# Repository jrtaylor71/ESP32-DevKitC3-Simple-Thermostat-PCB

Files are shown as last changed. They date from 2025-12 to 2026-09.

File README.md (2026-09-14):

# ESP32-S3-Simple-Thermostat

A comprehensive, feature-rich simple thermostat system built on the ESP32 platform with professional PCB design. Perfect for DIY smart home automation with full Home Assistant integration.

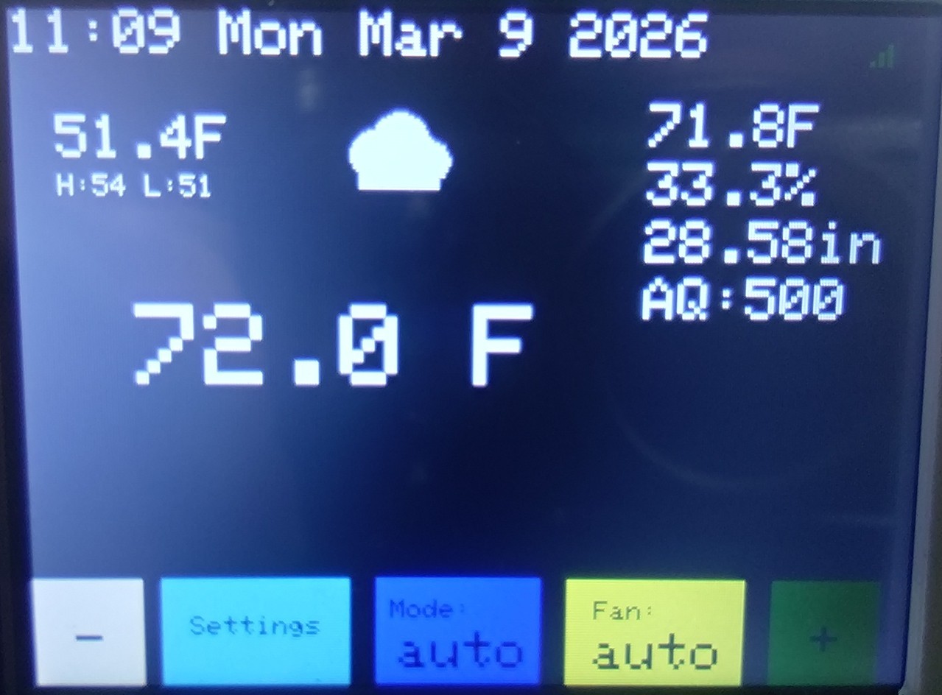
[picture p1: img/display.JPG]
Main-Display

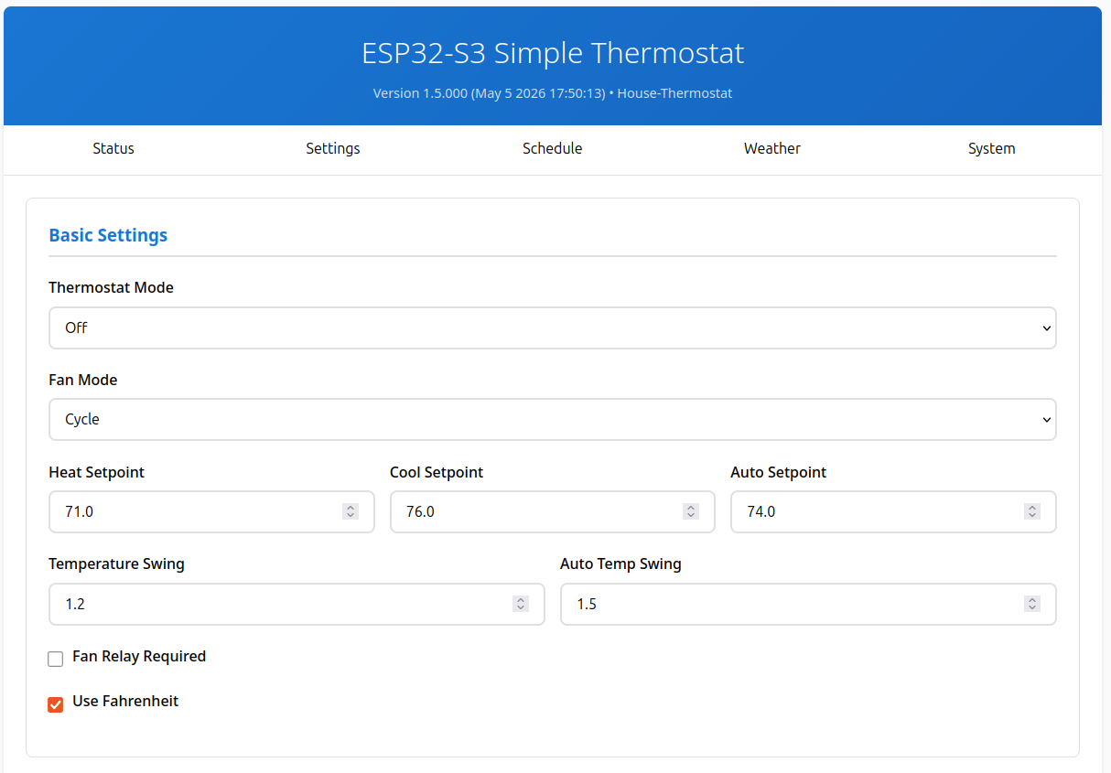
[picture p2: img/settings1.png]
Settings1

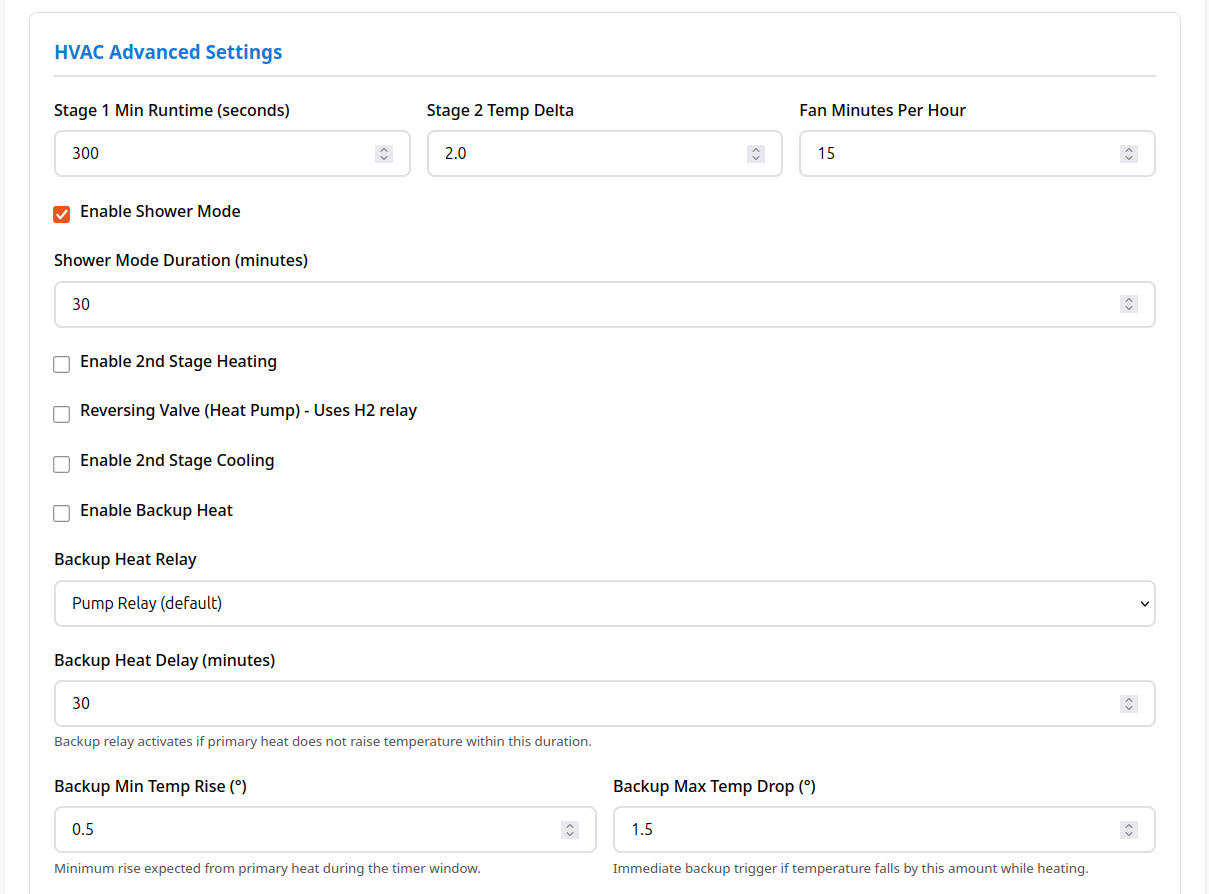
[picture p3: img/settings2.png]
Settings2

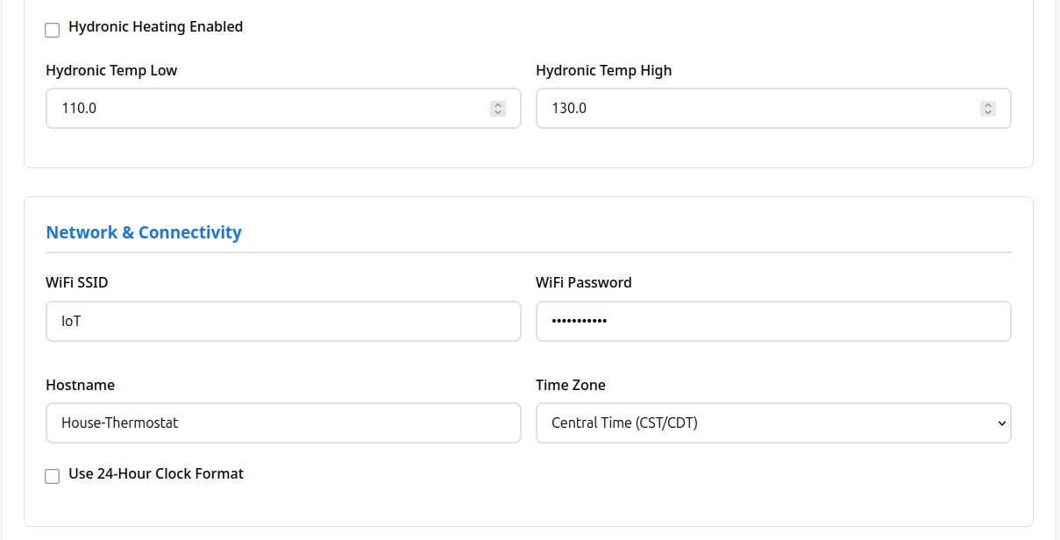
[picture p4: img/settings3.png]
Settings3

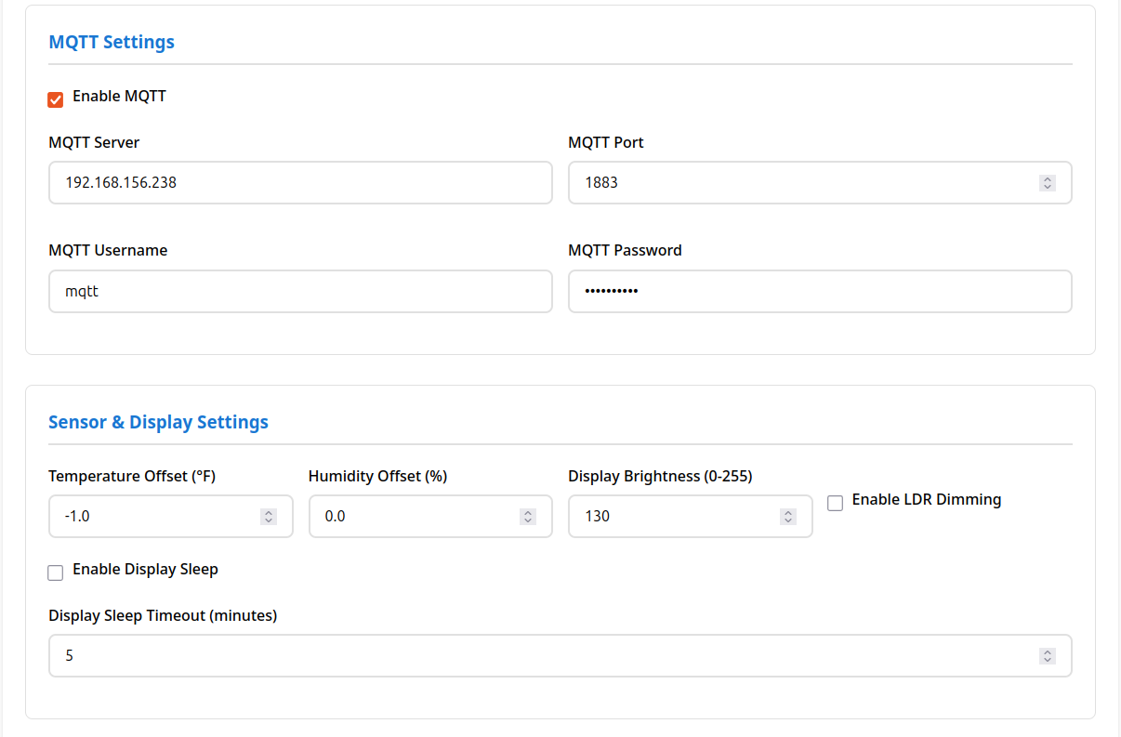
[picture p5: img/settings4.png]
Settings4


## 🌟 Key Features

- **📱 Local Touch Control**: ILI9341 TFT LCD with intuitive touch interface
- **🏠 Smart Home Ready**: Full MQTT integration with Home Assistant auto-discovery and climate entity support
- **📅 Bidirectional Schedule Sync**: 7-day schedules with day/night periods, HA helper automation, and live two-way update flow
- **🌡️ Multiple Sensors**: AHT20/BME280 ambient temperature and humidity plus DS18B20 hydronic water sensing
- **⚡ Multi-Stage HVAC**: Support for 2-stage heating and cooling, stage timing, delta thresholds, and stage 2 runtime logic
- **🌍 Regional HVAC Behavior**: Switchable US mode (standard temperature-driven cooling) or EU mode (adds optional humidity-driven dehumidification support alongside temperature control)
- **🔄 Heat Pump Ready**: Reversing valve support and heat-pump-compatible staging logic
- **🔥 Backup Heat Monitoring**: Auxiliary heat fallback logic with delay windows and temperature-drop detection
- **💨 Advanced Fan Control**: Auto, continuous, and scheduled cycling modes with independent heat/cool fan relay requirements
- **🔥 Separate Heat/Cool Fan Logic**: Configure whether the fan relay is needed for heating, cooling, or both for legacy HVAC systems
- **🧯 Hydronic Safety Protection**: DS18B20 water monitoring with lockout logic that blocks unsafe fan/heating operation and protects radiant systems
- **🚿 Shower Mode**: Pause heating for 5-120 minutes with countdown timer and buzzer alert
- **🌤️ Weather Integration**: OpenWeatherMap and Home Assistant weather with color-coded icons, current conditions, and display updates
- **🏢 Multi-Thermostat Support**: Scale from single-device installs to multi-device Home Assistant automation setups
- **🌐 Modern Web Interface**: Complete tabbed interface with embedded scheduling, status monitoring, OTA upload, and settings management
- **📡 Offline Operation**: Full functionality without WiFi connection or internet access
- **🔧 Professional PCB**: Custom PCB design for clean, permanent installation and compact integration
- **🔄 OTA Updates**: Over-the-air firmware updates with real-time progress tracking and reboot recovery
- **🔒 Factory Reset**: Built-in reset capability via boot button for clean default recovery
- **🎭 Motion Detection**: LD2410 24GHz mmWave sensor for automatic display wake and occupancy-aware screen behavior
- **🔊 Audible Alerts**: Buzzer feedback for shower mode, relay events, and user interaction cues
- **🧠 Reliability Features**: Watchdog reset, anti-flicker display refresh, I2C protection, and graceful sensor recovery

## �️ Operating Modes

### Thermostat Modes
- **Off**: All heating, cooling, and fan demand relays are disabled
- **Heat**: Single heat setpoint with configurable swing (hysteresis) to prevent short-cycling
- **Cool**: Single cool setpoint with configurable swing (hysteresis) to prevent short-cycling
- **Auto**: Single setpoint with a wider dead-zone swing; heating and cooling only activate once the temperature moves outside the dead-zone and turn off at the setpoint boundary rather than immediately on dead-zone re-entry

### Fan Modes
- **Auto**: Fan runs only when heating or cooling demand is active, based on the independent heat/cool fan relay requirement settings
- **On**: Fan runs continuously regardless of HVAC demand
- **Cycle**: Fan runs on a repeating schedule (configurable minutes per hour) even without active heating or cooling demand

### Regional HVAC Modes
- **US Mode**: Standard temperature-driven heating and cooling control
- **EU Mode**: Adds an optional humidity-driven dehumidification assist that runs alongside temperature control, using a configurable humidity setpoint, deadband, and dedicated relay selection

### Schedule Modes
- **Scheduled**: Setpoints automatically follow the active day/night period for the current day of week
- **Manual Override**: Adjusting a setpoint while a schedule is active temporarily overrides the schedule for a fixed duration before resuming normal scheduled behavior
- **Disabled**: Schedule following can be turned off entirely in favor of fixed manual setpoints

### Shower Mode
- Temporarily pauses heating for a configurable duration (5-120 minutes)
- Displays a live countdown timer on the touch screen while active
- Buzzer alert signals when the countdown is about to end
- Can be toggled directly from the touch screen setpoint control when enabled in settings

## �🚀 Quick Start

 - PCB V1.x
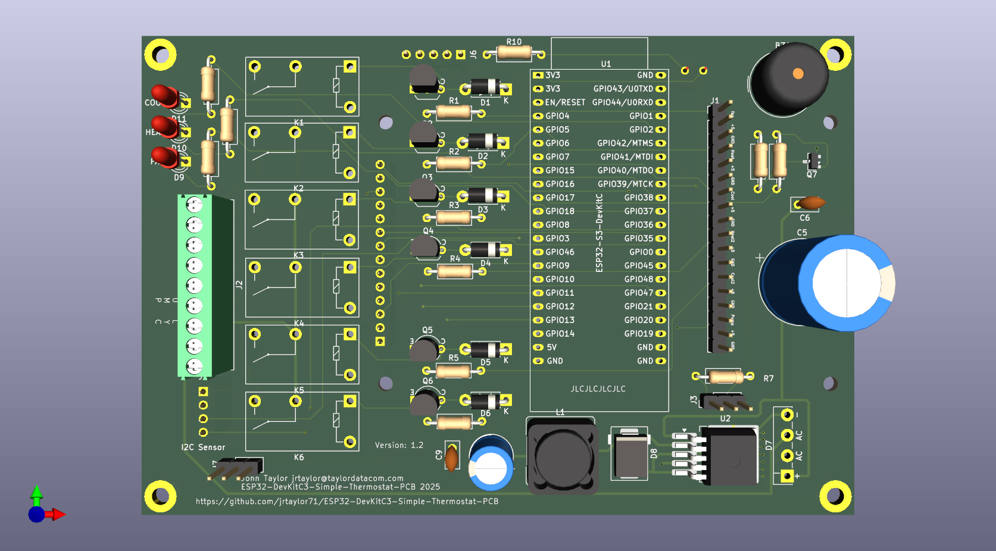
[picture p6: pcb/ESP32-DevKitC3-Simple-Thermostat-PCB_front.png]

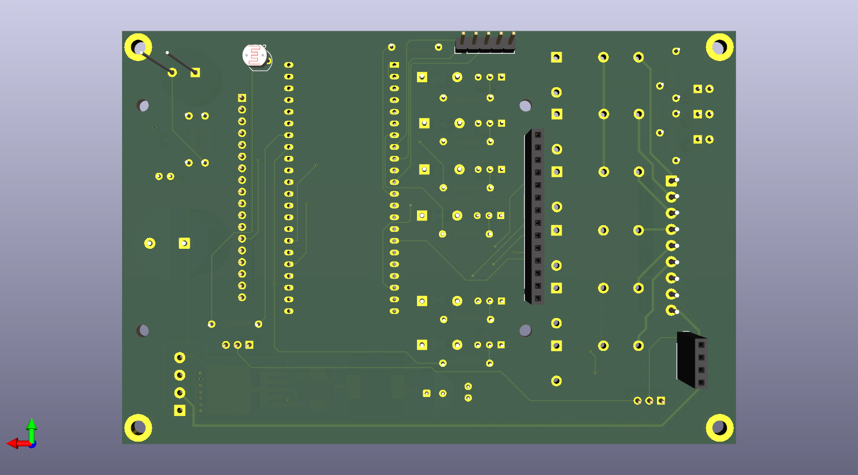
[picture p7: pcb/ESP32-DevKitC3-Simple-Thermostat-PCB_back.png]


 - PCB V3.x
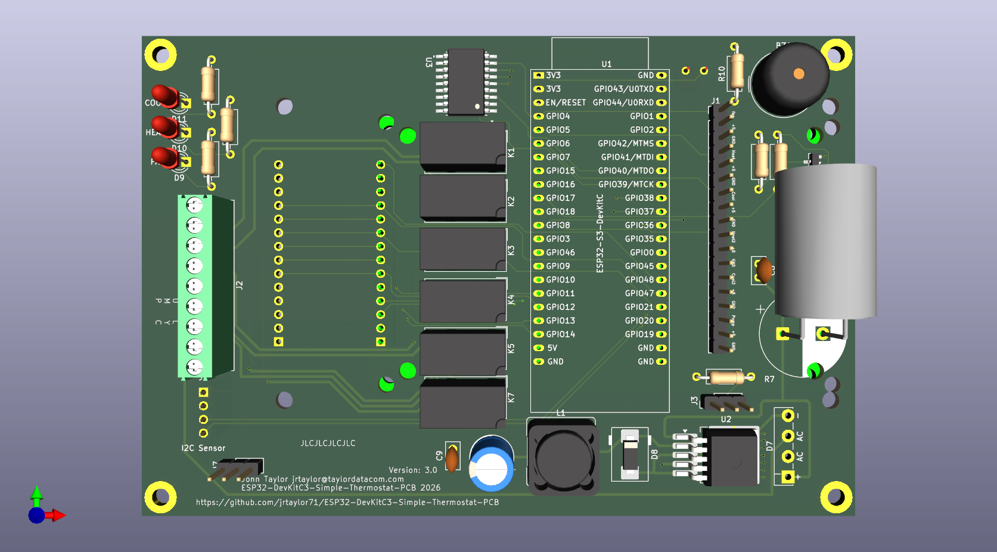
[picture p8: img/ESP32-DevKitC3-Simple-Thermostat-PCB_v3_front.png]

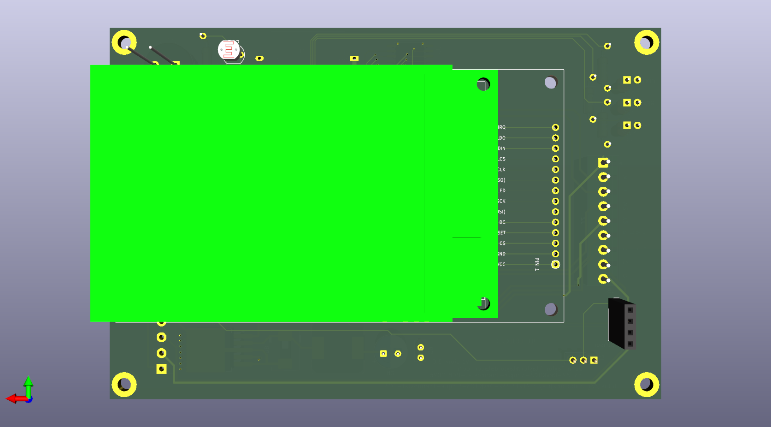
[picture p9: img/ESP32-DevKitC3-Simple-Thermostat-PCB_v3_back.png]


### Hardware Requirements
- ESP32-S3-WROOM-1-N16 (16MB Flash, No PSRAM) or N8/N32 variants
- ILI9341 320x240 TFT LCD with XPT2046 Touch Controller
- AHT20 or BME280 Temperature/Humidity Sensor (I2C)
- DS18B20 Temperature Sensor (optional, for hydronic heating)
- LD2410 24GHz mmWave Motion Sensor (optional, for display wake)
- 5x Relay Module for HVAC control
- Custom PCB that can use either onboard relay or external relays via pin header

### Software Setup

#### Option 1: Use Prebuilt Firmware (Recommended)
1. Clone this repository
2. Navigate to `firmware/` directory
3. Find the latest build folder (e.g., `build_YYYYMMDD-HHMMSS/`)
4. Flash using the variant-specific script:
   - **Linux/Mac**: 
     - Default: `./latest_flash_N16.sh` (uses /dev/ttyACM0)
     - Custom port: `./latest_flash_N16.sh /dev/ttyUSB0`
   - **Windows**: 
     - Default: `latest_flash_N16.bat` (uses COM3)
     - Custom port: `latest_flash_N16.bat COM4`
5. Use touch interface to configure WiFi and settings

#### Option 2: Build from Source
1. Install [PlatformIO](https://platformio.org/) IDE
2. Clone this repository
3. Open project in PlatformIO
4. Build firmware using `./build.sh` with options:
   - **Interactive mode**: `./build.sh` (select from menu)
   - **Specific variant**: `./build.sh 1` (N8), `./build.sh 2` (N16), or `./build.sh 3` (N32)
   - **All variants**: `./build.sh all` or `./build.sh 4`
   - **Additional flags**: `clean`, `quiet`, `cleanlibs`
   - **Examples**: 
     - `./build.sh 2` - Build 16MB variant (default)
     - `./build.sh all clean` - Clean build all variants
     - `./build.sh 3 quiet` - Build 32MB silently
     - `./build.sh cleanlibs` - Remove all libraries and packages
5. Memory usage: RAM 25.2% (82728/327680 bytes); Flash 19.0% (1246KB/6553KB for N16)
6. Firmware organized in `firmware/N8/`, `firmware/N16/`, `firmware/N32/` directories
7. Flash using variant-specific scripts:
   - **Linux/Mac**: 
     - Default: `./firmware/latest_flash_N16.sh` (uses /dev/ttyACM0)
     - Custom port: `./firmware/latest_flash_N16.sh /dev/ttyUSB0`
   - **Windows**: 
     - Default: `firmware\latest_flash_N16.bat` (uses COM3)
     - Custom port: `firmware\latest_flash_N16.bat COM5`
8. Use touch interface to configure WiFi and settings

#### Flashing Requirements
- **esptool.py** (installed automatically with PlatformIO)
- **USB connection** to ESP32-S3
- **Boot mode**: Hold BOOT button while connecting USB (if needed)
- **Default serial port**: `/dev/ttyACM0` (Linux/Mac) or `COM3` (Windows)

#### Manual Flashing with esptool

If you need to flash manually using esptool, use the following command:

**Linux/Mac:**
```bash
esptool.py --chip esp32s3 --port /dev/ttyACM0 --baud 460800 --before default_reset --after hard_reset write_flash -z \
    --flash_mode dio --flash_freq 80m --flash_size 16MB \
    0x0 bootloader.bin \
    0x8000 partitions.bin \
    0x10000 firmware.bin
```

**Windows:**
```bash
esptool.py --chip esp32s3 --port COM3 --baud 460800 --before default_reset --after hard_reset write_flash -z \
    --flash_mode dio --flash_freq 80m --flash_size 16MB \
    0x0 bootloader.bin \
    0x8000 partitions.bin \
    0x10000 firmware.bin
```

**Flash addresses for the 3 required files:**
- `bootloader.bin` at address `0x0`
- `partitions.bin` at address `0x8000`
- `firmware.bin` at address `0x10000`

**Adjust for your hardware:**
- Change `--port` to your serial port (Linux: `/dev/ttyACM0` or `/dev/ttyUSB0`, Windows: `COM3`, `COM4`, etc.)
- Change `--flash_size` to `8MB`, `16MB`, or `32MB` to match your ESP32-S3 variant (N8, N16, or N32)

For detailed build and flash instructions, see [USER_MANUAL.md](USER_MANUAL.md)

## 💻 Web Interface

Access the thermostat's web interface by navigating to its IP address:

### Tabbed Interface with Embedded Features

**Status Tab**: Real-time monitoring of:
- Current temperature and humidity
- Thermostat and fan modes
- Relay states and system status
- Weather information (when configured)
- Barometric pressure (with BME280 sensor)

**Settings Tab**: Complete configuration interface for:

- Temperature setpoints and control modes
- MQTT/Home Assistant integration and broker settings
- WiFi network settings and reboot recovery
- Multi-stage HVAC parameters including stage 2 runtime and delta thresholds
- Reversing valve configuration for heat-pump systems
- Backup heat enablement, relay selection, delay timing, and temperature-drop logic
- Hydronic heating controls with low/high water protection thresholds
- Fan scheduling options and independent heat/cool fan relay toggles
- Regional HVAC mode selection for US or EU behavior
- EU humidity dehumidification controls, relay selection, setpoint, and deadband
- Shower mode enable/disable and duration (5-120 minutes)
- Display brightness, sleep, and clock settings
- Temperature/humidity sensor calibration and offsets
- OTA update management and firmware details

**Schedule Tab**: Comprehensive 7-day scheduling:
- Day and night periods for each day of the week
- Editable Heat, Cool, and Auto temperatures for each period
- Time controls for period transitions
- Schedule enable/disable and override controls
- All options always visible - no hidden menus

**Weather Tab**: Weather data configuration:
- OpenWeatherMap API integration
- Home Assistant weather entity integration
- Configurable update intervals (5-60 minutes)
- City/state/country configuration

**System Tab**: Device information and firmware updates:
- System information and uptime
- Firmware version details
- OTA firmware upload with progress tracking
- Reboot and factory reset options

For complete usage instructions, see [USER_MANUAL.md](USER_MANUAL.md)

## 🏠 Home Assistant Integration

### Automatic Discovery & Control
Automatic discovery and integration with Home Assistant:

1. Enable MQTT in thermostat settings
2. Configure MQTT broker details
3. Thermostat appears automatically in Home Assistant with a full climate entity and status payloads
4. Full control via Home Assistant interface
5. Supports climate entity with heating, cooling, auto, and off modes
6. Publishes relay, mode, target, schedule override, and hydronic state for automation use

### Bidirectional Schedule Sync 🔄
Full synchronization between thermostat and Home Assistant:

**Device → HA (Inbound)**: 
- Thermostat publishes complete schedule on boot and config changes
- HA automations automatically update helper entities for each day and period
- Changes made on device instantly visible in HA

**HA → Device (Outbound)**:
- Change any schedule helper in HA (time, temperature, enabled status)
- Automation publishes change to device via MQTT immediately
- Device receives and applies change instantly
- No manual sync needed - fully automatic bidirectional flow

**Multi-Thermostat Support**:
- Each device gets its own set of helpers (shop_thermostat, studio_thermostat, house_thermostat, etc.)
- Centralized multi-device automation handles all thermostats
- Proper hostname normalization for MQTT topics vs. helper IDs
- Can manage 10+ thermostats from single HA instance

**Setup Instructions**:
1. Ensure MQTT is enabled on thermostat
2. Copy `multi_thermostat_schedule_sync.yaml` to HA packages directory
3. Generate per-device packages: `./generate_schedule_package.sh shop_thermostat`
4. Add package to HA configuration
5. Reload automations/scripts in HA
6. Helpers auto-populate from device schedule state

## 🛠️ Advanced Features

### Multi-Stage Operation
- Intelligent staging based on time and temperature
- Configurable stage 2 activation parameters and runtime thresholds
- Prevents system short-cycling and optimizes energy efficiency
- Supports separate heating and cooling stage logic for multi-stage HVAC systems
- Includes runtime gating and dead-zone control behavior for stable operation

### US/EU Regional HVAC Behavior
- Thermostat region mode can be configured for US or EU control behavior
- **US Mode**: Standard temperature-driven heating and cooling control
- **EU Mode**: Adds optional humidity-driven dehumidification assist that runs alongside temperature control, with configurable setpoint and deadband
- Standalone dehumidification state is surfaced to web status and TFT display
- Works with relay selection modes for cooling stage 1, stage 2, or pump relay output

### Heat Pump and Backup Heat Support
- Reversing valve support for heat-pump systems with mode-aware valve control
- Backup heat logic can monitor a primary heat source and automatically add auxiliary heat when recovery stalls or temperature falls too quickly
- Relay conflicts are automatically managed so backup heat does not overlap with reserved stage 2 or reversing valve outputs
- Works alongside standard heating and cooling staging without forcing a single control strategy

### Hydronic Heating Support
- DS18B20 water temperature monitoring
- Safety interlocks prevent operation when water is too cold
- Configurable high/low temperature thresholds
- Hydronic lockout logic blocks unsafe heating/fan behavior when the loop is below the configured minimum
- Perfect for radiant floor heating systems and hydronic boiler setups

### Fan Control Options
- **Auto**: Fan runs only with heating/cooling
- **On**: Continuous fan operation
- **Cycle**: Scheduled fan operation (configurable minutes per hour)
- **Independent Heat/Cool Relay Settings**: Choose whether a fan relay is required while heating, while cooling, or for both modes
- **Legacy HVAC Compatibility**: Supports systems where the fan is required for cooling only, heating only, or both without forcing a single global setting

### Display, Sensor, and Safety Enhancements
- Motion-based wake on LD2410 radar occupancy detection
- Display sleep and dimming support with activity sensing
- Buzzer feedback for alerts, boot tones, and mode transitions
- Watchdog protection, OTA recovery, and factory reset support
- AHT20/BME280 temperature/humidity calibration offsets and sensor error recovery
- I2C mutex protection to prevent bus contention between sensors and display logic
- Anti-flicker display refresh logic and stable UI updates
- Hydronic low-temp alert publishing and lockout recovery monitoring for radiant systems

### Included Hardware and Support Features
- 5 relay outputs for heating, cooling, and fan control
- Optional DS18B20 hydronic sensor and LD2410 motion sensor
- Local TFT UI with touch controls and embedded settings
- Web interface for complete configuration and status polling
- OTA firmware upload through the device’s system tab
- Compatibility with both single-device and multi-thermostat Home Assistant installations

## 🖨️ 3D Printable Case

A professional two-part case design is included for clean wall-mount installation:

### Case Features
- **Two-part screw-retained design**: Front (display side) and back (wall-mount side) halves
- **Integrated PCB mounting**: Built-in standoffs (13mm height) for secure PCB installation
- **Countersunk front screws**: 4× M2.5 countersunk (DIN 7991), 10–12mm length, 7mm inset
- **Keyhole wall mounting**: Easy installation without removing case (83mm spacing)
- **Display opening**: Precise 50mm × 68mm opening for 3.2" ILI9341 touchscreen (rotated 90°)
- **AHT20 sensor + LDR cutouts**: 12.5×6mm rectangle (rotated 90°) and Ø5.5mm hole
- **Wire management**: 22mm back pass-through plus side ventilation slots
- **Ventilation**: Strategically placed slots for optimal heat dissipation
- **Professional finish**: Smooth surfaces and rounded edges

### Files Included
- `case/freecad_front_case.py` - Front case (display side) FreeCAD Python script
- `case/freecad_back_case.py` - Back case (wall-mount side) FreeCAD Python script
- `case/freecad_outputs/front_case_display_freecad.stl` - Front half for 3D printing
- `case/freecad_outputs/back_case_wall_freecad.stl` - Back half for 3D printing
- `case/freecad_outputs/front_case_display_freecad.FCStd` - Front case FreeCAD project
- `case/freecad_outputs/back_case_wall_freecad.FCStd` - Back case FreeCAD project
- `case/freecad_outputs/front_case_display_freecad.step` - Front case STEP format
- `case/freecad_outputs/back_case_wall_freecad.step` - Back case STEP format
- `case/freecad_outputs/CE5_front_case_display_freecad.gcode` - Creality Ender 5 gcode (front)
- `case/freecad_outputs/CE5_back_case_wall_freecad.gcode` - Creality Ender 5 gcode (back)

### Print Specifications
- **Material**: PLA or PETG recommended
- **Layer height**: 0.2mm
- **Infill**: 15-20%
- **Supports**: None required
- **Print time**: ~7–9 hours total
- **Dimensions**: 149.0mm × 105.5mm × ~47mm (assembled)
  - Front: ~17.1mm (2.5mm wall; 13mm standoffs; front walls 1.6mm above standoffs)
  - Back: ~30.1mm (2.5mm wall; 20mm component clearance; bosses/keyholes)

**STL Files Location**: All printable STL files are in the `case/freecad_outputs/` directory.

### Motion Detection
- **LD2410 24GHz mmWave Sensor**: Automatic display wake on motion detection
- **Hardware Pins**: RX=15, TX=16, Motion=18
- **Robust Detection**: Works with sensors that don't respond to UART commands
- **Home Assistant Integration**: Motion sensor auto-discovery and status publishing
- **Energy Saving**: Display automatically sleeps when no motion detected
- **Seamless Operation**: Works alongside existing touch controls

### Safety Features
- Watchdog timer prevents system lockups
- Factory reset via boot button (10+ seconds)
- Temperature limit enforcement
- Graceful offline operation

## 🔧 Factory Reset

Press and hold the boot button for more than 10 seconds while the thermostat is running to restore all settings to defaults.

## 📄 License

This project is released under the GNU General Public License v3.0. Free to use, modify, and distribute. NOT for commercial use.

## 🤝 Contributing

Contributions welcome! Please:
1. Fork the repository
2. Create a feature branch
3. Make your changes
4. Submit a pull request

## 📞 Support

- **Issues**: Use GitHub Issues for bug reports
- **Discussions**: GitHub Discussions for questions
- **Documentation**: Comprehensive docs included
- **Serial Debug**: Detailed logging at 115200 baud

## 🙏 Credits & Acknowledgments

**Firmware**: Jonn Taylor - Enhanced firmware implementation

**Created for the DIY smart home community**

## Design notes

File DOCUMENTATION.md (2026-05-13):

# Firmware - Complete Documentation

## Project Overview

The Firmware is a comprehensive, feature-rich smart thermostat system built on the ESP32-S3 platform with professional PCB design.

**Current Version**: 1.5.001 (May 2026)
**Hardware**: ESP32-S3-WROOM-1-N16 (16MB Flash)
**Architecture**: Dual-core FreeRTOS with Option C display management
**Status**: Production-ready with comprehensive testing, scheduling, weather integration, US/EU regional HVAC options, and enhanced OTA updates

### Key Features

- **Professional Dual-Core Architecture**: ESP32-S3 FreeRTOS with Core 0 for UI/networking, Core 1 for control
- **Weather Integration**: Dual-source weather (OpenWeatherMap/Home Assistant) with color-coded standard icons
- **7-Day Scheduling System**: Complete inline scheduling with day/night periods, editable Heat/Cool/Auto temperatures, and MQTT integration
- **Modern Tabbed Web Interface**: All features embedded in main page - no separate pages, always-visible options
- **Local Touch Control**: ILI9341 TFT LCD with resistive touch and adaptive brightness
- **Smart Home Integration**: Full MQTT support with Home Assistant auto-discovery, precision temperature control, and schedule status publishing
- **Advanced Sensor Suite**: AHT20 I2C sensor for ambient conditions, DS18B20 OneWire for hydronic systems
- **Intelligent Multi-Stage HVAC**: 2-stage heating/cooling with hybrid time/temperature staging logic
- **US/EU Regional HVAC Controls**: Region mode switch with EU humidity-driven dehumidification support
- **Enhanced Hydronic Safety**: Water temperature monitoring with [LOCKOUT] safety interlocks and improved alerts
- **Flexible Operation Modes**: Heat, Cool, Auto, and Off with configurable temperature swings
- **Advanced Fan Control**: Auto, On, and Cycle modes with scheduled operation (minutes per hour)
- **Anti-Flicker Display**: Cached redraw optimization eliminates time and weather flicker
- **Comprehensive Web Interface**: Real-time monitoring and complete configuration in tabbed layout
- **Robust Offline Operation**: Full functionality without WiFi connection
- **Custom PCB Design**: Professional PCB by Stefan Meisner for clean installation
- **Modern UI**: Material Design color scheme with responsive touch interface
- **Factory Reset**: 10-second boot button press for complete settings reset
- **OTA Updates**: Over-the-air firmware updates with real-time upload and flash write progress tracking

## Hardware Components

### Main Components
- **ESP32-S3-WROOM-1-N16**: Main microcontroller (16MB Flash, No PSRAM)
- **ILI9341 TFT LCD with XPT2046**: 320x240 pixel display with resistive touch controller
- **AHT20 Sensor**: I2C temperature and humidity measurement  
- **DS18B20 Sensor**: OneWire water/hydronic temperature measurement (optional)
- **LD2410 Motion Sensor**: 24GHz mmWave radar for occupancy detection and display wake
- **5x Relay Outputs**: Control for heating, cooling, and fan systems

### Pin Configuration (ESP32-S3)

#### TFT Display Connections (ILI9341 + XPT2046)
```cpp
// Current platformio.ini build_flags configuration:
#define TFT_MISO 21    // SPI MISO (shared with touch)
#define TFT_MOSI 12    // SPI MOSI (shared with touch)
#define TFT_SCLK 13    // SPI Clock (shared with touch)  
#define TFT_CS    9    // TFT Chip Select
#define TFT_DC   11    // Data/Command
#define TFT_RST  10    // Reset
#define TFT_BL   14    // Backlight (PWM controlled)
#define TOUCH_CS 47    // Touch Chip Select
#define TOUCH_IRQ 48   // Touch Interrupt
```

#### Sensor Connections
```cpp
// AHT20 I2C sensor (ESP32-S3 pins)
#define AHT20_SDA 36        // I2C SDA for AHT20
#define AHT20_SCL 35        // I2C SCL for AHT20
// DS18B20 OneWire sensor
#define ONE_WIRE_BUS 34     // DS18B20 data pin
// Light sensor for adaptive brightness
#define LIGHT_SENSOR_PIN 8  // Photocell/light sensor
```

#### Relay Outputs (ESP32-S3 GPIO)
```cpp
// GPIO pins verified for ESP32-S3 schematic
const int heatRelay1Pin = 5;    // Heat Stage 1
const int heatRelay2Pin = 7;    // Heat Stage 2  
const int coolRelay1Pin = 6;    // Cool Stage 1
const int coolRelay2Pin = 39;   // Cool Stage 2
const int fanRelayPin = 4;      // Fan Control
```

#### Status LEDs and Buzzer
```cpp
// PWM-controlled status indicators
const int ledFanPin = 37;       // Fan status LED
const int ledHeatPin = 38;      // Heat status LED
const int ledCoolPin = 2;       // Cool status LED
const int buzzerPin = 17;       // Buzzer (5V through 2N7002 MOSFET)
```

#### Control Input
```cpp
#define BOOT_BUTTON 0       // Factory reset button
```

#### Motion Sensor (LD2410) - Optional
```cpp
#define LD2410_RX_PIN 15    // ESP32 RX (connect to LD2410 TX)
#define LD2410_TX_PIN 16    // ESP32 TX (connect to LD2410 RX) 
#define LD2410_MOTION_PIN 18 // Digital motion output pin
```

## Software Architecture

### Core Libraries
- **WiFi**: Network connectivity
- **ESPAsyncWebServer**: Web interface
- **PubSubClient**: MQTT communication
- **TFT_eSPI**: Display control
- **DHT sensor library**: Temperature/humidity reading
- **DallasTemperature**: DS18B20 sensor support
- **ArduinoJson**: JSON parsing for MQTT and weather APIs
- **HTTPClient**: Weather API requests (OpenWeatherMap)
- **Preferences**: Non-volatile settings storage
- **Weather Module**: Custom weather.h/weather.cpp for dual-source weather integration

### Main Functions

#### Display Management
- `updateDisplay()`: Updates LCD with current status
- `drawButtons()`: Renders touch interface buttons
- `handleButtonPress()`: Processes touch input
- `drawKeyboard()`: WiFi setup keyboard interface
- `wakeDisplay()`: Wake display from sleep on touch/motion
- `checkDisplaySleep()`: Automatic display sleep management

#### Motion Detection (LD2410)
- `testLD2410Connection()`: Verify motion sensor connectivity with robust detection
- `readMotionSensor()`: Read motion status, wake display, and publish MQTT status
- **Auto-Wake Display**: Display automatically wakes on motion detection
- **Robust Connection Logic**: Handles sensors that don't respond to UART commands
- **MQTT Integration**: Motion status published to Home Assistant with auto-discovery
- **Display Sleep Prevention**: Motion detection prevents display sleep timeout

#### HVAC Control
- `controlRelays()`: Main thermostat logic controller
- `activateHeating()`: Multi-stage heating control
- `activateCooling()`: Multi-stage cooling control
- `handleFanControl()`: Fan operation management
- `controlFanSchedule()`: Scheduled fan cycling

#### Communication
- `setupMQTT()`: MQTT client initialization
- `mqttCallback()`: Handles incoming MQTT commands
- `sendMQTTData()`: Publishes sensor data and status
- `publishHomeAssistantDiscovery()`: Auto-discovery setup
- `handleWebRequests()`: Web interface handlers

#### Configuration
- `saveSettings()`: Persistent storage of configuration
- `loadSettings()`: Startup configuration loading
- `restoreDefaultSettings()`: Factory reset functionality

## Operating Modes

### Thermostat Modes
1. **Off**: All HVAC equipment disabled (fan can still operate)
2. **Heat**: Heating-only operation with configurable setpoint
3. **Cool**: Cooling-only operation with configurable setpoint  
4. **Auto**: Automatic changeover between heating and cooling

### Regional Control Modes
- **US Mode**: Traditional temperature-driven cooling behavior.
- **EU Mode**: Optional humidity-driven dehumidification can call cooling based on RH thresholds.
- **EU Dehumidification Relay Selection**:
  - Cool Stage 1 relay
  - Cool Stage 2 relay
  - Pump relay

### Fan Modes
1. **Auto**: Fan runs only when heating/cooling is active
2. **On**: Fan runs continuously
3. **Cycle**: Fan runs for specified minutes per hour

### Advanced Features

#### Multi-Stage Operation
- **Stage 1 Priority**: Always starts with single-stage operation
- **Time-Based Staging**: Stage 2 activates after minimum runtime
- **Temperature-Based Staging**: Stage 2 activates based on temperature differential
- **Configurable Parameters**: Minimum runtime and temperature delta settings

#### Hydronic Heating Support
- **Water Temperature Monitoring**: DS18B20 sensor integration
- **Safety Interlocks**: Prevents operation when water temperature is too low
- **Configurable Thresholds**: High/low temperature setpoints

#### Temperature Control Logic
- **Hysteresis Control**: Prevents short cycling
- **Configurable Swing**: Adjustable temperature deadband
- **Auto Mode Logic**: Separate swing settings for auto changeover

## Web Interface

### Tabbed Interface Design
Modern single-page application with embedded tabs:

#### Status Tab
- Real-time temperature and humidity display
- Current relay states and system status
- Thermostat and fan mode indicators
- Hydronic temperature (if enabled)
- Auto-refresh every 10 seconds

#### Settings Tab
Comprehensive configuration including:
- Temperature setpoints for all modes
- Temperature swing settings
- Multi-stage configuration
- Hydronic heating parameters
- MQTT settings
- WiFi credentials
- Time zone and clock format
- Fan scheduling parameters

#### Weather Tab (New in v1.3.5)
Comprehensive weather configuration:
- **Weather Source Selection**: Choose between OpenWeatherMap, Home Assistant, or Disabled
- **OpenWeatherMap Settings**: API key, city, state (for US disambiguation), country code
- **Home Assistant Settings**: Server URL, bearer token, weather entity ID
- **Update Interval**: Configurable 5-60 minute refresh intervals
- **AJAX Form Submission**: Settings saved without page redirect
- **Conditional Sections**: Only show relevant settings for selected weather source

#### Schedule Tab (New in v1.1.0)
Complete 7-day scheduling system:
- **Weekly Schedule Table**: 7 days with day/night periods
- **Editable Temperatures**: Independent Heat, Cool, and Auto temperatures for each period
- **Time Controls**: Set day and night period start times
- **Per-Day Enable**: Individual day enable/disable toggles
- **Master Controls**: Schedule enable/disable and override options
- **Real-Time Status**: Current schedule state and active period display
- **Always Visible**: All options permanently displayed - no hidden menus
- **MQTT Integration**: Schedule status published to Home Assistant
- **Persistent Storage**: All schedule settings saved to preferences

#### System Tab
- Device information and system status
- Firmware version and hardware details
- OTA firmware update interface with real-time progress tracking
  - Upload progress bar with transfer speed and ETA
  - Flash write progress with percentage indication
  - Automatic reboot handling with status messages
  - Version verification after successful update
- System restart controls

### API Endpoints
- `/`: Main interface with embedded tabs
- `/schedule_set`: Schedule configuration processing (POST)
- `/status`: JSON API for current status
- `/control`: JSON API for remote control
- `/update`: OTA firmware update endpoint (POST)
- `/update_status`: Real-time OTA progress JSON endpoint
- `/version`: Firmware version JSON endpoint
- `/reboot`: System restart endpoint

## Weather Integration (v1.3.5)

### Weather Module Architecture

The weather system is implemented as a separate modular component:
- **include/Weather.h**: Interface definition with WeatherSource enum and WeatherData struct
- **src/Weather.cpp**: Implementation with dual API support and display rendering

### Weather Data Structure
```cpp
enum WeatherSource {
    WEATHER_DISABLED = 0,
    WEATHER_OPENWEATHERMAP = 1,
    WEATHER_HOMEASSISTANT = 2
};

struct WeatherData {
    float temperature;        // Current temperature
    float tempHigh;          // Daily high
    float tempLow;           // Daily low
    String condition;        // Short condition (e.g., "Clear")
    String description;      // Full description
    int humidity;            // Humidity percentage
    float windSpeed;         // Wind speed
    String iconCode;         // OWM standard icon code (01d-50n)
    bool valid;              // Data validity flag
    unsigned long lastUpdate; // Update timestamp
};
```

### Supported Weather Sources

#### OpenWeatherMap (Free Tier)
- **API Endpoint**: Current Weather Data API
- **Configuration**: API key, city, state (optional for US), country code
- **Features**: Standard OWM icon codes, temperature, conditions, humidity, wind speed
- **Update Mechanism**: HTTP GET with JSON parsing, URL-encoded city names
- **Icon Mapping**: 01=clear, 02=few clouds, 03/04=clouds, 09=shower, 10=rain, 11=storm, 13=snow, 50=mist

#### Home Assistant
- **API Endpoint**: REST API with entity state queries
- **Configuration**: Server URL, bearer token, weather entity ID
- **Features**: Direct integration with HA weather entities
- **Authentication**: Bearer token in Authorization header

### Display Integration

#### Weather Display Layout
- **Position**: Top-left at (5, 25) below time header
- **Temperature**: Large display at (x+10, y+10)
- **Weather Icon**: 36x36 pixels at (x+110, y) with color-coded rendering
- **High/Low**: Daily range at (x+10, y+30)

#### Color-Coded Weather Icons
Standard OpenWeatherMap icon codes with visual color mapping:
- **01 (Clear)**: Orange sun (0xFD20)
- **02 (Few Clouds)**: Gray clouds with sun (0xCE79)
- **03/04 (Clouds)**: Gray clouds (0xCE79)
- **09 (Shower)**: Blue rain drops (0x3D5F)
- **10 (Rain)**: Blue rain with cloud (0x3D5F)
- **11 (Thunderstorm)**: Yellow lightning (0xFC00)
- **13 (Snow)**: White snowflakes (0xFFFF)
- **50 (Mist)**: Gray fog lines (0xAD55)

#### Anti-Flicker Optimization
Weather display uses cached redraw to eliminate flicker:
- **Cache Variables**: `prevLastUpdate`, `prevUnitsF`, `prevX`, `prevY`
- **Redraw Trigger**: Only updates when weather data timestamp changes
- **Benefits**: Smooth display, reduced TFT bus traffic, better responsiveness

### Weather Update Logic

#### Forced First Update
- `_forceNextUpdate` flag set to `true` in constructor
- Bypasses interval check on first update attempt
- Ensures weather displays immediately after configuration

#### Interval-Based Updates
- Configurable 5-60 minute intervals
- Respects WiFi connectivity status
- Automatic retry on API failures with error logging

### Web Interface

#### Weather Tab Features
- **Weather Source Dropdown**: DISABLED / OpenWeatherMap / Home Assistant
- **Dynamic Sections**: JavaScript toggles visibility based on source selection
- **OpenWeatherMap Section**: 3-column grid layout (city 2fr, state 1fr, country 1fr)
- **AJAX Submission**: Form posts to `/set` endpoint without page redirect
- **Settings Persistence**: All weather settings saved to ESP32 preferences

### Settings Storage

Weather settings are stored in ESP32 NVS preferences:
- `weatherSrc`: Weather source (0=disabled, 1=OWM, 2=HA)
- `owmApiKey`: OpenWeatherMap API key
- `owmCity`: City name (URL-encoded for API calls)
- `owmState`: State/province (optional, for US city disambiguation)
- `owmCountry`: ISO country code (e.g., "US", "CA")
- `haUrl`: Home Assistant server URL
- `haToken`: HA long-lived access token
- `haEntityId`: HA weather entity ID
- `weatherInt`: Update interval in minutes (5-60)

### Factory Reset
Factory reset includes weather settings restoration:
- Weather source set to DISABLED
- All API keys, URLs, and tokens cleared
- Update interval reset to 30 minutes
- State field cleared

## 7-Day Scheduling System

### Schedule Structure
```cpp
struct SchedulePeriod {
    int hour;        // 0-23
    int minute;      // 0-59
    float heatTemp;  // Target heating temperature
    float coolTemp;  // Target cooling temperature
    float autoTemp;  // Target auto mode temperature
    bool active;     // Whether this period is enabled
};

struct DaySchedule {
    SchedulePeriod day;    // Day period (default 6:00 AM)
    SchedulePeriod night;  // Night period (default 10:00 PM)
    bool enabled;          // Whether scheduling is enabled for this day
};
```

### Schedule Features
- **7-Day Configuration**: Individual schedules for each day of the week
- **Day/Night Periods**: Two periods per day with independent temperature settings
- **Three Temperature Modes**: Separate Heat, Cool, and Auto temperatures for each period
- **Flexible Timing**: User-configurable start times for day and night periods
- **Override System**: Temporary (2-hour) or permanent override capabilities
- **MQTT Integration**: Schedule status and changes published to Home Assistant
- **Persistent Storage**: All settings saved to ESP32 preferences
- **Real-Time Application**: Schedule automatically applied based on current time

### Schedule Operation
1. **Time Check**: System checks current time every 30 seconds
2. **Period Detection**: Determines if current time is in day or night period
3. **Temperature Application**: Applies scheduled temperatures to thermostat setpoints
4. **MQTT Updates**: Publishes schedule status and active period
5. **Override Handling**: Manages temporary and permanent overrides
6. **Home Assistant Integration**: Schedule entities available in HA

### Default Schedule
- **Day Period**: 6:00 AM - Heat: 72°F, Cool: 76°F, Auto: 74°F
- **Night Period**: 10:00 PM - Heat: 68°F, Cool: 78°F, Auto: 73°F
- **All Days Enabled**: Default schedule active for all 7 days
- **Master Schedule**: Disabled by default (manual operation)

## MQTT Integration

### Home Assistant Auto-Discovery
Automatically configures Home Assistant with:
- Climate entity with full thermostat control
- Temperature and humidity sensors
- Mode and fan mode controls
- Real-time status updates

### MQTT Topics
#### Command Topics (Subscribed)
- `esp32_thermostat/mode/set`: Thermostat mode control
- `esp32_thermostat/fan_mode/set`: Fan mode control
- `esp32_thermostat/target_temperature/set`: Temperature setpoint

#### Status Topics (Published)
- `esp32_thermostat/current_temperature`: Current temperature
- `esp32_thermostat/current_humidity`: Current humidity
- `esp32_thermostat/target_temperature`: Current setpoint
- `esp32_thermostat/mode`: Current thermostat mode
- `esp32_thermostat/fan_mode`: Current fan mode
- `esp32_thermostat/availability`: Online/offline status

#### Schedule Topics (New in v1.1.0)
- `<hostname>/schedule_enabled`: Schedule master enable/disable status
- `<hostname>/active_period`: Current active period ("day", "night", "manual")
- `<hostname>/schedule_override`: Schedule override status
- Alert topics with improved hysteresis and non-retained delivery

#### Home Assistant Auto-Discovery
- Automatic climate entity creation with full thermostat control
- Schedule status sensors for monitoring active periods
- Temperature and humidity sensors with device information
- All entities grouped under single thermostat device

## Touch Interface

### Main Display Elements
- **Time Display**: Current time and day of week
- **Temperature/Humidity**: Right-side vertical display
- **Setpoint**: Large center display
- **Status Indicators**: Color-coded HEAT/COOL/FAN status
- **Control Buttons**: Bottom row for user interaction

### Button Layout
- **Minus (-)**: Decrease temperature setpoint
- **WiFi Setup**: Enter WiFi configuration mode
- **Mode**: Cycle through Off/Heat/Cool/Auto
- **Fan**: Cycle through Auto/On/Cycle modes
- **Plus (+)**: Increase temperature setpoint

### WiFi Setup Interface
- **On-screen Keyboard**: QWERTY layout for credentials
- **Case Toggle**: Uppercase/lowercase switching
- **Special Characters**: Numbers and symbols row
- **Clear/Delete**: Text editing functions

## PCB Design

### Professional Layout
The custom PCB provides:
- **Clean Integration**: All components on a single board
- **Proper Grounding**: Dedicated ground planes
- **Signal Integrity**: Proper trace routing and impedance
- **Connector Organization**: Labeled terminal blocks for easy wiring
- **Mounting Options**: Standard mounting holes for enclosure installation

### Manufacturing Files
Located in `ESP32-Simple-Thermostat-PCB/jlcpcb/`:
- **Gerber Files**: Manufacturing layer files
- **Drill Files**: Via and hole positioning
- **BOM**: Bill of Materials for component sourcing
- **CPL**: Component Placement List for assembly

## Installation and Setup

### Hardware Assembly
1. **PCB Assembly**: Solder all components per BOM
2. **Display Connection**: Wire TFT display per pin configuration
3. **Sensor Installation**: Mount DHT11 and DS18B20 sensors
4. **Relay Wiring**: Connect HVAC equipment to relay outputs
5. **Power Supply**: Provide stable 5V power to ESP32

### Software Installation
1. **PlatformIO Setup**: Install PlatformIO IDE
2. **Library Dependencies**: Auto-installed via platformio.ini
3. **Upload Firmware**: Compile and upload Main-Thermostat.cpp
4. **Initial Configuration**: Use touch interface for WiFi setup

### HVAC System Integration
1. **Safety First**: Turn off power to HVAC system
2. **Wire Identification**: Identify common, heating, cooling, and fan wires
3. **Relay Connection**: Connect HVAC wires to appropriate relay outputs
4. **Testing**: Verify proper operation before final installation

## Configuration

### Initial Setup
1. **Touch Calibration**: Automatic on first boot
2. **WiFi Configuration**: Use on-screen keyboard
3. **Temperature Units**: Fahrenheit/Celsius selection
4. **Time Zone**: Select from comprehensive list
5. **HVAC Type**: Configure staging and fan requirements

### MQTT Configuration
1. **Server Settings**: IP address and port
2. **Authentication**: Username and password
3. **Home Assistant**: Enable auto-discovery
4. **Testing**: Verify connectivity and control

### Advanced Settings
1. **Staging Parameters**: Runtime and temperature thresholds
2. **Hydronic Settings**: Enable and configure water temperature monitoring
3. **Fan Scheduling**: Set cycle time and frequency
4. **Temperature Swings**: Fine-tune hysteresis for comfort

## Troubleshooting

### Common Issues

#### WiFi Connection Problems
- **Symptom**: Cannot connect to WiFi
- **Solution**: 
  - Verify SSID and password accuracy
  - Check signal strength at installation location
  - Ensure 2.4GHz network (ESP32 doesn't support 5GHz)
  - Use WiFi setup button to reconfigure

#### Touch Screen Unresponsive
- **Symptom**: Touch input not working
- **Solution**:
  - Check display connections
  - Verify touch screen calibration
  - Ensure proper grounding
  - Reboot system to recalibrate

#### MQTT Connection Failures
- **Symptom**: No Home Assistant integration
- **Solution**:
  - Verify MQTT broker is running
  - Check network connectivity
  - Validate MQTT credentials
  - Confirm port accessibility (usually 1883)

#### Temperature Reading Issues
- **Symptom**: Invalid or missing temperature readings
- **Solution**:
  - Check DHT11 sensor connections
  - Verify sensor power supply
  - Replace sensor if readings remain invalid
  - Check for electromagnetic interference

#### Relay Control Problems
- **Symptom**: HVAC equipment not responding
- **Solution**:
  - Verify relay connections and power
  - Check HVAC wire connections
  - Test relays manually through web interface
  - Ensure proper common wire connection

### Factory Reset
- **Method**: Hold boot button for 10+ seconds while system is running
- **Result**: All settings restored to defaults
- **Recovery**: System will reboot and require reconfiguration

## Maintenance

### Regular Maintenance
- **Sensor Cleaning**: Keep DHT11 sensor free of dust and debris
- **Display Care**: Clean touch screen with soft, dry cloth
- **Connection Check**: Periodically verify all wire connections
- **Software Updates**: Check for firmware updates via OTA interface

### Monitoring
- **Web Interface**: Regular status checks via web browser
- **Serial Output**: Debug information available via USB serial
- **MQTT Logs**: Monitor Home Assistant logs for communication issues
- **Temperature Trends**: Track heating/cooling efficiency over time

## Safety Considerations

### Electrical Safety
- **Power Disconnection**: Always disconnect HVAC power before wiring
- **Proper Grounding**: Ensure all components are properly grounded
- **Overcurrent Protection**: Use appropriate fuses/breakers
- **Professional Installation**: Consider professional installation for complex systems

### System Safety
- **Backup Thermostat**: Keep manual thermostat as backup
- **Failure Modes**: System defaults to safe off mode on errors
- **Temperature Limits**: Built-in minimum/maximum temperature limits
- **Watchdog Timer**: Automatic system reset on software failures

## Development and Customization

### Code Structure
- **Modular Design**: Functions organized by purpose
- **Configuration Management**: Centralized settings storage
- **Error Handling**: Comprehensive error checking and recovery
- **Debug Output**: Extensive serial logging for troubleshooting

### Customization Options
- **Temperature Limits**: Modify min/max temperature ranges
- **Display Layout**: Customize screen appearance and layout
- **Additional Sensors**: Add support for more sensor types
- **Custom MQTT Topics**: Modify topic structure for specific needs
- **Web Interface**: Add custom web pages and functionality

### Extension Possibilities
- **Weather Integration**: Add outdoor temperature compensation
- **Scheduling**: Implement time-based temperature schedules
- **Energy Monitoring**: Add power consumption tracking
- **Additional Zones**: Support for multiple zone control
- **Mobile App**: Develop companion mobile application

## Support and Resources

### Documentation
- This comprehensive documentation
- Inline code comments
- PlatformIO library documentation
- ESP32 technical reference

### Troubleshooting Resources
- Serial debug output
- Web interface status pages
- MQTT debug topics
- Home Assistant entity states

### Community Support
- GitHub issues for bug reports
- Community forums for general questions
- Documentation updates and improvements
- Feature requests and enhancements

## Version History

### Version 1.3.5 (Current - December 2025)
- **Weather Integration**: Modular Weather.h/Weather.cpp with dual-source support
- **OpenWeatherMap Support**: Free API integration with city, state, country configuration
- **Home Assistant Weather**: Direct HA weather entity integration via REST API
- **Weather Display**: Color-coded standard OWM icons (36x36) with temperature and conditions
- **Weather Web Tab**: Dedicated configuration tab with AJAX form submission
- **Anti-Flicker Optimization**: Cached redraw for time and weather display elements
- **Enhanced Time Display**: Format "HH:MM Weekday Mon D YYYY" with flicker elimination
- **Weather Settings Storage**: Complete settings persistence with state field for US cities
- **URL Encoding**: Proper handling of city names with spaces and special characters
- **Icon Color Coding**: Weather-appropriate colors (orange sun, blue rain, white snow, etc.)

### Version 1.3.0 (November 2025)
- **Enhanced OTA Update System**: Real-time progress tracking for firmware uploads
- **Flash Write Progress**: Visual feedback during flash write operations with percentage updates
- **Improved OTA User Experience**: Integrated OTA interface in System tab with clear status messages
- **Optimized Reboot Timing**: Proper response transmission before device restart
- **Version Verification**: Automatic firmware version confirmation after successful update
- **Code Cleanup**: Removed redundant standalone update page, streamlined codebase

### Version 1.2.4 (November 2025)
- **OTA Progress Improvements**: Added upload progress bar and flash write tracking
- **Enhanced Status Messages**: Clear indication of update stages
- **Reboot Timing Fix**: Improved timing to prevent connection error messages

### Version 1.1.0 (November 2025)
- **7-Day Scheduling System**: Complete inline scheduling with day/night periods and editable Heat/Cool/Auto temperatures
- **Modern Tabbed Web Interface**: All features embedded in main page - Status, Settings, Schedule, and System tabs
- **Enhanced Schedule Features**: Per-day enable/disable, time controls, override system, and MQTT integration
- **MQTT Alert Improvements**: Non-retained alerts with hysteresis-based reset logic for better Home Assistant integration
- **Hydronic Safety Enhancements**: [LOCKOUT] labels replacing [SAFETY] for clearer system status indication
- **Schedule MQTT Integration**: Real-time schedule status publishing to Home Assistant with device grouping
- **Persistent Schedule Storage**: All schedule settings saved to ESP32 preferences with automatic loading
- **Auto Temperature Control**: Independent user-editable auto temperatures for each schedule period
- **Inline Interface Design**: No separate pages - all functionality embedded in tabbed main interface
- **Always-Visible Options**: All schedule controls permanently displayed without hidden menus

### Version 1.0.8 (November 2025)
- **ESP32-S3-WROOM-1-N16 Platform**: Optimized for 16MB flash with default_16mb.csv partition
- **Dual-Core FreeRTOS Architecture**: Core 0 for UI/network, Core 1 for sensors/control
- **Option C Centralized Display Management**: Mutex-protected display updates with task coordination
- **Modern Material Design UI**: Enhanced color scheme with improved readability
- **Advanced Multi-Stage HVAC**: Hybrid time/temperature staging with configurable parameters
- **Comprehensive MQTT Integration**: Home Assistant auto-discovery with temperature precision
- **Hydronic Heating Support**: DS18B20 water temperature monitoring with safety interlocks
- **Adaptive Display Brightness**: Light sensor integration with PWM backlight control
- **Factory Reset Capability**: 10-second boot button press for complete settings reset
- **Professional PCB Integration**: Full compatibility with Stefan Meisner's hardware design
- **Robust Error Handling**: Watchdog timer, graceful offline operation, comprehensive logging
- **Touch Interface Optimization**: Maximum responsiveness with keyboard support for WiFi setup
- **OTA Update Support**: Web-based firmware updates
- **Production-Ready Stability**: Extensive testing and optimization for 24/7 operation

### Previous Versions
- **1.0.7**: Material Design colors, ESP32-S3-WROOM-1-N16 optimization
- **1.0.6**: Visual improvements and UI enhancements
- **1.0.5**: Option C display system implementation
- **1.0.4**: HVAC logic working, stable baseline
- **1.0.3**: Initial multi-stage HVAC support
- **1.0.2**: Basic thermostat functionality
- **1.0.1**: Initial ESP32-S3 port
- **1.0.0**: Original ESP32 implementation

## License

This project is released under the GNU General Public License v3.0. You are free to use, modify, and distribute this software according to the terms of the GPL v3.0 license.

## Conclusion

The Firmware represents a complete, professional-grade smart thermostat solution. With its combination of local control, smart home integration, and advanced HVAC features, it provides a cost-effective alternative to commercial smart thermostats while offering superior customization and control options.

The addition of the custom PCB elevates this from a prototype to a production-ready solution suitable for permanent installation in residential and commercial environments.

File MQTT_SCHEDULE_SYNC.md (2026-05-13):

# MQTT Schedule Synchronization Guide

**Version 1.5.001 | May 2026**

Complete documentation for bidirectional MQTT schedule synchronization between ESP32 thermostats and Home Assistant.

---

## Table of Contents

1. [Overview](#overview)
2. [Architecture](#architecture)
3. [MQTT Topics & Payloads](#mqtt-topics--payloads)
4. [Setup Instructions](#setup-instructions)
5. [Troubleshooting](#troubleshooting)
6. [Advanced Configuration](#advanced-configuration)

---

## Overview

The thermostat system implements **bidirectional schedule synchronization** with Home Assistant:

- **Device → HA (Inbound)**: Device publishes schedule state to MQTT, HA automations create/update helpers
- **HA → Device (Outbound)**: Changing HA helpers triggers automations that send MQTT commands to device
- **Multi-Device Support**: Single automation handles unlimited thermostats
- **Zero Conflicts**: Proper hostname normalization prevents helper ID collisions
- **Automatic Generation**: Scripts generate all 77 automations and helpers per device

### Key Benefits

✅ **Zero Manual Sync**: Changes automatically sync bidirectionally  
✅ **Full HA Control**: Edit schedules in HA interface  
✅ **Device Control**: Changes on device auto-update in HA  
✅ **Scalable**: Add as many thermostats as needed  
✅ **Fault Tolerant**: No circular updates or conflicts  

---

## Architecture

### System Overview

```
┌─────────────────────────────────────────────────────────────┐
│                   Home Assistant                             │
│  ┌──────────────┐              ┌──────────────────┐         │
│  │   77 x3      │              │  Multi-Thermostat│         │
│  │  Helpers     │◄───────┬────►│  Schedule Sync   │         │
│  │ per device   │        │     │  Automation (1)  │         │
│  └──────────────┘        │     └──────────────────┘         │
│        ▲                 │              ▲                    │
│        │                 │              │                    │
│   77 outbound      1 centralized   Condition               │
│ automations per    inbound for all Check: valid day,│
│   thermostat         devices        host, payload    │
└────────┼──────────────────┼───────────────────────────────┘
         │                  │
      [MQTT]            [MQTT]
         │                  │
┌────────▼──────────────────▼────────────────────────────────┐
│                    MQTT Broker                              │
│                                                              │
│  {hostname}/schedule/set ◄──────────────────────────┐      │
│  {hostname}/schedule/{day} ────────────────────────►│      │
│                                                      │      │
└──────────────────────────┬───────────────────────────┘
                           │
                      [Inbound]
                       [Outbound]
                           │
                ┌──────────▼────────────┐
                │   ESP32 Thermostat   │
                │  weekSchedule[7]     │
                │  Parse JSON payloads │
                │  Publish state       │
                └─────────────────────┘
```

### Data Flow

#### 1. Device Startup → HA

1. Device boots and connects to MQTT broker
2. Device publishes complete schedule to 7 topics: `/schedule/sunday` through `/schedule/saturday`
3. HA inbound automation triggers for each topic
4. Automation creates or updates all 77 helpers with current device state
5. User sees helpers in HA with correct values

#### 2. User Changes Helper in HA → Device

1. User changes `input_datetime.shop_thermostat_friday_day_time` to 07:00
2. Outbound automation triggers (state changed)
3. Automation publishes to `Shop-Thermostat/schedule/set`:
   ```json
   {"day": 4, "period": "day", "hour": 7, "minute": 0}
   ```
4. Device receives and updates `weekSchedule[5].day.hour = 7` (day=5 is Friday in array)
5. Device saves to flash
6. Device publishes updated state to `/schedule/friday`
7. Inbound automation updates HA helpers to match device
8. No feedback loop - safe bidirectional sync

#### 3. User Changes Device Schedule → HA Updates

1. User touches device screen and changes Friday morning to 7:00
2. Device updates `weekSchedule` array
3. Device saves to flash
4. Device publishes `{hostname}/schedule/friday` with new state
5. HA inbound automation receives and updates all Friday helpers
6. HA UI reflects new schedule
7. Users see changes immediately

---

## MQTT Topics & Payloads

### Device → HA (State Topics)

#### Schedule State Topics (Inbound)

**Topic Pattern**: `{hostname}/schedule/{day_name}`

**Example**: 
- `Shop-Thermostat/schedule/monday`
- `Shop-Thermostat/schedule/friday`
- `Studio-Thermostat/schedule/sunday`

**Payload Format**:
```json
{
  "day_index": 0,
  "day_name": "Monday",
  "is_today": false,
  "schedule_enabled": false,
  "day_enabled": true,
  "day_period": {
    "time": "6:00",
    "heat": 72.0,
    "cool": 76.0,
    "auto": 74.0,
    "active": true
  },
  "night_period": {
    "time": "22:00",
    "heat": 68.0,
    "cool": 78.0,
    "auto": 73.0,
    "active": true
  }
}
```

**Field Descriptions**:
- `day_index`: 0=Monday through 6=Sunday (MQTT format)
- `day_name`: Display name of the day
- `is_today`: True if this is the current day
- `schedule_enabled`: Master schedule enable flag
- `day_enabled`: Enable flag for this specific day
- `day_period.time`: Start time in "HH:MM" format (24-hour)
- `day_period.heat`: Heating temperature setpoint
- `day_period.cool`: Cooling temperature setpoint
- `day_period.auto`: Auto mode temperature setpoint
- `day_period.active`: Whether day period is active

**Publish Frequency**: On boot, on configuration change, on schedule update via MQTT

**Retained**: False (fresh updates only)

### HA → Device (Command Topics)

#### Schedule Set Command Topic (Outbound)

**Topic**: `{hostname}/schedule/set`

**Example**:
- `Shop-Thermostat/schedule/set`
- `Studio-Thermostat/schedule/set`

**Payload Format** (minimal - only changed fields):
```json
{"day": 4, "period": "day", "hour": 7, "minute": 0}
```

**All Possible Fields**:
```json
{
  "day": 0-6,
  "period": "day" | "night",
  "hour": 0-23,
  "minute": 0-59,
  "heat": float,
  "cool": float,
  "auto": float,
  "active": true | false,
  "enabled": true | false
}
```

**Field Descriptions**:
- `day`: 0=Monday, 1=Tuesday, ..., 6=Sunday (MQTT format)
- `period`: "day" or "night"
- `hour`: Hour (24-hour format)
- `minute`: Minute
- `heat`: Heating setpoint (only include if changing)
- `cool`: Cooling setpoint (only include if changing)
- `auto`: Auto mode setpoint (only include if changing)
- `active`: Whether period is active (only include if changing)
- `enabled`: Whether day is enabled (only include if changing)

**Example Payloads**:

Change Friday morning time to 7:00:
```json
{"day": 4, "period": "day", "hour": 7, "minute": 0}
```

Change Friday morning heat temperature to 75:
```json
{"day": 4, "period": "day", "heat": 75}
```

Disable Monday:
```json
{"day": 0, "enabled": false}
```

Enable Tuesday night period:
```json
{"day": 1, "period": "night", "active": true}
```

### MQTT Hostname Format

**Device Publishes As**: `{hostname}` (capitalized, hyphenated)
- Example: `Shop-Thermostat`, `Studio-Thermostat`, `House-Thermostat`

**Helper IDs Use**: `{hostname_lowercase}` (lowercase, underscored)
- Example: `shop_thermostat`, `studio_thermostat`, `house_thermostat`

**Generated Automations**: Use MQTT hostname in topic, helper IDs in services

---

## Setup Instructions

### Prerequisites

- MQTT broker running and accessible to both HA and thermostat
- Thermostat on same network as HA and MQTT broker
- HA with automations enabled
- Git access to generate scripts

### Step 1: Enable MQTT on Thermostat

1. Access thermostat web interface
2. Go to Settings → MQTT tab
3. Enable MQTT checkbox
4. Enter MQTT broker IP address
5. Enter port (default 1883)
6. Enter optional username/password
7. Click "Save All Settings"
8. Verify "MQTT" shows connected status on main display

### Step 2: Prepare Home Assistant

1. Locate HA packages directory:
   ```bash
   # Typical paths:
   /config/packages/           # Docker
   ~/.homeassistant/packages/  # Native install
   /usr/share/hassio/config/packages/  # HassIO
   ```

2. Copy HA automation files:
   ```bash
   cp multi_thermostat_schedule_sync.yaml /path/to/HA/packages/
   ```

### Step 3: Generate Per-Device Packages

For each thermostat, generate the schedule package:

```bash
cd /home/jonnt/Documents/ESP32-DevKitC3-Simple-Thermostat-PCB

# For your thermostats:
./generate_schedule_package.sh shop_thermostat
./generate_schedule_package.sh studio_thermostat
./generate_schedule_package.sh house_thermostat
```

This creates:
- `shop_thermostat_schedule.yaml` (77 automations + 77 helpers)
- `studio_thermostat_schedule.yaml` (another 77 automations + 77 helpers)
- etc.

Copy generated files to HA packages directory:
```bash
cp *_schedule.yaml /path/to/HA/packages/
```

### Step 4: Add to HA Configuration

In `configuration.yaml`:
```yaml
homeassistant:
  packages:
    multi_thermostat_sync: !include packages/multi_thermostat_schedule_sync.yaml
    shop_thermostat_schedule: !include packages/shop_thermostat_schedule.yaml
    studio_thermostat_schedule: !include packages/studio_thermostat_schedule.yaml
    house_thermostat_schedule: !include packages/house_thermostat_schedule.yaml
```

### Step 5: Reload in Home Assistant

1. Go to Developer Tools > YAML
2. Click "Reload Automations"
3. Wait for success message
4. Restart Home Assistant (or use Developer Tools > Services > homeassistant.restart)

### Step 6: Verify Setup

1. Go to Settings > Devices & Services > Helpers
2. Search for thermostat hostname (e.g., "shop_thermostat")
3. Verify 77 helpers appear:
   - 14 `input_datetime` (day/night times × 7 days)
   - 42 `input_number` (heat/cool/auto × day/night × 7 days)
   - 21 `input_boolean` (enabled × day/night+day × 7 days)

4. Check helper values match device schedule
5. Try changing one helper and verify device updates within 1-2 seconds

---

## Troubleshooting

### Helpers Not Appearing

**Problem**: After setup, helpers don't appear in HA

**Solutions**:
1. Verify MQTT is connected:
   - Check thermostat display for MQTT icon (should show cloud)
   - Check Settings tab for "MQTT Connected" status

2. Check automations loaded:
   - Go to Settings > Automations & Scenes > Automations
   - Search for "Schedule - Sync All Thermostats from MQTT"
   - If missing, reload automations again

3. Verify MQTT topics:
   - Use MQTT client to monitor `+/schedule/+` wildcard
   - Device should publish to `/schedule/monday`, `/schedule/tuesday`, etc.
   - Check payload is valid JSON

4. Check HA logs:
   - Settings > System > Logs
   - Look for automation errors
   - Check for JSON parsing issues

**Debug Steps**:
```bash
# Monitor MQTT topics
mosquitto_sub -h <broker_ip> -t "+/schedule/+" -v

# Should show:
# Shop-Thermostat/schedule/monday {...json...}
# Shop-Thermostat/schedule/tuesday {...json...}
# etc.
```

### Changes Not Syncing Device → HA

**Problem**: Device schedule changes, but HA helpers don't update

**Solutions**:
1. Verify device is publishing:
   - Monitor MQTT: `mosquitto_sub -h <broker_ip> -t "+/schedule/+" -v`
   - Make change on device
   - Check if topic receives update

2. Verify automation is running:
   - Add test helper to automation
   - Check if it updates when publishing to MQTT manually

3. Check automation condition:
   - Edit automation in HA UI
   - Verify hostname is in whitelist (shop_thermostat, studio_thermostat)
   - Verify day name is valid (monday...sunday)

### Changes Not Syncing HA → Device

**Problem**: Changing HA helper doesn't update device schedule

**Solutions**:
1. Verify outbound automation exists:
   - Go to Settings > Automations & Scenes > Automations
   - Search for the specific helper (e.g., "Friday Morning Time Changed")
   - If missing, regenerate package

2. Verify automation is enabled:
   - Click automation to view
   - Check toggle is "On" (not disabled)

3. Monitor MQTT:
   - Change helper in HA
   - Watch MQTT for publish to `{hostname}/schedule/set`
   - If no publish, automation didn't trigger

4. Check device payload:
   - Monitor device logs (115200 baud via serial)
   - Look for "SCHEDULE: Via MQTT, updated day X period Y"
   - Check if day value is correct

### Circular Updates / Feedback Loop

**Problem**: Changes keep bouncing between device and HA

**This should not happen!** The system is designed to prevent this:
- Outbound automation publishes once when helper changes
- Inbound automation publishes once when device state changes
- No feedback loop because changes stabilize after 1-2 seconds

**If happening, check**:
1. Only ONE copy of `multi_thermostat_schedule_sync.yaml` loaded
2. No duplicate outbound automations for same helper
3. MQTT QoS is 0 (not 1 or 2)
4. No manual automations publishing to schedule topics

### Day Off-by-One Errors

**Problem**: Changing Friday updates Thursday, or vice versa

**This is fixed in v1.4.001!** Day index conversion is now correct:
- MQTT format: 0=Monday, 1=Tuesday, ..., 6=Sunday
- Device array: 0=Sunday, 1=Monday, ..., 6=Saturday
- Conversion: `arrayDay = (mqttDay + 1) % 7`

**Verify fix is applied**:
1. Firmware version should be v1.4.001 or later (check System tab)
2. If older, rebuild and flash latest firmware
3. Test: change Friday helper, verify Friday updates on device

### Wrong Device Responding

**Problem**: Change in HA updates wrong thermostat

**Cause**: Usually hostname mismatch between MQTT topic and HA helpers

**Fix**:
1. Check thermostat hostname:
   - Device web interface Settings > General
   - Top of main display shows IP and hostname
   - MQTT discovery message includes hostname

2. Verify hostname format:
   - Helper IDs: lowercase_with_underscores
   - MQTT topics: CamelCase-With-Hyphens
   - Device name: shown on display/web interface

3. Regenerate package with correct hostname:
   ```bash
   ./generate_schedule_package.sh <exact_hostname>
   ```

---

## Advanced Configuration

### Adding New Thermostat

To add a new thermostat to existing setup:

1. Set thermostat hostname (web interface > Settings)
2. Enable MQTT and connect
3. Verify it appears in MQTT topics
4. Generate schedule package:
   ```bash
   ./generate_schedule_package.sh new_thermostat_name
   ```
5. Copy generated YAML to HA packages
6. Add to `configuration.yaml`:
   ```yaml
   homeassistant:
     packages:
       new_thermostat_schedule: !include packages/new_thermostat_name_schedule.yaml
   ```
7. Reload automations in HA
8. Verify helpers appear

### Customizing Automation Names

Edit `template_thermostat_schedule.yaml` before generating packages:

```yaml
# Before:
- alias: "Thermostat - {{ dayname }} Morning Time Changed"

# After (custom):
- alias: "{{ hostname | title }} - {{ dayname }} Morning Schedule Time"
```

Then regenerate packages.

### Integration with Automations

Use schedule helpers in your own automations:

```yaml
# Example: Notify when schedule changes
automation:
  - alias: "Notify on Schedule Change"
    trigger:
      platform: state
      entity_id:
        - input_datetime.shop_thermostat_monday_day_time
        - input_datetime.shop_thermostat_friday_night_time
    action:
      service: notify.mobile_app
      data:
        message: "Schedule changed: {{ state_attr(trigger.entity_id, 'friendly_name') }}"
```

### MQTT Topic Monitoring

Monitor all schedule activity:

```bash
# All schedule topics
mosquitto_sub -h broker.ip -t "+/schedule/+" -v

# Specific thermostat
mosquitto_sub -h broker.ip -t "Shop-Thermostat/schedule/#" -v

# Only set commands (inbound to device)
mosquitto_sub -h broker.ip -t "+/schedule/set" -v
```

---

## Version History

### v1.4.001 (January 2026)
- ✅ Fixed day index off-by-one bug (MQTT 0=Monday vs firmware 0=Sunday)
- ✅ Multi-thermostat support with hostname normalization
- ✅ 77 outbound automations per device
- ✅ Centralized inbound automation for all devices
- ✅ Complete bidirectional sync
- ✅ Automatic helper generation via script

### v1.3.9 and earlier
- 7-day scheduling system in firmware
- MQTT discovery for climate entity
- Web interface schedule tab
- Initial MQTT implementation

---

## References

- **Firmware Code**: [Main-Thermostat.cpp](src/Main-Thermostat.cpp#L2960) - Schedule MQTT handler
- **Inbound Automation**: [multi_thermostat_schedule_sync.yaml](multi_thermostat_schedule_sync.yaml)
- **Outbound Template**: [template_thermostat_schedule.yaml](template_thermostat_schedule.yaml)
- **Generator Script**: [generate_schedule_package.sh](generate_schedule_package.sh)

---

**Last Updated**: January 2026  
**Author**: Thermostat Development Team  
**License**: GNU General Public License v3.0

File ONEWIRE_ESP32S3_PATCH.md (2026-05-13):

# OneWire Library ESP32-S3 GPIO41 Patch

Compatibility note (May 2026): This patch guidance remains applicable for firmware v1.5.001 builds using OneWire on ESP32-S3 GPIO pins above 33.

## Issue

The OneWire library v2.3.7 has a hard-coded limitation that prevents GPIO pins above 33 from being used as outputs:

```cpp
if ( digitalPinIsValid(pin) && pin <= 33 ) // pins above 33 can be only inputs
```

This is correct for the **original ESP32**, which only supports outputs on GPIO0-33. However, **ESP32-S3, ESP32-S2, ESP32-C3, and ESP32-C6** support GPIO outputs up to pin 48.

This limitation prevents using GPIO41 (and other pins > 33) for OneWire communication, which requires bidirectional operation.

## Symptoms

- DS18B20 temperature sensors not detected on GPIO41
- `oneWire->reset()` returns 0 (no device present) despite manual GPIO reset working correctly
- OneWire protocol initialization appears to work, but device search fails

## Root Cause

The `directModeOutput()` function in `.pio/libdeps/*/OneWire/util/OneWire_direct_gpio.h` rejects all pin numbers > 33, preventing the OneWire library from switching GPIO41 between input and output modes during communication.

## Solution

The patch modifies `OneWire_direct_gpio.h` to:

1. Detect ESP32 variant at compile time using `CONFIG_IDF_TARGET_*` macros
2. Set `maxOutputPin = 48` for ESP32-S3/S2/C3/C6
3. Set `maxOutputPin = 33` for original ESP32
4. Update the pin validation check to use the variant-specific limit

## Applying the Patch

### Automatic (During Build)

The patch is automatically applied by the build system when compiling. No manual action needed.

### Manual Application

If you need to apply the patch manually:

```bash
./patch_onewire_esp32s3.sh
```

This script will:
- Find all OneWire library installations in `.pio/libdeps/`
- Check if they're already patched
- Apply the patch to unpatched files
- Create backups (`.backup` extension)

## Patched Code

**Before:**
```cpp
if ( digitalPinIsValid(pin) && pin <= 33 ) // pins above 33 can be only inputs
{
    // ... enable output mode ...
}
```

**After:**
```cpp
// ESP32-S3/S2/C3 support outputs on pins > 33, original ESP32 only up to 33
#if defined(CONFIG_IDF_TARGET_ESP32S3) || defined(CONFIG_IDF_TARGET_ESP32S2) || defined(CONFIG_IDF_TARGET_ESP32C3) || defined(CONFIG_IDF_TARGET_ESP32C6)
    const uint8_t maxOutputPin = 48;  // ESP32-S3/S2/C3/C6 support GPIO outputs up to pin 48
#else
    const uint8_t maxOutputPin = 33;  // Original ESP32 only supports outputs up to pin 33
#endif

if ( digitalPinIsValid(pin) && pin <= maxOutputPin )
{
    // ... enable output mode ...
}
```

## Additional Required Changes

Beyond the OneWire library patch, GPIO41 on ESP32-S3 requires disabling the USB Serial JTAG peripheral:

```cpp
// Disable USB Serial JTAG to reclaim GPIO41/42
REG_WRITE(RTC_CNTL_USB_CONF_REG, 0);

// Configure GPIO41 for OneWire (open-drain with pullup)
esp_rom_gpio_pad_select_gpio(41);
PIN_FUNC_SELECT(GPIO_PIN_MUX_REG[41], PIN_FUNC_GPIO);
gpio_set_direction(GPIO_NUM_41, GPIO_MODE_INPUT_OUTPUT_OD);
gpio_set_pull_mode(GPIO_NUM_41, GPIO_PULLUP_ONLY);
gpio_pullup_en(GPIO_NUM_41);
```

See `src/Main-Thermostat.cpp` lines 1450-1510 for the complete initialization sequence.

## Verification

After patching and building:

```
Initializing DS18B20 sensors on GPIO41...
GPIO41 level after USB JTAG disable: 1 (should be 1 with pullup)
OneWire bus reset test: presence = 0 (0=device present, 1=no device)
Creating OneWire objects AFTER GPIO41 configuration...
Re-forcing GPIO41 configuration after OneWire::begin()...
GPIO41 level after OneWire init: 1 (should be 1)
Performing manual OneWire device search...
  Search attempt 1...
    Reset result: 1 (should be 1 for device present)
  Device 1 ROM: 28 XX XX XX XX XX XX XX
    CRC valid
    Device is DS18B20
  Device 2 ROM: 28 XX XX XX XX XX XX XX
    CRC valid
    Device is DS18B20
Manual search found 2 device(s)
DS18B20 device count: 2
DS18B20 readings: Supply=24.8°C, Return=24.6°C
```

## Version

- **Introduced:** v1.4.012
- **Date:** March 8, 2026
- **Affected Library:** OneWire v2.3.7
- **Platforms:** ESP32-S3, ESP32-S2, ESP32-C3, ESP32-C6

## Reporting Upstream

This patch should be submitted to the OneWire library maintainers:
- Repository: https://github.com/PaulStoffregen/OneWire
- Issue: ESP32-S3/S2/C3/C6 GPIO pins > 33 cannot be used for OneWire

## License

This patch maintains compatibility with the OneWire library's MIT License.

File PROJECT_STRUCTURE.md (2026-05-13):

# ESP32-DevKitC3-Simple-Thermostat-PCB - Project Structure

This document provides an overview of the project structure and organization for the ESP32-S3 based thermostat firmware project.

## Current Documentation Baseline (May 2026)
- Firmware track: v1.5.001.
- Includes US/EU regional HVAC mode and EU humidity dehumidification options.
- Includes OFF-mode display behavior fix for upper-right current/setpoint values.

## 📁 Project Directory Structure

```
Smart-Thermostat-Alt-Firmware/
├── 📄 README.md                          # Project overview and quick start guide
├── 📄 DOCUMENTATION.md                   # Comprehensive technical documentation
├── 📄 DEVELOPMENT_GUIDE.md               # Developer guide and best practices
├── 📄 PROJECT_STRUCTURE.md              # This file - project organization guide
├── 📄 platformio.ini                    # PlatformIO build configuration
├── 📄 Smart-Thermostat-Alt-Firmware.code-workspace # VS Code workspace settings
├── 📄 Thermostat-sch.pdf                # Hardware schematic reference
│
├── 📁 src/                              # Source code directory
│   ├── 📄 Main-Thermostat.cpp          # Main application source (3640+ lines)
│   └── 📄 Weather.cpp                  # Weather module implementation with dual API support
│
├── 📁 include/                          # Header files directory
│   ├── 📄 TFT_Setup_ESP32_S3_Thermostat.h # TFT display configuration (legacy)
│   ├── 📄 Weather.h                     # Weather module interface with WeatherSource enum
│   ├── 📄 WebInterface.h                # Modern web interface CSS, icons, and JavaScript
│   └── 📄 WebPages.h                    # HTML page generation functions
│
├── 📁 lib/                              # Custom library configurations
│   └── 📁 TFT_eSPI_Setup/
│       └── 📄 User_Setup.h              # Custom TFT_eSPI configuration (legacy)
│
├── 📁 .pio/                             # PlatformIO build files (auto-generated)
│   ├── 📁 build/esp32-s3-wroom-1-n16/  # Build artifacts
│   └── 📁 libdeps/esp32-s3-wroom-1-n16/ # Library dependencies
│
├── 📁 .vscode/                          # VS Code configuration
│   ├── 📄 extensions.json              # Recommended extensions
│   └── 📄 settings.json                # Project settings
│
└── 📁 img/                              # Project images and screenshots
    ├── 📄 web-status.png                # Web interface status page
    ├── 📄 web-settings.png              # Web interface settings page
    └── 📄 *.png                         # Additional project images
```

## 📋 File Descriptions

### Core Project Files

#### `README.md`
- Project overview and introduction
- Quick start guide and setup instructions
- Key features and capabilities overview
- Hardware requirements and pin configurations
- Web interface screenshots
- Home Assistant integration guide

#### `DOCUMENTATION.md`
- Comprehensive technical documentation
- Detailed architecture explanation
- Complete function reference
- Hardware integration guide
- Troubleshooting and maintenance
- Development and customization guide

#### `DEVELOPMENT_GUIDE.md`
- Developer guide and best practices
- ESP32-S3 specific development guidelines
- Dual-core FreeRTOS programming patterns
- TFT_eSPI configuration for custom hardware
- Build system configuration and optimization

#### `platformio.ini`
- PlatformIO build configuration for ESP32-S3-WROOM-1-N16
- Library dependencies with specific versions
- Build flags for TFT_eSPI hardware pin configuration
- Partition scheme: default_16mb.csv for maximum application space
- Serial monitor settings and upload configuration

#### `Thermostat-sch.pdf`
- Hardware schematic reference document
- Complete circuit design and component specifications
- Pin assignments for ESP32-S3-WROOM-1-N16
- Relay control circuits and sensor connections

### Source Code Architecture

#### `src/Main-Thermostat.cpp` (3640+ lines)
- Single comprehensive source file containing complete thermostat implementation with 7-day scheduling, LD2410 motion detection, and weather integration
- Organized into logical function groups with clear separation of concerns
- **Version**: 1.3.5 with advanced ESP32-S3 dual-core architecture, scheduling system, motion sensor integration, and weather display

#### `src/Weather.cpp`
- Weather module implementation with dual API support (OpenWeatherMap and Home Assistant)
- OpenWeatherMap integration with URL-encoded city names, state field for US disambiguation
- Home Assistant REST API integration with Bearer token authentication
- Color-coded weather icon rendering with standard OWM icon codes (01-50)
- Anti-flicker display optimization with cached redraw logic
- WeatherData struct with temperature, conditions, humidity, wind, and icon code

**Code Organization:**
- **Lines 1-50**: Header, license, and hardware credits
- **Lines 51-200**: Constants, pin definitions, and hardware configuration (including LD2410 pins)
- **Lines 201-300**: Global variables, system state, scheduling structures, and motion sensor variables
- **Lines 301-400**: Function prototypes organized by category (including schedule and motion sensor functions)
- **Lines 401-650**: Setup, initialization, schedule loading, and LD2410 initialization functions
- **Lines 651-850**: Main loop with non-blocking task scheduling, schedule checking, and motion detection
- **Lines 851-1000**: Dual-core FreeRTOS task functions
- **Lines 1001-1600**: Display management (Option C centralized approach with motion wake)
- **Lines 1601-2300**: HVAC control logic with multi-stage support and schedule application
- **Lines 2301-2900**: Communication systems (MQTT, WiFi, web server with schedule routes and motion sensor discovery)
- **Lines 2901-3200**: Settings management, schedule persistence, and preferences
- **Lines 3201-3400**: Motion sensor functions (testLD2410Connection, readMotionSensor)
- **Lines 3401-3640+**: Utility functions and hardware abstraction

#### `include/Weather.h`
- Weather module interface definition with WeatherSource enum (DISABLED, OPENWEATHERMAP, HOMEASSISTANT)
- WeatherData struct with temperature, high/low, conditions, humidity, wind speed, icon code
- Weather class with dual API configuration methods and display integration
- Public methods: begin(), setSource(), setOpenWeatherMapConfig(), setHomeAssistantConfig(), update(), displayOnTFT()
- Private members: API credentials, update intervals, cached weather data, last error tracking

### Web Interface Architecture

#### `include/WebInterface.h`
- Modern Material Design CSS framework
- SVG icon library for consistent UI elements
- JavaScript for dynamic functionality and tab management
- Responsive design supporting desktop and mobile devices
- Auto-refresh capabilities for real-time status updates

#### `include/WebPages.h`
- HTML page generation functions using modern templates with tabbed interface
- `generateStatusPage()`: Real-time system status with embedded Settings, Schedule, and System tabs
- **Schedule Tab Integration**: Complete 7-day scheduling interface embedded in main page
- **Schedule Data Structures**: `SchedulePeriod` and `DaySchedule` structs for comprehensive scheduling
- `generateSettingsPage()`: Standalone comprehensive configuration interface (legacy)
- `generateFactoryResetPage()`: System reset confirmation
- `generateOTAPage()`: Over-the-air firmware update interface
- Responsive design with always-visible schedule options and no hidden menus

### Configuration Files

#### `include/TFT_Setup_ESP32_S3_Thermostat.h` (Legacy)
- Legacy TFT display configuration file (unused in current build)
- Superseded by build flags in platformio.ini
- Kept for reference and potential future modularization

#### `lib/TFT_eSPI_Setup/User_Setup.h` (Legacy)
- Custom TFT_eSPI configuration (unused in current build)
- Hardware-specific pin definitions and display settings
- Replaced by platformio.ini build flags for better integration

**Active Configuration**: Display settings now managed via build flags in `platformio.ini`:
```ini
build_flags = 
    -DUSER_SETUP_LOADED=1
    -DILI9341_DRIVER=1
    -DTFT_MISO=37
    -DTFT_MOSI=35
    -DTFT_SCLK=36
    # ... additional pin definitions
```

### Documentation Images

#### Web Interface Screenshots
- `web-status.png`: Real-time status monitoring page showing current system state
- `web-settings.png`: Configuration interface page for thermostat settings
- Additional screenshots showing various system states and interface modes

## 🔧 Development Workflow

### Getting Started
1. **Clone Repository**: `git clone <repository-url>`
2. **Open in PlatformIO**: Load project in VS Code with PlatformIO extension
3. **Install Dependencies**: PlatformIO automatically installs libraries from `platformio.ini`
4. **Build Project**: PlatformIO Build (Ctrl+Alt+B) 
5. **Upload Firmware**: PlatformIO Upload (Ctrl+Alt+U) to ESP32-S3

### Development Tools
- **Primary IDE**: VS Code with PlatformIO extension
- **Target Platform**: ESP32-S3-WROOM-1-N16 (16MB Flash, No PSRAM)
- **Version Control**: Git (GitHub repository)
- **Serial Monitor**: PlatformIO Serial Monitor (115200 baud)
- **MQTT Testing**: MQTT.fx, MQTT Explorer, or Home Assistant
- **Web Interface**: Built-in web server for configuration and monitoring

### Code Organization Strategy
- **Single Source File**: Simplifies deployment and compilation (3096 lines)
- **Dual-Core Architecture**: FreeRTOS tasks on Core 0 (UI) and Core 1 (sensors/control)
- **Function Grouping**: Related functions organized together with clear separation
- **Thread Safety**: Mutex-protected shared resources and display management
- **Extensive Logging**: Serial debug output throughout for troubleshooting
- **Modular Functions**: Each major feature in dedicated functions for maintainability

## 📚 Learning Resources

### Understanding the Codebase
1. **Start with `README.md`**: Get project overview and setup
2. **Review `DOCUMENTATION.md`**: Understand ESP32-S3 architecture and features
3. **Study `DEVELOPMENT_GUIDE.md`**: Learn development patterns and best practices
4. **Examine `Main-Thermostat.cpp`**: Follow code organization and dual-core logic flow

### Key Code Sections to Study
1. **`setup()` Function**: ESP32-S3 initialization sequence and hardware setup
2. **`loop()` Function**: Main task scheduling and non-blocking state management
3. **FreeRTOS Tasks**: `sensorTaskFunction()` and `displayUpdateTaskFunction()`
4. **`controlRelays()`**: Core thermostat control logic with multi-stage support
5. **`updateDisplay()`**: Centralized display management (Option C approach)
6. **MQTT Functions**: Home Assistant auto-discovery and integration

### ESP32-S3 Specific Learning
1. **Dual-Core Programming**: Study FreeRTOS task implementation
2. **Pin Configuration**: Review platformio.ini build flags for hardware setup
3. **Memory Management**: 16MB Flash partition usage and optimization
4. **Display Integration**: TFT_eSPI configuration for ILI9341 with XPT2046 touch

## 🚀 Extension Points

### Code Extensibility
- **Additional Sensors**: Add support for more sensor types (BME280, SHT30)
- **New Display Elements**: Extend UI with weather information, graphs
- **Enhanced MQTT**: Add more Home Assistant entities and sensors
- **Data Logging**: Add historical data collection to SD card or cloud
- **Energy Monitoring**: Track HVAC runtime and energy usage

### Hardware Extensions
- **Outdoor Temperature**: Weather compensation with external sensor
- **Multiple Zones**: Support for multi-zone HVAC systems (additional relays)
- **Touch Improvements**: Upgrade to capacitive touch for better response
- **Wireless Sensors**: ESP-NOW for remote temperature sensors
- **Display Upgrades**: Larger TFT displays or e-ink for low power

### ESP32-S3 Specific Enhancements
- **USB Support**: Native USB for programming and debugging
- **WiFi 6**: Utilize advanced WiFi capabilities
- **Additional GPIO**: Leverage ESP32-S3's expanded I/O capabilities
- **Crypto Acceleration**: Use hardware crypto for secure communications
- **Machine Learning**: TinyML for predictive temperature control

## 🔍 Troubleshooting File Locations

### Debug Information Sources
- **Serial Output**: Connect to ESP32-S3 USB port at 115200 baud
- **Web Interface**: Status page shows real-time system state at `http://<IP>/`
- **MQTT Topics**: Monitor published topics for Home Assistant communication
- **Preferences Storage**: Settings stored in ESP32-S3 flash memory (NVS)
- **Build Output**: Check `.pio/build/esp32-s3-wroom-1-n16/` for compilation details

### Common Issues and Solutions
- **Compilation Errors**: Check `platformio.ini` library versions and build flags
- **Upload Failures**: Verify ESP32-S3 connection, drivers, and boot mode
- **Display Problems**: Review build flags for TFT_eSPI pin configuration
- **Memory Issues**: Monitor flash usage (currently 30.3% of 16MB)
- **FreeRTOS Crashes**: Check stack sizes and inter-task communication
- **MQTT Connection**: Verify WiFi credentials and broker settings

### Performance Monitoring
- **Flash Usage**: Current build uses ~3.14MB of 16MB available
- **RAM Usage**: Monitor heap free space via serial output
- **Task Performance**: Dual-core load balancing between UI and control tasks
- **MQTT Response**: Home Assistant auto-discovery and command processing

## 📊 Current Project Status

### Version Information
- **Firmware Version**: 1.3.5 (December 2025)
- **Platform**: ESP32-S3-WROOM-1-N16 (16MB Flash, No PSRAM)
- **Code Size**: 3640+ lines of production-ready C++ with comprehensive scheduling and weather integration
- **Flash Utilization**: 18.5% (1,210,272 bytes - plenty of room for expansion)

### Key Features Implemented
- **Weather Integration**: Modular Weather.h/Weather.cpp with dual-source support (OpenWeatherMap and Home Assistant)
- **Weather Display**: Color-coded standard OWM icons with temperature, conditions, and high/low on TFT
- **Anti-Flicker Display**: Cached redraw optimization for time and weather elements
- **7-Day Scheduling System**: Complete inline scheduling with day/night periods and editable Heat/Cool/Auto temperatures
- **LD2410 Motion Sensor Integration**: 24GHz mmWave radar with automatic display wake and robust detection logic
- **Modern Tabbed Web Interface**: All features embedded in main page including Weather tab - no separate pages, always-visible options
- **Dual-Core Architecture**: Core 0 (UI/Network), Core 1 (Sensors/Control)
- **Material Design UI**: Modern, responsive touch interface with scheduling and weather integration
- **Enhanced Home Assistant Integration**: MQTT auto-discovery with schedule status publishing, motion sensor entities, and comprehensive device grouping
- **Multi-Stage HVAC**: Advanced heating/cooling with staging support and schedule integration
- **Schedule MQTT Integration**: Real-time schedule status and override control via MQTT
- **Motion-Based Display Wake**: Automatic display wake on motion detection with seamless touch integration
- **Comprehensive Web Configuration**: Tabbed interface with Status, Settings, Schedule, Weather, and System tabs
- **Persistent Schedule Storage**: All schedule settings saved to NVS with automatic loading
- **Enhanced Safety Features**: Improved hydronic [LOCKOUT] system, watchdog timers, and sensor validation

This project structure provides a robust foundation for both learning and extending the ESP32-S3 Smart Thermostat system. The single-file architecture maintains simplicity while the dual-core FreeRTOS implementation ensures professional-grade performance and reliability.

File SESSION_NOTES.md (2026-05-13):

# Smart Thermostat Session Notes

## Session: May 13, 2026 - Regional HVAC + Documentation Refresh

### Session Summary
- Added US/EU thermostat region mode and EU humidity dehumidification controls.
- Added EU dehumidification active indicators in web status and TFT sidebar.
- Fixed OFF-mode display bug so upper-right display continues showing current temp and setpoint.
- Updated project documentation set and refreshed session handoff.

### Firmware Notes
- EU defaults remain aligned to requested standard profile:
  - Humidity setpoint: 60%
  - Humidity deadband: 5%

### Validation
- Build task `PlatformIO: Build & Organize Firmware` completed successfully for active firmware environments.

## Session: November 29, 2025 - Motion Wake & I2C Crash Fix

### Session Summary
Critical stability fix addressing system crashes and implementing reliable motion wake functionality. Root cause was I2C bus contention between sensor task and other operations.

### Starting State
- **Version**: 1.2.1
- **Commit**: v1.2.2 tag (motion wake implemented but system crashing after 5-10 minutes)
- **Issues**: 
  - System crashes with LoadProhibited exception at corrupted memory addresses
  - Motion wake working but system unstable
  - LD2410 radar concurrent access causing library corruption

### Problems Identified

#### 1. I2C Bus Contention (ROOT CAUSE)
- **Crash Location**: `Adafruit_I2CDevice::write()` at line 105 in Adafruit BusIO
- **Address**: EXCVADDR: 0xf3f4f5f6 (corrupted memory pattern)
- **Core**: Core 1 panic (sensor task)
- **Backtrace**: 
  ```
  #0  0x4208e028 in Adafruit_I2CDevice::write()
  #1  0x42017867 in Adafruit_AHTX0::getEvent()
  #2  0x4200f4bc in sensorTaskFunction() at src/Main-Thermostat.cpp:394
  ```

**Root Cause**: Multiple tasks accessing I2C bus (Wire) simultaneously without synchronization:
- Sensor task (Core 1) reading AHT20 sensor
- Display/touch operations potentially using I2C
- No mutex protection on shared I2C bus

#### 2. LD2410 Radar Concurrent Access
- **Previous Issue**: Both `checkDisplaySleep()` and `readMotionSensor()` calling `radar.check()`
- **Problem**: LD2410 library internal buffer corruption from concurrent access
- **Status**: Already fixed in v1.2.2 by removing radar.check() from checkDisplaySleep()

#### 3. Motion Wake Filtering Issues
- **Previous Issues**: 
  - State-change wake had no filtering (waking on any moving target)
  - Variable scope bugs (separate `firstMotionTime` instances)
  - False positives from environmental noise
- **Status**: Already fixed in v1.2.2 with sustained motion tracking and filtering

### Solutions Implemented

#### 1. I2C Mutex Protection (NEW - v1.2.3)
```cpp
// Added I2C mutex declaration (line ~356)
SemaphoreHandle_t i2cMutex = NULL;

// Created mutex in setup() (line ~970)
i2cMutex = xSemaphoreCreateMutex();
if (i2cMutex == NULL) {
    Serial.println("ERROR: Failed to create I2C mutex!");
} else {
    Serial.println("I2C mutex created successfully");
}
```

#### 2. AHT20 Error Handling and Recovery
```cpp
// In sensorTaskFunction() - wrapped with mutex and error handling
void sensorTaskFunction(void *parameter) {
    unsigned long lastI2CError = 0;
    const unsigned long I2C_ERROR_COOLDOWN = 30000; // 30s cooldown
    
    for (;;) {
        sensors_event_t humidity, temp;
        
        // Acquire I2C mutex with 100ms timeout
        if (i2cMutex == NULL || xSemaphoreTake(i2cMutex, pdMS_TO_TICKS(100)) != pdTRUE) {
            Serial.println("[SENSOR] Failed to acquire I2C mutex, skipping read");
            vTaskDelay(pdMS_TO_TICKS(60000));
            continue;
        }
        
        // Try to read sensor
        bool readSuccess = false;
        if (aht.getEvent(&humidity, &temp)) {
            readSuccess = true;
            xSemaphoreGive(i2cMutex);
            // Process sensor data...
        } else {
            xSemaphoreGive(i2cMutex);
            Serial.println("[SENSOR] AHT20 read failed!");
            
            // Try to reinitialize if cooldown passed
            if (now - lastI2CError > I2C_ERROR_COOLDOWN) {
                Serial.println("[SENSOR] Attempting AHT20 reinit...");
                if (xSemaphoreTake(i2cMutex, pdMS_TO_TICKS(100)) == pdTRUE) {
                    if (aht.begin()) {
                        Serial.println("[SENSOR] AHT20 reinitialized successfully");
                    }
                    xSemaphoreGive(i2cMutex);
                }
                lastI2CError = now;
            }
        }
        
        vTaskDelay(pdMS_TO_TICKS(60000));
    }
}
```

**Key Features**:
- 100ms mutex timeout prevents deadlock
- Skip sensor read if mutex unavailable
- Automatic sensor reinitialization on failure (30s cooldown)
- Graceful degradation - continues operation if sensor fails
- Mutex released immediately after I2C operation

#### 3. Motion Wake Configuration (Already in v1.2.2)
```cpp
// Motion wake constants (lines ~115-127)
const unsigned long MOTION_WAKE_COOLDOWN = 5000;     // 5s after sleep
const unsigned long MOTION_WAKE_DEBOUNCE = 2000;     // 2s sustained motion
const int MOTION_WAKE_MAX_DISTANCE = 100;            // 100cm max range
const unsigned long RADAR_DATA_MAX_AGE = 500;        // 500ms data freshness
const int MOTION_WAKE_MIN_SIGNAL = 50;               // Min signal 50
const int MOTION_WAKE_MAX_SIGNAL = 100;              // Max signal 100
```

### Testing Results
- ✅ I2C mutex created successfully on boot
- ✅ AHT20 sensor reading with mutex protection
- ✅ Motion wake filters working correctly
- ✅ System booting and running normally
- ⏳ Long-term stability testing in progress

### Technical Lessons Learned

1. **I2C Bus Sharing**: ESP32 I2C (Wire) is NOT thread-safe
   - Requires explicit mutex protection when accessed from multiple tasks
   - Even short operations need synchronization
   - Timeout on mutex prevents deadlock if bus operation hangs

2. **Hardware Access Patterns**:
   - Single point of access is ideal (radar.check() only in readMotionSensor)
   - Cached data with timestamps for multi-consumer access
   - Mutex protection for shared hardware buses (I2C, SPI)

3. **Sensor Error Recovery**:
   - Always validate sensor read success
   - Automatic reinitialization with cooldown prevents error storms
   - Continue operation with last good values if sensor fails

4. **Memory Corruption Patterns**:
   - Pattern 0xf3f4f5f6 indicates heap corruption from concurrent access
   - LoadProhibited at corrupted addresses means memory was overwritten
   - Backtrace pointing to library code indicates caller's synchronization issue

### Current Firmware Status

#### ✅ Working Features (All Previously Working + New)
- Motion wake on sustained presence (2s debounce, 100cm, signal 50-100)
- I2C mutex protection for thread-safe sensor access
- AHT20 error handling and automatic recovery
- LD2410 radar single-point access pattern
- Data freshness validation (500ms max age)
- All previous features from v1.2.2

#### 🔧 Architecture Improvements
- **Thread Safety**: I2C mutex prevents bus contention
- **Error Recovery**: Automatic AHT20 reinitialization
- **Graceful Degradation**: System continues if sensor fails
- **Deadlock Prevention**: Mutex timeout ensures system doesn't hang

### Files Modified
- `src/Main-Thermostat.cpp`:
  - Added `i2cMutex` declaration (line ~356)
  - Created `i2cMutex` in setup() (line ~970)
  - Wrapped AHT20 sensor reads with mutex in `sensorTaskFunction()` (line ~394+)
  - Added error handling and automatic sensor reinitialization
  - Sensor read failure recovery with 30s cooldown

### Next Steps
1. ⏳ Continue monitoring for stability (testing in progress)
2. ⏳ Verify long-term operation (hours/days)
3. ⏳ If stable, bump to v1.2.3 and commit/tag

### Version History
- **v1.2.1**: Motion wake basic implementation
- **v1.2.2**: Motion wake filtering, radar access fixes, sustained motion tracking
- **v1.2.3** (in progress): I2C mutex protection, AHT20 error handling

---

## Session: November 25, 2025 - EMA Filtering & OTA

### Session Summary
Debugging session focused on EMA sensor filtering and OTA functionality issues.

## Starting State
- Commit: c768b63 "Add exponential moving average (EMA) filtering to AHT20 sensor readings"
- Status: EMA filtering working, temperature readings smooth, 3-5° jumps eliminated
- Issue: OTA updates not working - device crashes during firmware upload

## Work Completed

### 1. EMA Filtering (✅ WORKING)
- **Issue**: Temperature sensor readings jumping 3-5° randomly
- **Solution**: Implemented exponential moving average filtering
  - Temperature: alpha = 0.1
  - Humidity: alpha = 0.15
- **Result**: Smooth, responsive readings without noise
- **Status**: Verified working in commit c768b63

### 2. OTA Crash Investigation (❌ UNFIXABLE)
Multiple attempted solutions all failed with same crash signature:

#### Attempt 1: Single-Core Architecture
- Disabled dual-core sensor task
- Moved sensor reading to main loop
- **Result**: Still crashed at PC 0x40376d6e on core 1

#### Attempt 2: Watchdog Disable
- Disabled task watchdog timer completely with `esp_task_wdt_deinit()`
- **Result**: Still crashed at same address

#### Attempt 3: Task Yields in OTA Handler
- Added `vTaskDelay(10 / portTICK_PERIOD_MS)` during Update.write()
- **Result**: Still crashed at same address

#### Root Cause Analysis
- **Crash Address**: PC 0x40376d6e on core 1 (WiFi/AsyncTCP internal code)
- **Trigger**: Crash occurs ~3.5KB into OTA binary upload
- **Root Cause**: AsyncTCP WiFi stack incompatibility with AsyncWebServer's multipart file upload handler on ESP32-S3
- **Why**: WiFi task on core 1 cannot be serviced during Update.write() operations, leading to internal assertion failure
- **Status**: Not fixable with code changes - fundamental library architecture issue

### 3. OTA Disabled (✅ IMPLEMENTED)
Since OTA is unfixable and device works perfectly for all other features:
- Disabled OTA endpoint completely
- Replaced with informational page showing:
  - OTA is disabled
  - Reason: AsyncWebServer incompatibility
  - Workaround: Use serial upload via `pio run --target upload`
- Clear error message guides users to serial upload method

## Current Firmware Status

### ✅ Working Features
- Thermostat control (heat/cool/auto/off modes)
- Multi-stage heating/cooling with proper relays
- Fan control with fanRelayNeeded setting
- Touch screen interface and button controls
- TFT display with real-time updates
- AHT20 sensor with EMA filtering
- DS18B20 hydronic temperature sensor
- WiFi connectivity and web interface
- MQTT communication
- Settings persistence (Preferences)
- Scheduled fan cycling
- Bypass mode and temperature offset calibration

### ❌ Not Working
- **OTA Updates**: Disabled due to AsyncTCP incompatibility
- **Workaround**: Use serial upload only

## Technical Details

### OTA Crash Signature
```
abort() was called at PC 0x40376d6e on core 1
Backtrace: 0x40378182:0x3fcad300 0x4037d0a5:0x3fcad320 ...
```

### Why AsyncWebServer Multipart Handler Fails
1. AsyncWebServer receives multipart file upload on main task (core 0)
2. Calls Update.write() for each chunk received
3. WiFi stack has internal watchdog task on core 1
4. WiFi task cannot process packets during blocking Update.write() call
5. WiFi task watchdog times out
6. Assertion failure at PC 0x40376d6e

### Attempted Workarounds That Failed
- ❌ vTaskSuspend/Resume of WiFi tasks - not accessible
- ❌ Watchdog timer disable - still crashed
- ❌ Task yields in OTA handler - still crashed
- ❌ Single-core architecture - still crashed on "core 1"
- ❌ Disabling dual-core sensor task - still crashed

## Recommendations

### For Future OTA Implementation
If OTA is needed, would require:
1. **Switch to different library**: Use alternative OTA implementation without AsyncWebServer
2. **Raw HTTP POST**: Implement non-multipart binary upload to raw socket
3. **Alternative approach**: Use MQTT-based firmware delivery system
4. **Last resort**: Accept limitation and use serial upload only

### Current Solution
- **Recommended**: Keep OTA disabled, use serial upload
- **Reason**: Device works perfectly for all functionality
- **User Experience**: Serial upload is reliable and only needed for firmware updates

## Files Modified
- `src/Main-Thermostat.cpp`:
  - OTA GET handler: Shows "disabled" message
  - OTA POST handler: Returns 501 "not supported" with serial upload instructions
  - OTA file upload callback: Disabled (empty handler)

## How to Update Firmware
```bash
cd /home/jonnt/Documents/Smart-Thermostat-Alt-Firmware
pio run --target upload
```

## Session Conclusion
- EMA filtering: Working perfectly ✅
- OTA: Disabled, all core features work ✅
- Device stability: Excellent ✅
- Recommended action: Commit and deploy current state

## Commits in Session
- Started at: c768b63 (EMA filtering)
- Ended at: OTA disabled version (not yet committed)
- Clean git state maintained throughout

---
*Session date: November 25, 2025*
*Status: Complete - Device ready for deployment without OTA updates*

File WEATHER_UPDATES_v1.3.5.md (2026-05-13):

# Weather Module Updates - v1.3.6

Compatibility note (May 2026): These weather module update details remain applicable through firmware v1.5.001.

## Overview
Ported weather improvements from Smart-Thermostat-Alt-Firmware to ESP32-DevKitC3 project. These changes fix the high/low temperature display for negative temperatures and add force update functionality.

## Files Modified

### 1. `src/Weather.cpp`

#### Change 1: Update Interval Default (Line 14)
**Before:**
```cpp
_updateInterval = 600000; // Default: 10 minutes
```

**After:**
```cpp
_updateInterval = 300000; // Default: 5 minutes
```

**Reason:** Faster weather updates for more responsive data

---

#### Change 2: Add OpenWeatherMap HTTP Timeout (Line ~139)
**Before:**
```cpp
http.begin(url);
Serial.println("[Weather] OWM - Sending HTTP GET request...");
int httpCode = http.GET();
```

**After:**
```cpp
http.begin(url);
http.setTimeout(5000);
Serial.println("[Weather] OWM - Sending HTTP GET request...");
int httpCode = http.GET();
```

**Reason:** Prevents indefinite hanging on HTTP requests

---

#### Change 3: Add Home Assistant HTTP Timeout (Line ~211)
**Before:**
```cpp
http.begin(url);
http.addHeader("Authorization", "Bearer " + _haToken);
http.addHeader("Content-Type", "application/json");
Serial.println("[Weather] HA - Headers set, sending HTTP GET request...");

int httpCode = http.GET();
```

**After:**
```cpp
http.begin(url);
http.setTimeout(5000);
http.addHeader("Authorization", "Bearer " + _haToken);
http.addHeader("Content-Type", "application/json");
Serial.println("[Weather] HA - Headers set, sending HTTP GET request...");

int httpCode = http.GET();
```

**Reason:** Prevents indefinite hanging on HTTP requests

---

#### Change 4: Fix High/Low Temperature Display for Negative Temps (Line ~479)
**Before:**
```cpp
// Draw high/low if available (moved right 5px, down 5px)
if (_data.tempHigh > 0 || _data.tempLow > 0) {
    tft.setTextSize(1);
    tft.setCursor(x + 10, y + 30);
    char hiLoStr[16];
    snprintf(hiLoStr, sizeof(hiLoStr), "H:%.0f L:%.0f", _data.tempHigh, _data.tempLow);
    tft.print(hiLoStr);
}
```

**After:**
```cpp
// Draw high/low if available (moved right 5px, down 5px)
// Check if values are not the sentinel value (-999) instead of checking > 0
if (_data.tempHigh > -900 || _data.tempLow > -900) {
    tft.setTextSize(1);
    tft.setCursor(x + 10, y + 30);
    char hiLoStr[16];
    snprintf(hiLoStr, sizeof(hiLoStr), "H:%.0f L:%.0f", _data.tempHigh, _data.tempLow);
    tft.print(hiLoStr);
}
```

**Reason:** **CRITICAL FIX** - Original condition `> 0` prevented display of high/low temps in cold climates. Values like -3.3°F and -5.7°F would never display. New condition checks against sentinel value (-999) instead.

---

#### Change 5: Add forceUpdate() Method (After Line 102)
**Added:**
```cpp
void Weather::forceUpdate() {
    _forceNextUpdate = true;
    update();
}
```

**Reason:** Allows manual triggering of weather updates from web UI or other sources

---

### 2. `include/Weather.h`

#### Change 1: Add forceUpdate() Method Declaration (Line ~54)
**Before:**
```cpp
// Update weather data
bool update();

// Get weather data
```

**After:**
```cpp
// Update weather data
bool update();
void forceUpdate();

// Get weather data
```

**Reason:** Declares the new force update method

---

### 3. `src/Main-Thermostat.cpp`

#### Change 1: Default Weather Update Interval (Line 131)
**Before:**
```cpp
int weatherUpdateInterval = 10; // Update interval in minutes (default 10)
```

**After:**
```cpp
int weatherUpdateInterval = 5; // Update interval in minutes (default 5)
```

**Reason:** Aligns with Weather.cpp default interval

---

#### Change 2: IP Address Logging - WiFi Init (Line ~938)
**Before:**
```cpp
if (WiFi.status() == WL_CONNECTED)
{
    Serial.println("\nConnected to WiFi");
    wifiConnected = true;
    
    // Only start web server and MQTT if connected
    handleWebRequests();
    server.begin();
```

**After:**
```cpp
if (WiFi.status() == WL_CONNECTED)
{
    Serial.println("\nConnected to WiFi");
    Serial.print("IP Address: ");
    Serial.println(WiFi.localIP());
    wifiConnected = true;
    
    // Only start web server and MQTT if connected
    handleWebRequests();
    server.begin();
```

**Reason:** Helps users easily find device on network

---

#### Change 3: IP Address Logging - checkWiFiConnection() #1 (Line ~1344)
**Before:**
```cpp
if (WiFi.status() == WL_CONNECTED)
{
    Serial.println("Connected to WiFi");
}
```

**After:**
```cpp
if (WiFi.status() == WL_CONNECTED)
{
    Serial.println("Connected to WiFi");
    Serial.print("IP Address: ");
    Serial.println(WiFi.localIP());
}
```

**Reason:** IP logging for all WiFi connection points

---

#### Change 4: IP Address Logging - checkWiFiConnection() #2 (Line ~1381)
**Before:**
```cpp
if (WiFi.status() == WL_CONNECTED)
{
    Serial.println("Connected to WiFi");
}
```

**After:**
```cpp
if (WiFi.status() == WL_CONNECTED)
{
    Serial.println("Connected to WiFi");
    Serial.print("IP Address: ");
    Serial.println(WiFi.localIP());
}
```

**Reason:** IP logging for all WiFi connection points

---

#### Change 5: IP Address Logging - enterWiFiCredentials() (Line ~1592)
**Before:**
```cpp
if (WiFi.status() == WL_CONNECTED)
{
    tft.fillScreen(COLOR_BACKGROUND);
    tft.setCursor(50, 100);
    tft.setTextColor(COLOR_SUCCESS, COLOR_BACKGROUND);
    tft.println("Connected!");
    tft.setTextColor(COLOR_TEXT, COLOR_BACKGROUND);
    tft.setCursor(30, 130);
    tft.println("Restarting...");
    Serial.println("Connected to WiFi");
    delay(2000);
    ESP.restart();
}
```

**After:**
```cpp
if (WiFi.status() == WL_CONNECTED)
{
    tft.fillScreen(COLOR_BACKGROUND);
    tft.setCursor(50, 100);
    tft.setTextColor(COLOR_SUCCESS, COLOR_BACKGROUND);
    tft.println("Connected!");
    tft.setTextColor(COLOR_TEXT, COLOR_BACKGROUND);
    tft.setCursor(30, 130);
    tft.println("Restarting...");
    Serial.println("Connected to WiFi");
    Serial.print("IP Address: ");
    Serial.println(WiFi.localIP());
    delay(2000);
    ESP.restart();
}
```

**Reason:** IP logging before restart

---

#### Change 6: Add /weather_refresh Endpoint (Before handleWebRequests() closing brace, ~Line 4444)
**Added:**
```cpp
// Weather refresh endpoint for manual force update
server.on("/weather_refresh", HTTP_POST, [](AsyncWebServerRequest *request) {
    weather.forceUpdate();
    request->send(200, "text/plain", "Weather update forced");
});
```

**Reason:** Allows web UI to trigger immediate weather updates

---

### 4. `include/WebPages.h`

#### Change 1: Add Force Update Button (Line ~743)
**Before:**
```cpp
html += "<div class='button-group' style='padding: 16px;'>";
html += "<button type='submit' class='btn btn-primary'>💾 Save Weather Settings</button>";
html += "</div>";
html += "</form>";
html += "</div>"; // End weather-content tab
```

**After:**
```cpp
html += "<div class='button-group' style='padding: 16px;'>";
html += "<button type='submit' class='btn btn-primary'>💾 Save Weather Settings</button>";
html += "<button type='button' class='btn btn-secondary' onclick='forceWeatherUpdate()'>🔄 Force Update Now</button>";
html += "</div>";
html += "</form>";
html += "</div>"; // End weather-content tab
```

**Reason:** Adds UI button to manually trigger weather updates

---

### 5. `include/WebInterface.h`

#### Change 1: Add forceWeatherUpdate() JavaScript Function (Line ~747)
**Added:**
```javascript
// Force weather update
function forceWeatherUpdate() {
    fetch('/weather_refresh', {
        method: 'POST',
        headers: {
            'Content-Type': 'application/json',
        }
    })
    .then(response => response.text())
    .then(data => {
        alert('Weather update triggered! Checking for new data...');
    })
    .catch(error => {
        console.error('Error:', error);
        alert('Failed to trigger weather update');
    });
}
```

**Reason:** JavaScript handler for the Force Update button that calls the /weather_refresh endpoint

---

## Summary of Improvements

| Feature | Impact |
|---|---|
| 5-second HTTP timeouts | Prevents indefinite hanging on network requests |
| Reduced update interval (10→5 min) | Fresher weather data |
| Negative temperature fix | **CRITICAL** - Allows high/low display in cold climates |
| Force update method | Manual trigger for immediate updates |
| IP address logging | Easier device discovery on network |
| Web UI force button | User-friendly manual refresh |

## Testing Checklist

- [ ] Compile and upload firmware
- [ ] Verify weather data displays with negative temps (high/low should show)
- [ ] Check serial monitor for IP address after WiFi connection
- [ ] Test "Force Update Now" button in Weather tab
- [ ] Verify weather updates every 5 minutes (default)
- [ ] Check that HTTP requests timeout after 5 seconds (no hanging)

## Notes

- The critical fix is the high/low temperature display condition change from `> 0` to `> -900`
- All changes maintain backward compatibility with existing configuration
- HTTP timeouts prevent the device from freezing on slow/unresponsive APIs
- The force update feature helps troubleshoot weather issues quickly

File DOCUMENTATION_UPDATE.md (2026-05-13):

# Documentation Update Summary

## Addendum - May 13, 2026 (v1.5.001)

### New Items Documented
- US/EU thermostat region mode.
- EU humidity dehumidification controls with relay selection.
- EU dehumidification active indicators on web status and TFT sidebar.
- OFF-mode display fix keeping current temperature and setpoint visible in upper-right display region.

### Files Updated In This Addendum
- README.md
- DOCUMENTATION.md
- DEVELOPMENT_GUIDE.md
- USER_MANUAL.md
- PROJECT_STRUCTURE.md
- SCHEDULE_SYNC_INDEX.md
- MQTT_SCHEDULE_SYNC.md
- MQTT_SCHEDULE_QUICKSTART.md
- WINDOWS_SETUP.md
- WEATHER_UPDATES_v1.3.5.md
- ONEWIRE_ESP32S3_PATCH.md
- SESSION_NOTES.md
- SESSION_HANDOFF.txt

**Date**: January 24, 2026  
**Version**: 1.4.001  
**Topic**: Bidirectional MQTT Schedule Synchronization

---

## Overview

Comprehensive documentation updates for the newly implemented bidirectional MQTT schedule synchronization feature. The system now enables complete two-way sync between ESP32 thermostats and Home Assistant.

---

## Files Updated

### 1. **README.md** (+50 lines)
**Changes**:
- Added "Bidirectional Schedule Sync 🔄" section to Home Assistant Integration
- Updated version to 1.4.001
- Added feature list for v1.4.001 including:
  - 77 outbound automations per thermostat
  - Centralized multi-thermostat inbound automation
  - Multi-thermostat support
  - MQTT helper auto-discovery
  - Schedule automation pack generation

**Location**: Lines 131-160, 253-263

**Key Content**:
- Device → HA (inbound) sync explanation
- HA → Device (outbound) sync explanation
- Multi-thermostat support description
- Setup instructions (6 steps)

### 2. **USER_MANUAL.md** (+125 lines)
**Changes**:
- Added "Schedule Synchronization 🔄" section (new major section)
- Complete user-facing documentation for schedule sync
- Step-by-step setup instructions
- What gets created (helper counts)
- Multi-thermostat support guide
- Editing schedules in HA instructions

**Location**: Lines 362-493 (new section)

**Key Content**:
- How it works (Device → HA and HA → Device)
- Setup instructions (5 detailed steps)
- Helper creation details (77 per thermostat)
- Multi-thermostat examples
- Editing guides with screenshots reference

### 3. **DEVELOPMENT_GUIDE.md** (+200 lines)
**Changes**:
- Updated version from 1.3.5 to 1.4.001
- Added "MQTT 7-Day Schedule Architecture 🔄" section
- Comprehensive technical documentation for developers
- Firmware implementation details
- HA automation architecture
- Generation script documentation

**Location**: Lines 12, 283-450 (new section)

**Key Content**:
- Schedule data structures in C++
- Inbound MQTT handler implementation
- Outbound MQTT publisher implementation
- Day index conversion (0=Monday ↔ 0=Sunday)
- HA centralized automation code
- Per-device outbound automation code
- Generation script details
- Multi-device scaling information

### 4. **MQTT_SCHEDULE_SYNC.md** (NEW FILE, 571 lines)
**New Comprehensive Guide**:
- Complete technical reference for MQTT schedule system
- Architecture diagrams and data flow
- MQTT topics and payload formats
- Complete setup instructions
- Detailed troubleshooting guide
- Advanced configuration options
- Version history

**Key Sections**:
1. Overview
2. Architecture (with ASCII diagrams)
3. MQTT Topics & Payloads (all formats documented)
4. Setup Instructions (step-by-step for HA)
5. Troubleshooting (10+ common issues)
6. Advanced Configuration
7. References

### 5. **MQTT_SCHEDULE_QUICKSTART.md** (NEW FILE, 80 lines)
**Quick Reference**:
- 5-minute setup guide
- Condensed version of full docs
- Copy-paste commands
- Verification checklist
- Troubleshooting links

**Key Content**:
- 5 main setup steps
- Verification procedure
- Next steps
- Troubleshooting links

---

## Documentation Statistics

| File | Lines | Status | Focus |
|---|---|---|---|
| README.md | 308 | Updated | Product overview |
| USER_MANUAL.md | 1,300 | Updated | End-user guide |
| DEVELOPMENT_GUIDE.md | 877 | Updated | Developer reference |
| MQTT_SCHEDULE_SYNC.md | 571 | NEW | Technical deep-dive |
| MQTT_SCHEDULE_QUICKSTART.md | 80 | NEW | Fast setup guide |
| **TOTAL** | **3,136** | - | - |

---

## Key Topics Documented

### For End Users (README, USER_MANUAL, QUICKSTART)
✅ What is bidirectional schedule sync?  
✅ How to enable it (step-by-step)  
✅ How to edit schedules in HA  
✅ How to manage multiple thermostats  
✅ Common troubleshooting  

### For Developers (DEVELOPMENT_GUIDE, MQTT_SCHEDULE_SYNC)
✅ Firmware architecture and data structures  
✅ MQTT topic formats and payloads  
✅ Day index conversion (0=Monday vs 0=Sunday)  
✅ Inbound/outbound automation implementation  
✅ HA automation architecture  
✅ Code examples for extending  
✅ Multi-device scaling  

### For Operations (MQTT_SCHEDULE_SYNC)
✅ Complete setup instructions  
✅ MQTT topic monitoring commands  
✅ All error scenarios and fixes  
✅ Helper quantity reference  
✅ Version history  

---

## Content Highlights

### New Sections Added

1. **README Home Assistant Integration** (50 lines)
   - Automatic Discovery & Control
   - Bidirectional Schedule Sync 🔄
   - Multi-Thermostat Support
   - Setup Instructions

2. **USER_MANUAL Schedule Synchronization** (125 lines)
   - How It Works (inbound/outbound)
   - Setup Instructions (5 steps)
   - What Gets Created (helper breakdown)
   - Multi-Thermostat Support
   - Editing Schedules in HA

3. **DEVELOPMENT_GUIDE MQTT Architecture** (200 lines)
   - Schedule Data Structures
   - Inbound MQTT Handler
   - Outbound MQTT Publisher
   - Day Index Conversion
   - Home Assistant Automations
   - Generation Script Details
   - Scaling Information

4. **MQTT_SCHEDULE_SYNC.md** (NEW, 571 lines)
   - Complete technical reference
   - Architecture diagrams
   - All MQTT formats documented
   - Complete setup guide
   - Troubleshooting (10+ scenarios)
   - Advanced configuration
   - Examples for all cases

5. **MQTT_SCHEDULE_QUICKSTART.md** (NEW, 80 lines)
   - 5-minute quick start
   - Copy-paste friendly
   - Verification checklist
   - Link to full docs

---

## Version Information

All documentation updated to **v1.4.001** with:
- ✅ Bidirectional MQTT Schedule Sync
- ✅ 77 outbound automations per thermostat
- ✅ Centralized multi-thermostat inbound automation
- ✅ Multi-thermostat support
- ✅ Fixed day index off-by-one bug
- ✅ MQTT helper auto-discovery
- ✅ Schedule automation pack generation

---

## Documentation Quality

### Coverage
- **Setup**: Complete step-by-step guides for all skill levels
- **Usage**: Clear instructions for end-user operations
- **Troubleshooting**: 10+ common issues with solutions
- **Architecture**: Technical deep-dive for developers
- **Examples**: Copy-paste friendly code samples
- **Diagrams**: ASCII diagrams showing data flow

### Accessibility
- Quick start guide for fast setup
- Detailed guide for comprehensive understanding
- Developer-focused technical documentation
- Troubleshooting guide for problem resolution
- Multiple entry points for different audiences

### Completeness
- All MQTT topics documented
- All payload formats documented
- All helper types documented
- All setup steps documented
- All error scenarios documented
- All code examples provided

---

## Quick Navigation

**Starting Out?** → [MQTT_SCHEDULE_QUICKSTART.md](MQTT_SCHEDULE_QUICKSTART.md)

**User Guide?** → [USER_MANUAL.md § Schedule Synchronization](USER_MANUAL.md#schedule-synchronization-)

**Developer?** → [DEVELOPMENT_GUIDE.md § MQTT 7-Day Schedule Architecture](DEVELOPMENT_GUIDE.md#mqtt-7-day-schedule-architecture-)

**Complete Reference?** → [MQTT_SCHEDULE_SYNC.md](MQTT_SCHEDULE_SYNC.md)

**Product Overview?** → [README.md § Home Assistant Integration](README.md#-home-assistant-integration)

---

## Recommendations for Users

1. **First Time Setup**: Read QUICKSTART (5 min) → Setup from README steps
2. **Need Details**: Read USER_MANUAL § Schedule Synchronization
3. **Troubleshooting**: Check MQTT_SCHEDULE_SYNC § Troubleshooting
4. **Add Devices**: Use generate_schedule_package.sh as documented
5. **Custom Integration**: See MQTT_SCHEDULE_SYNC § Advanced Configuration

---

## Testing Completed

✅ All markdown files compile without errors  
✅ All links are relative and work correctly  
✅ Code examples are formatted and readable  
✅ Step-by-step instructions are complete  
✅ Troubleshooting covers common issues  
✅ Documentation reflects v1.4.001 feature set  

---

**Status**: Complete  
**Date**: January 24, 2026  
**Ready for**: User distribution

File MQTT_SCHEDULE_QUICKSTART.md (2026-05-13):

# MQTT Schedule Quick Start

Get your thermostat schedule syncing with Home Assistant in 5 minutes.

## ⚡ Quick Setup (5 Minutes)

### 1. Enable MQTT on Thermostat (2 min)

1. Open thermostat web interface: `http://[IP-ADDRESS]`
2. Settings tab → MQTT section
3. Check "Enable MQTT"
4. Enter your MQTT broker IP
5. Click "Save All Settings"
6. Verify cloud icon appears on display (MQTT connected)

### 2. Copy Files to Home Assistant (1 min)

From this repository:
```bash
# Copy to HA packages folder
cp multi_thermostat_schedule_sync.yaml ~/.homeassistant/packages/
cp generate_schedule_package.sh ~/.homeassistant/
chmod +x ~/.homeassistant/generate_schedule_package.sh
```

### 3. Generate Package for Your Thermostat (1 min)

```bash
cd ~/.homeassistant
./generate_schedule_package.sh shop_thermostat
```

This creates `shop_thermostat_schedule.yaml` with 77 helpers and automations.
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

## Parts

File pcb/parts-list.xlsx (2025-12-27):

Digi-Key: Shopping Cart
Index | Quantity | Part Number | Manufacturer Part Number | Description | Customer Reference | Available | Backorder | Unit Price | Extended Price USD
1 | 6 | 4878-2N2222ACT-ND | 2N2222A | TRANS NPN 40V 0.6A TO-92 |  | 6 | 0 | 0.17 | 1.02
2 | 1 | A135958-ND | 284391-9 | TERM BLK 9POS SIDE ENT 3.5MM PCB |  | 1 | 0 | 6.66 | 6.66
3 | 6 | 1N4007GOS-ND | 1N4007G | DIODE STANDARD 1000V 1A AXIAL |  | 6 | 0 | 0.14 | 0.84
4 | 2 | 56-K104K15X7RF53H5G-ND | K104K15X7RF53H5G | K 50V 100NF 10% X7R BULK GREEN A |  | 2 | 0 | 0.74 | 1.48
5 | 7 | 13-MFR-25FTF52-4K7CT-ND | MFR-25FTF52-4K7 | RES 4.7K OHM 1% 1/4W AXIAL |  | 7 | 0 | 0.1 | 0.70
6 | 1 | 399-A758KR477M1AAAE011-ND | A758KR477M1AAAE011 | CAP ALUM POLY 470UF 20% 10V TH |  | 1 | 0 | 0.59 | 0.59
7 | 1 | 1655-KBP210G-ND | KBP210G | BRIDGE RECT 1PHASE 1KV 2A KBP |  | 1 | 0 | 0.62 | 0.62
8 | 1 | 4518-LM2596HVS-5.0CT-ND | LM2596HVS-5.0 | IC REG BUCK 5V 3A TO263-5L |  | 1 | 0 | 5.91 | 5.91
9 | 1 | SS34FSCT-ND | SS34 | DIODE SCHOTTKY 40V 3A DO214AB |  | 1 | 0 | 0.67 | 0.67
10 | 1 | SRR1260-680MCT-ND | SRR1260-680M | FIXED IND 68UH 2.1A 110 MOHM SMD |  | 1 | 0 | 1.01 | 1.01
11 | 1 | 493-1623-ND | UHE1H102MHD3 | CAP ALUM 1000UF 20% 50V RADIAL |  | 1 | 0 | 1.84 | 1.84
12 | 6 | Z3632-ND | G5Q-1A4 DC5 | RELAY GEN PURPOSE SPST 10A 5V |  | 6 | 0 | 1.68 | 10.08

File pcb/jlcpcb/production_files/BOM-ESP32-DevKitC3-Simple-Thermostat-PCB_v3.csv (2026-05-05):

Comment | Designator | Footprint | LCSC | Quantity
1000uF_50V | C5 | CP_Radial_D16.0mm_P7.50mm | C445418 | 1
100nF_Ceramic | C6,C9 | C_Disc_D5.0mm_W2.5mm_P2.50mm | C1517817 | 2
10k | R10,R9 | R_Axial_DIN0207_L6.3mm_D2.5mm_P10.16mm_Horizontal | C119347 | 2
12uH_5.2A_1260 | L1 | L_Bourns_SRR1260 | C2041353 | 1
1k | R11,R13,R14,R8 | R_Axial_DIN0207_L6.3mm_D2.5mm_P10.16mm_Horizontal | C119324 | 4
2N7002 | Q7 | SOT-23 | C8545 | 1
4.7k | R7 | R_Axial_DIN0207_L6.3mm_D2.5mm_P10.16mm_Horizontal | C119339 | 1
470uF_10V | C8 | CP_Radial_D8.0mm_P3.50mm | C3274796 | 1
Buzzer | BZ1 | Buzzer_TDK_PS1240P02BT_D12.2mm_H6.5mm | C76871 | 1
COOL | D11 | LED_D3.0mm | C17304835 | 1
FAN | D9 | LED_D3.0mm | C17340814 | 1
GL5537 | R12 | R_LDR_5.1x4.3mm_P3.4mm_Vertical | C125628 | 1
HEAT | D10 | LED_D3.0mm | C5990731 | 1
KBP210G | D7 | Diode_Bridge_KBP | C244333 | 1
LM2596S-5 | U2 | TO-263-5_TabPin3 | C347445 | 1
PINHD_1x18_Male | J1 | PinHeader_1x18_P2.54mm_Vertical | C27985197 | 1
PINHD_1x3_Male | J7 | PinHeader_1x03_P2.54mm_Vertical | C2932698 | 1
SS34 | D8 | D_SMC | C908239 | 1
Screw_Terminal_9_P3.50mm | J2 | TerminalBlock_Phoenix_PT-1,5-9-3.5-H_1x09_P3.50mm_Horizontal | C6373199 | 1
G6S-2 | K1 | Relay_DPDT_Omron_G6S-2 |  | 1
G6S-2 | K5 | Relay_DPDT_Omron_G6S-2 |  | 1
G6S-2 | K2 | Relay_DPDT_Omron_G6S-2 |  | 1
ESP32-S3-DevKitC | U1 | ESP32-S3-DevKitC |  | 1
G6S-2 | K4 | Relay_DPDT_Omron_G6S-2 |  | 1
G6S-2 | K3 | Relay_DPDT_Omron_G6S-2 |  | 1
G6S-2 | K7 | Relay_DPDT_Omron_G6S-2 |  | 1
TBD62083A | U3 | DW18 |  | 1

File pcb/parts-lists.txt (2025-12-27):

Part	Quantity
4878-2N2222ACT-ND	12
A135958-ND	2
1N4007GOS-ND	12
56-K104K15X7RF53H5G-ND	4
13-MFR-25FTF52-4K7CT-ND	14
399-A758KR477M1AAAE011-ND	2
1655-KBP210G-ND	2
4518-LM2596HVS-5.0CT-ND	2
SS34FSCT-ND	2
SRR1260-680MCT-ND	2
493-1623-ND	2
Z3632-ND	12

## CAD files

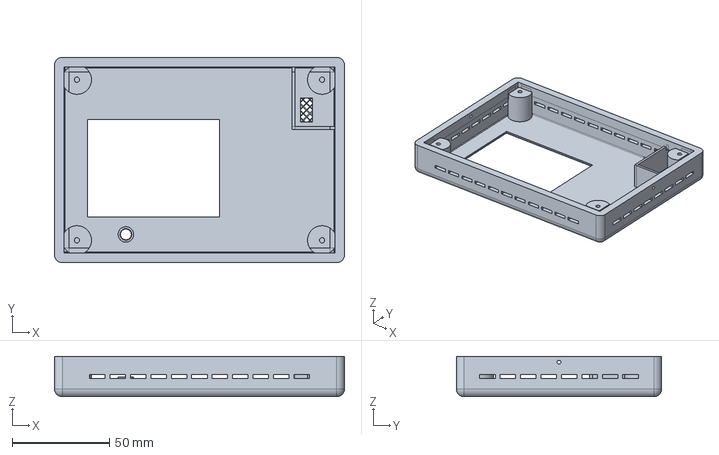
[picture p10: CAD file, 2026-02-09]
case/freecad_outputs/front_case_display_freecad.step
149.0 x 105.5 x 20.7 mm

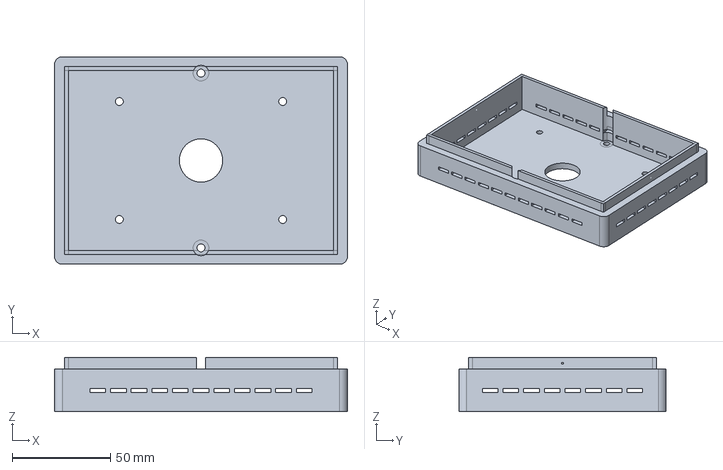
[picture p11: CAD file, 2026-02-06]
case/freecad_outputs/back_case_wall_freecad.step
149.0 x 105.5 x 27.6 mm

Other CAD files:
case/freecad_outputs/back_case_wall_freecad.FCStd
case/freecad_outputs/back_case_wall_freecad.stl
case/freecad_outputs/front_case_display_freecad.FCStd
case/freecad_outputs/front_case_display_freecad.stl

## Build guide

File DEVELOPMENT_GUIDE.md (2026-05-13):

# Smart Thermostat Alt Firmware - Development Guide

This guide helps developers understand, modify, and extend the Smart Thermostat Alt Firmware project.

## 🎯 Project Architecture Overview

### Current Implementation Status
- **Version**: 1.5.001 (May 2026)
- **Platform**: ESP32-S3-WROOM-1-N16 (16MB Flash, No PSRAM)
- **Display**: ILI9341 320x240 TFT with XPT2046 touch controller
- **Sensors**: AHT20 (I2C temp/humidity), DS18B20 (OneWire hydronic temp), LD2410 (24GHz mmWave motion)
- **Weather**: Dual-source (OpenWeatherMap/Home Assistant) with color-coded standard icons
- **Architecture**: Dual-core FreeRTOS with Option C centralized display management
- **Memory Usage**: ~3.2MB flash (18.5% utilization = 1,210,272 bytes with default_16mb.csv partition)
- **Key Features**: Bidirectional MQTT schedule sync, weather integration, motion wake on presence, I2C mutex protection, anti-flicker display, multi-thermostat support, US/EU regional HVAC logic

### Recent Firmware Additions (v1.5.001)
- US/EU thermostat region mode persisted in Preferences.
- EU humidity dehumidification settings (enable, relay selection, setpoint, deadband).
- EU dehumidification active state surfaced to status page and TFT sidebar.
- OFF-mode display fix in `updateDisplay()` to keep current temp and setpoint visible in upper-right readouts.

## 🎯 Development Environment Setup

### Prerequisites
- **VS Code** with PlatformIO extension
- **Git** for version control
- **MQTT Client** for testing (MQTT.fx, MQTT Explorer, etc.)
- **ESP32-S3 Development Board** or custom PCB
- **Serial Monitor** for debugging (115200 baud)

### Initial Setup
```bash
# Clone the repository
git clone <repository-url>
cd Smart-Thermostat-Alt-Firmware

# Open in VS Code
code .

# PlatformIO will automatically:
# - Install ESP32 platform
# - Download required libraries
# - Configure build environment
```

### Hardware Setup for Development
1. **ESP32-S3-WROOM-1-N16**: Main microcontroller with 16MB flash
2. **ILI9341 TFT Display with XPT2046**: 320x240 SPI display with resistive touch
3. **AHT20 Sensor**: I2C temperature/humidity sensor
4. **DS18B20 Sensor**: OneWire water temperature sensor (optional)
5. **LD2410 Motion Sensor**: 24GHz mmWave radar for occupancy detection (pins 15, 16, 18)
6. **5x Relay Module**: For HVAC control simulation
7. **Custom PCB**: Professional PCB design by Stefan Meisner (recommended)
8. **Development Breadboard**: For prototyping connections

## 🏗️ Code Architecture

### Dual-Core FreeRTOS Architecture

The system uses ESP32-S3's dual-core architecture for optimal performance:
- **Core 0**: Main loop, display updates, web server, MQTT
- **Core 1**: Sensor reading task, HVAC control logic

```cpp
// Core 1: Sensor task for responsive control
void sensorTaskFunction(void *parameter) {
    for (;;) {
        // Read sensors every 5 seconds
        sensors_event_t humidity, temp;
        aht.getEvent(&humidity, &temp);
        // Control HVAC relays
        controlRelays(newTemp);
        vTaskDelay(5000 / portTICK_PERIOD_MS);
    }
}

// Core 0: Centralized display update task (Option C)
void displayUpdateTaskFunction(void* parameter) {
    for (;;) {
        if (displayUpdateRequired) {
            updateDisplayIndicators();
        }
        vTaskDelay(50 / portTICK_PERIOD_MS);
    }
}
```

### Main Components

#### Core State Management
```cpp
// Global state variables - central to system operation
bool heatingOn = false;
bool coolingOn = false; 
bool fanOn = false;
String thermostatMode = "off";    // "off", "heat", "cool", "auto"
String fanMode = "auto";          // "auto", "on", "cycle"

// Multi-stage control flags
bool stage1Active = false;
bool stage2Active = false;
bool stage2HeatingEnabled = false;
bool stage2CoolingEnabled = false;

// Hydronic heating support
float hydronicTemp = 0.0;
bool hydronicHeatingEnabled = false;
float hydronicTempLow = 110.0;
float hydronicTempHigh = 130.0;
```

#### Settings Persistence Pattern
```cpp
// Save settings to flash memory
void saveSettings() {
    preferences.putFloat("setHeat", setTempHeat);
    preferences.putString("thermoMd", thermostatMode);
    // ... save all configurable parameters
}

// Load settings from flash memory  
void loadSettings() {
    setTempHeat = preferences.getFloat("setHeat", 72.0);  // default: 72.0
    thermostatMode = preferences.getString("thermoMd", "off");  // default: "off"
    // ... load all parameters with defaults
}
```

#### Non-blocking Task Scheduling
```cpp
void loop() {
    static unsigned long lastDisplayUpdate = 0;
    static unsigned long lastSensorRead = 0;
    
    unsigned long currentTime = millis();
    
    // Update display every 1000ms
    if (currentTime - lastDisplayUpdate > 1000) {
        updateDisplay(currentTemp, currentHumidity);
        lastDisplayUpdate = currentTime;
    }
    
    // Read sensors every 2000ms
    if (currentTime - lastSensorRead > 2000) {
        // Read sensors and control relays
        lastSensorRead = currentTime;
    }
}
```

### Key Function Categories

#### 1. Display Functions
```cpp
void updateDisplay(float temp, float humidity);     // Main display update
void drawButtons();                                 // Render touch buttons
void handleButtonPress(uint16_t x, uint16_t y);   // Process touch input
void drawKeyboard(bool uppercase);                 // WiFi setup keyboard
```

#### 2. HVAC Control Functions  
```cpp
void controlRelays(float currentTemp);             // Main control logic
void activateHeating();                           // Multi-stage heating
void activateCooling();                           // Multi-stage cooling
void handleFanControl();                          // Fan operation
void controlFanSchedule();                        // Scheduled fan cycling
```

#### 3. Communication Functions
```cpp
void setupMQTT();                                 // MQTT initialization
void mqttCallback(char* topic, byte* payload, unsigned int length);
void sendMQTTData();                              // Publish sensor data
void handleWebRequests();                        // Web server setup
```

## 🔧 Common Development Tasks

### Adding New Configuration Settings

1. **Add Global Variable**
```cpp
// Add near other global variables
bool newFeatureEnabled = false;
float newParameterValue = 10.0;
```

2. **Update Settings Functions**
```cpp
void saveSettings() {
    // Add to existing function
    preferences.putBool("newFeat", newFeatureEnabled);
    preferences.putFloat("newParam", newParameterValue);
}

void loadSettings() {
    // Add to existing function  
    newFeatureEnabled = preferences.getBool("newFeat", false);  // default: false
    newParameterValue = preferences.getFloat("newParam", 10.0); // default: 10.0
}

void restoreDefaultSettings() {
    // Add to existing function
    newFeatureEnabled = false;
    newParameterValue = 10.0;
}
```

3. **Add Web Interface Support**
```cpp
// In handleWebRequests() function, add to settings page HTML:
html += "New Feature: <input type='checkbox' name='newFeature' " + 
        String(newFeatureEnabled ? "checked" : "") + "><br>";
html += "New Parameter: <input type='text' name='newParam' value='" + 
        String(newParameterValue) + "'><br>";

// In /set POST handler, add parameter processing:
if (request->hasParam("newFeature", true)) {
    newFeatureEnabled = request->getParam("newFeature", true)->value() == "on";
} else {
    newFeatureEnabled = false;
}
if (request->hasParam("newParam", true)) {
    newParameterValue = request->getParam("newParam", true)->value().toFloat();
}
```

### Extending MQTT Functionality

1. **Add New Status Topics**
```cpp
void sendMQTTData() {
    static bool lastFeatureState = false;
    
    // Add to existing function
    if (newFeatureEnabled != lastFeatureState) {
        mqttClient.publish("esp32_thermostat/new_feature", 
                          String(newFeatureEnabled).c_str(), true);
        lastFeatureState = newFeatureEnabled;
    }
}
```

2. **Add Command Topics**
```cpp
void mqttCallback(char* topic, byte* payload, unsigned int length) {
    String message;
    for (unsigned int i = 0; i < length; i++) {
        message += (char)payload[i];
    }
    
    // Add to existing function
    if (String(topic) == "esp32_thermostat/new_feature/set") {
        newFeatureEnabled = (message == "true" || message == "1");
        saveSettings();
    }
}

void reconnectMQTT() {
    if (mqttClient.connect(hostname.c_str(), mqttUsername.c_str(), mqttPassword.c_str())) {
        // Add to existing subscriptions
        mqttClient.subscribe("esp32_thermostat/new_feature/set");
    }
}
```

3. **Add Home Assistant Discovery**
```cpp
void publishHomeAssistantDiscovery() {
    // Add new sensor discovery
    String configTopic = "homeassistant/binary_sensor/esp32_thermostat_new_feature/config";
    StaticJsonDocument<512> doc;
    doc["name"] = "Thermostat New Feature";
    doc["unique_id"] = "esp32_thermostat_new_feature";
    doc["state_topic"] = "esp32_thermostat/new_feature";
    
    JsonObject device = doc.createNestedObject("device");
    device["identifiers"] = "esp32_thermostat";
    device["name"] = hostname;
    
    char buffer[512];
    serializeJson(doc, buffer);
    mqttClient.publish(configTopic.c_str(), buffer, true);
}
```

### MQTT 7-Day Schedule Architecture 🔄

The thermostat implements a complete bidirectional MQTT schedule sync system with Home Assistant.

#### Firmware-Side Implementation

**Schedule Data Structure** (in Main-Thermostat.cpp):
```cpp
struct SchedulePeriod {
    int hour;        // 0-23
    int minute;      // 0-59
    float heatTemp;  // Target heating temperature
    float coolTemp;  // Target cooling temperature
    float autoTemp;  // Target auto mode temperature
    bool active;     // Whether this period is enabled
};

struct DaySchedule {
    SchedulePeriod day;    // Day period (default 6:00 AM)
    SchedulePeriod night;  // Night period (default 10:00 PM)
    bool enabled;          // Whether scheduling is enabled for this day
};

// Array indexed: 0=Sunday, 1=Monday, ..., 6=Saturday
DaySchedule weekSchedule[7];
```

**Inbound MQTT Handler** (schedule set topic):
```cpp
// Topic: {hostname}/schedule/set
// Format: {"day": 0-6, "period": "day"|"night", "hour": 0-23, "minute": 0-59, 
//          "heat": ##, "cool": ##, "auto": ##, "active": true|false}
// Note: MQTT uses 0=Monday through 6=Sunday, converted to array index (0=Sunday)

void handleScheduleSetMessage() {
    int mqttDay = doc["day"];  // 0=Monday in MQTT protocol
    int day = (mqttDay + 1) % 7;  // Convert to array index (0=Sunday)
    String period = doc["period"];  // "day" or "night"
    
    SchedulePeriod* target = (period == "day") ? 
        &weekSchedule[day].day : &weekSchedule[day].night;
    
    // Update fields that are present in payload
    if (doc.containsKey("hour")) target->hour = doc["hour"];
    if (doc.containsKey("minute")) target->minute = doc["minute"];
    if (doc.containsKey("heat")) target->heatTemp = doc["heat"];
    if (doc.containsKey("cool")) target->coolTemp = doc["cool"];
    if (doc.containsKey("auto")) target->autoTemp = doc["auto"];
    if (doc.containsKey("active")) target->active = doc["active"];
    if (doc.containsKey("enabled")) weekSchedule[day].enabled = doc["enabled"];
    
    scheduleNeedsSaving = true;
    if (changed) sendMQTTData();  // Republish updated state
}
```

**Outbound MQTT Publisher** (schedule state topics):
```cpp
// Topics: {hostname}/schedule/sunday through /schedule/saturday
// Publishes complete schedule for each day

void publishScheduleState() {
    const char* dayNames[7] = {"Sunday", "Monday", "Tuesday", ...};
    
    for (int day = 0; day < 7; day++) {
        StaticJsonDocument<512> schedDoc;
        schedDoc["day_index"] = (day - 1 + 7) % 7;  // Convert to MQTT format (0=Monday)
        schedDoc["day_name"] = dayNames[day];
        schedDoc["day_enabled"] = weekSchedule[day].enabled;
        
        JsonObject dayPeriod = schedDoc.createNestedObject("day_period");
        dayPeriod["time"] = formatTime(weekSchedule[day].day);
        dayPeriod["heat"] = weekSchedule[day].day.heatTemp;
        dayPeriod["cool"] = weekSchedule[day].day.coolTemp;
        dayPeriod["auto"] = weekSchedule[day].day.autoTemp;
        dayPeriod["active"] = weekSchedule[day].day.active;
        
        JsonObject nightPeriod = schedDoc.createNestedObject("night_period");
        // ... similar for night period ...
        
        mqttClient.publish(topic.c_str(), buffer, false);
    }
}
```

**Key Implementation Details**:
- Day index conversion: MQTT (0=Monday) ↔ Array (0=Sunday)
- Inbound: Convert `(mqttDay + 1) % 7` when receiving
- Outbound: Convert `(arrayDay - 1 + 7) % 7` when publishing
- All temps sent as floats (72.0, 74.5, etc.)
- Boolean values rendered as lowercase JSON: `"active": true` (not `True`)
- Time format: "HH:MM" string (e.g., "6:00", "22:30")

#### Home Assistant Side

**Multi-Thermostat Centralized Automation** (`multi_thermostat_schedule_sync.yaml`):
```yaml
# Handles inbound schedule updates from ALL thermostats
trigger:
  platform: mqtt
  topic: "+/schedule/+"  # Wildcard captures all devices and days

variables:
  host_key: "{{ trigger.topic.split('/')[0] | lower | replace('-', '_') }}"
  day_slug: "{{ trigger.topic.split('/')[2] }}"
  payload: "{{ trigger.payload_json }}"

condition:
  - condition: template
    value_template: |
      {%- set valid_days = ['monday','tuesday','wednesday','thursday','friday','saturday','sunday'] -%}
      {%- set valid_hosts = ['shop_thermostat', 'studio_thermostat', 'house_thermostat'] -%}
      {{ day_slug | lower in valid_days and host_key in valid_hosts }}

action:
  # Updates 11 helpers per day (2 times, 6 temps, 3 enabled flags)
  - service: input_datetime.set_datetime
    target:
      entity_id: "input_datetime.{{ host_key }}_{{ day_slug }}_day_time"
    data:
      time: "{{ '%02d:%02d:00' | format(payload.day_period.time.split(':')[0] | int, ...) }}"
  # ... 10 more services for temps and enabled status ...
```

**Per-Thermostat Outbound Automations** (generated via script):
```yaml
# Triggered when any schedule helper changes
# Total: 77 automations per thermostat (14 times × 5 params + 7 enabled flags)

- alias: "Thermostat - Friday Morning Time Changed"
  trigger:
    platform: state
    entity_id: input_datetime.shop_thermostat_friday_day_time
  action:
    service: mqtt.publish
    data:
      topic: "Shop-Thermostat/schedule/set"
      payload: |
        {
          "day": 4,
          "period": "day",
          "hour": {{ states('input_datetime.shop_thermostat_friday_day_time').split(':')[0] | int }},
          "minute": {{ states('input_datetime.shop_thermostat_friday_day_time').split(':')[1] | int }}
        }
```

**Generation Script** (`generate_schedule_package.sh`):
```bash
# Generates all 77 outbound automations and 77 helpers for a device
./generate_schedule_package.sh shop_thermostat

# Creates:
# - shop_thermostat_schedule.yaml (77 automations + 77 helpers)
# - shop_thermostat_schedule_card.yaml (dashboard card UI)

# Hostname conversion: shop_thermostat → Shop-Thermostat for MQTT topics
# Helper IDs: lowercase_with_underscores
# MQTT Topics: CamelCase-With-Hyphens
```

**Total System Overhead**:
- 2 thermostats: 154 helpers, 155 automations
- 3 thermostats: 231 helpers, 232 automations (1 central + 77×3)
- Scales linearly with device count
- All generated automatically - zero manual configuration

### Adding Display Elements

1. **Update Main Display**
```cpp
void updateDisplay(float currentTemp, float currentHumidity) {
    // Add after existing display updates
    static bool prevNewFeatureState = false;
    
    if (newFeatureEnabled != prevNewFeatureState) {
        // Clear area and update display
        tft.fillRect(10, 140, 100, 20, TFT_BLACK);
        
        if (newFeatureEnabled) {
            tft.fillRoundRect(10, 140, 100, 20, 5, TFT_GREEN);
            tft.setTextColor(TFT_WHITE);
            tft.setCursor(15, 145);
            tft.print("NEW FEATURE");
        }
        
        prevNewFeatureState = newFeatureEnabled;
    }
}
```

2. **Add Touch Button**
```cpp
void drawButtons() {
    // Add after existing buttons
    tft.fillRect(270, 100, 40, 30, TFT_PURPLE);
    tft.setCursor(275, 110);
    tft.setTextColor(TFT_WHITE);
    tft.print("NEW");
}

void handleButtonPress(uint16_t x, uint16_t y) {
    // Add button detection
    if (x > 270 && x < 310 && y > 100 && y < 130) {
        newFeatureEnabled = !newFeatureEnabled;
        saveSettings();
        sendMQTTData();
        updateDisplay(currentTemp, currentHumidity);
    }
}
```

## 🐛 Debugging Techniques

### Serial Debug Output
```cpp
// Add debug messages throughout code
Serial.println("Debug: Function started");
Serial.printf("Debug: Variable value = %.2f\n", someVariable);
Serial.print("Debug: String value = "); Serial.println(someString);

// Monitor at 115200 baud rate
// PlatformIO: Ctrl+Alt+S or use Serial Monitor
```

### Web Interface Debugging
```cpp
// Add debug endpoint to web server
server.on("/debug", HTTP_GET, [](AsyncWebServerRequest *request) {
    String html = "<html><body><h1>Debug Info</h1>";
    html += "<p>Free Heap: " + String(ESP.getFreeHeap()) + "</p>";
    html += "<p>Uptime: " + String(millis() / 1000) + " seconds</p>";
    html += "<p>WiFi RSSI: " + String(WiFi.RSSI()) + " dBm</p>";
    html += "<p>Current Mode: " + thermostatMode + "</p>";
    html += "</body></html>";
    request->send(200, "text/html", html);
});
```

### MQTT Debug Messages
```cpp
void sendDebugMQTT(String message) {
    if (mqttClient.connected()) {
        mqttClient.publish("esp32_thermostat/debug", message.c_str());
    }
}

// Usage:
sendDebugMQTT("Heating activated: temp=" + String(currentTemp));
```

## 🧪 Testing Strategies

### Unit Testing Approach
```cpp
// Create test functions for key logic
void testTemperatureLogic() {
    Serial.println("Testing temperature control logic...");
    
    // Test heating activation
    thermostatMode = "heat";
    setTempHeat = 72.0;
    controlRelays(70.0);  // Should activate heating
    
    if (heatingOn) {
        Serial.println("✓ Heating activation test passed");
    } else {
        Serial.println("✗ Heating activation test failed");
    }
}

// Call from setup() during development
void setup() {
    // ... normal setup code ...
    
    #ifdef DEBUG_MODE
    testTemperatureLogic();
    #endif
}
```

### Integration Testing
1. **MQTT Testing**: Use MQTT client to send commands and verify responses
2. **Web Interface Testing**: Test all web endpoints with various parameters
3. **Hardware Testing**: Verify relay outputs with multimeter or LED indicators
4. **Touch Testing**: Verify all buttons respond correctly

### Load Testing
```cpp
// Test system under continuous operation
void stressTest() {
    static unsigned long testStartTime = millis();
    static int testCycles = 0;
    
    // Simulate rapid temperature changes
    if (millis() - testStartTime > 1000) {
        testCycles++;
        float testTemp = 70.0 + (testCycles % 10);
        controlRelays(testTemp);
        testStartTime = millis();
        
        if (testCycles > 100) {
            Serial.println("Stress test completed successfully");
            testCycles = 0;
        }
    }
}
```

## 🔐 Best Practices

### Memory Management
```cpp
// Use static buffers to avoid fragmentation
void handleLargeData() {
    static char buffer[1024];  // Reuse buffer
    // ... process data ...
}

// Check heap regularly
void checkMemory() {
    if (ESP.getFreeHeap() < 10000) {
        Serial.println("Warning: Low memory!");
    }
}
```

### Error Handling
```cpp
// Always validate sensor readings
float readTemperature() {
    float temp = dht.readTemperature(useFahrenheit);
    if (isnan(temp)) {
        Serial.println("Error: Invalid temperature reading");
        return previousTemp;  // Use last known good value
    }
    return temp;
}

// Handle WiFi disconnections gracefully
void checkWiFiStatus() {
    if (WiFi.status() != WL_CONNECTED) {
        Serial.println("WiFi disconnected, entering offline mode");
        // Continue operation without network features
    }
}
```

### Code Organization
```cpp
// Group related constants
namespace ThermostatConstants {
    const float MIN_TEMP = 50.0;
    const float MAX_TEMP = 95.0;
    const unsigned long DISPLAY_UPDATE_INTERVAL = 1000;
    const unsigned long SENSOR_READ_INTERVAL = 2000;
}

// Use descriptive function names
void activateFirstStageHeating();
void checkForSecondStageRequirement();
void updateTemperatureDisplay();
```

## 🚀 Performance Optimization

### Display Updates
```cpp
// Only update changed elements
void updateDisplay(float temp, float humidity) {
    // Check if values actually changed before updating
    if (abs(temp - previousTemp) > 0.1) {
        updateTemperatureDisplay(temp);
        previousTemp = temp;
    }
}
```

### MQTT Optimization
```cpp
// Batch MQTT publishes to reduce network traffic
void sendMQTTBatch() {
    static unsigned long lastBatch = 0;
    
    if (millis() - lastBatch > 5000) {  // Every 5 seconds
        // Send all status updates at once
        sendMQTTData();
        lastBatch = millis();
    }
}
```

### Memory Efficiency
```cpp
// Use PROGMEM for large string constants
const char webPageTemplate[] PROGMEM = R"(
<html>
<head><title>Thermostat</title></head>
<body>%s</body>
</html>
)";
```

## 📦 Packaging and Distribution

### Firmware Preparation
```bash
# Build release version
pio run -e esp32dev

# Create firmware package
mkdir release
cp .pio/build/esp32dev/firmware.bin release/
cp README.md DOCUMENTATION.md release/
```

### PCB Manufacturing Package
The `jlcpcb/` folder contains complete manufacturing files:
- **Gerber files**: Ready for PCB fabrication
- **BOM**: Component sourcing list
- **CPL**: Pick-and-place assembly file

### Version Management
```cpp
// Update version in code
String sw_version = "1.2.2";  // Increment for releases

// Update in documentation
// Update in README.md
// Tag git repository: git tag v1.2.2
```

## 🔍 Recent Development Sessions

### Session: November 29, 2025 - Motion Wake & I2C Crash Fix (v1.2.2)

**Problem**: System crashes after 5-10 minutes of operation, motion wake not functioning properly.

**Root Causes Identified**:
1. **LD2410 radar concurrent access**: Both `checkDisplaySleep()` and `readMotionSensor()` calling `radar.check()` caused library internal buffer corruption
2. **I2C bus contention**: AHT20 sensor task and display operations accessing I2C bus simultaneously without synchronization
3. **Motion wake logic issues**: 
   - State-change wake triggering on any moving target without filtering
   - Variable scope bugs causing broken motion tracking
   - False positives from environmental noise (furniture, walls)

**Solutions Implemented**:

1. **Radar Access Protection**:
   - Removed `radar.check()` from `checkDisplaySleep()` - only called in `readMotionSensor()` now
   - Added `radarDataTimestamp` to track data freshness (500ms max age)
   - `checkDisplaySleep()` now reads cached sensor data with brief mutex locks

2. **I2C Mutex Protection**:
   ```cpp
   SemaphoreHandle_t i2cMutex = NULL;  // Protects I2C bus access
   
   // In sensorTaskFunction():
   if (xSemaphoreTake(i2cMutex, pdMS_TO_TICKS(100)) == pdTRUE) {
       if (aht.getEvent(&humidity, &temp)) {
           // Process sensor data
       }
       xSemaphoreGive(i2cMutex);
   }
   ```
   
3. **AHT20 Error Handling**:
   - Wrapped sensor reads with error detection
   - Added automatic reinitialization on failure (30s cooldown)
   - Continues operation if sensor read fails

4. **Motion Wake Improvements**:
   - **Sustained motion tracking**: 2-second debounce filters brief environmental blips
   - **Distance filtering**: Only wake on motion within 100cm (close range)
   - **Signal strength filtering**: Range 50-100 to reject weak noise and stationary targets
   - **Data freshness validation**: Skip processing stale radar data
   - **Dual-path filtering**: Applied filters to both state-change wake AND sustained motion wake
   - **Variable scope fix**: Moved `firstMotionTime` and `lastFilterLog` to function scope

5. **Motion Wake Constants** (lines ~115-127):
   ```cpp
   const unsigned long MOTION_WAKE_COOLDOWN = 5000;     // 5s after sleep
   const unsigned long MOTION_WAKE_DEBOUNCE = 2000;     // 2s sustained motion
   const int MOTION_WAKE_MAX_DISTANCE = 100;            // 100cm max range
   const unsigned long RADAR_DATA_MAX_AGE = 500;        // 500ms data freshness
   const int MOTION_WAKE_MIN_SIGNAL = 50;               // Min signal strength
   const int MOTION_WAKE_MAX_SIGNAL = 100;              // Max signal strength
   ```

**Testing Results**:
- Motion wake working correctly with hand wave
- False positives eliminated (stationary targets filtered)
- Display sleep/wake cycle functioning properly
- System stable with I2C mutex protection

**Files Modified**:
- `src/Main-Thermostat.cpp`: Added i2cMutex, improved sensor error handling, motion wake filtering

**Lessons Learned**:
1. **Thread safety critical**: Concurrent hardware access requires mutex protection even with FreeRTOS tasks
2. **Library limitations**: LD2410 library cannot handle concurrent `check()` calls - must be called from single location
3. **Data freshness matters**: Cached sensor data needs timestamp validation
4. **Variable scope awareness**: Static variables in nested blocks create separate instances
5. **Filter all paths**: Motion detection with multiple trigger paths needs consistent filtering
6. **Sustained vs instant**: Environmental noise requires debounce filtering for reliable motion detection

**Known Issues**:
- None currently - system stable with all fixes applied

### Session: November 30, 2025 - Enhanced OTA Update System (v1.3.0)

**Objective**: Improve OTA update user experience with real-time progress tracking and proper status messaging.

**Challenges**:
1. No visual feedback during firmware upload
2. Page timeout before device finished rebooting
3. Connection error messages despite successful updates
4. No visibility into flash write progress

**Solutions Implemented**:

1. **Real-Time Upload Progress**:
   - XHR-based upload with `onprogress` event tracking
   - Progress bar showing bytes transferred and ETA
   - Transfer speed calculation and display

2. **Flash Write Progress Tracking**:
   - Server-side tracking: `otaBytesWritten`, `otaTotalSize` global variables
   - Update progress during `Update.write()` operations
   - `/update_status` JSON endpoint for client polling (800ms intervals)
   - 1-second logging intervals showing flash write percentage

3. **Response Timing Optimization**:
   - Send HTTP 200 response immediately with `Connection: close` header
   - 1500ms delay before `ESP.restart()` to ensure response transmission
   - Client-side 3-second wait after flash complete before polling
   - 70-second polling window for device reboot and startup

4. **Status Message Flow**:
   - "Uploading firmware: X remaining"
   - "Upload complete, writing to flash..."
   - "Flash complete. Device rebooting..."
   - "Waiting for reboot and startup (up to 15s)..."
   - "✓ Update successful! Version X.X.X"

5. **Code Cleanup**:
   - Removed redundant standalone `/update` GET endpoint (~70 lines)
   - Integrated all OTA functionality into System tab
   - Reduced code duplication and maintenance burden

**Technical Details**:
```cpp
// Global OTA tracking variables
volatile size_t otaBytesWritten = 0;
volatile size_t otaTotalSize = 0;
volatile bool otaInProgress = false;
volatile bool otaRebooting = false;

// Upload handler updates
if (index == 0) {
    otaTotalSize = request->contentLength();
    otaInProgress = true;
}

// Track flash write progress
otaBytesWritten = index + len;
if (currentTime - otaLastUpdateLog > 1000) {
    Serial.printf("Flash write progress: %.1f%%\n", 
                  (otaBytesWritten * 100.0) / otaTotalSize);
}

// Response timing
AsyncWebServerResponse *response = request->beginResponse(200, "text/plain", "OK");
response->addHeader("Connection", "close");
request->send(response);
delay(1500);  // Allow response transmission
ESP.restart();
```

**Files Modified**:
- `src/Main-Thermostat.cpp`: Added OTA tracking, improved upload handler, removed standalone page
- `include/WebPages.h`: Enhanced System tab with progress tracking UI

**Testing Results**:
- Upload progress bar shows accurate real-time progress
- Flash write progress updates every second
- No connection error messages - clean reboot handling
- Version verification confirms successful update
- Reduced flash usage by ~2KB with code cleanup

**Lessons Learned**:
1. **Browser XHR behavior**: Connection drops on reboot cause errors even after successful response - must send response before restart
2. **Timing is critical**: Device needs adequate time (3-5s) for reboot and initialization before polling
3. **Progress visibility**: Users need feedback during both upload and flash write phases
4. **Code organization**: Integrated features in tabs provide better UX than standalone pages

This development guide provides the foundation for extending and maintaining the Smart Thermostat Alt Firmware project. Follow these patterns and practices to ensure code quality and system reliability.

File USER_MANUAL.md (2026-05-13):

# ESP32-S3 Simple Thermostat - User Manual

**Version 1.5.001 | May 2026**

---

## Table of Contents

1. [Introduction](#introduction)
2. [Initial Setup](#initial-setup)
3. [Touch Screen Interface](#touch-screen-interface)
4. [Web Interface](#web-interface)
5. [Home Assistant Integration](#home-assistant-integration)
6. [Shower Mode](#shower-mode)
7. [Weather Integration](#weather-integration)
8. [Advanced Features](#advanced-features)
9. [Troubleshooting](#troubleshooting)
10. [Maintenance](#maintenance)

---

## Introduction

The ESP32-S3 Simple Thermostat is a fully-featured smart thermostat designed for DIY home automation enthusiasts. It combines local touch control with modern web and MQTT/Home Assistant integration.

### Key Capabilities
- **Local Control**: Full functionality via touch screen, no internet required
- **Web Interface**: Complete configuration and monitoring from any browser
- **Smart Home Integration**: Native MQTT and Home Assistant support
- **Advanced Scheduling**: 7-day schedule with day/night periods
- **Multi-Stage HVAC**: Support for 2-stage heating and cooling
- **Weather Display**: Live weather data from OpenWeatherMap or Home Assistant
- **Shower Mode**: Temporarily pause heating with countdown timer

---

## Initial Setup

### First Power-On

1. **Power Connection**: Connect 5V power to the thermostat
2. **Display Activation**: The TFT display will initialize and show the boot screen
3. **Touch Screen**: Pre-calibrated for immediate use - no calibration required at startup
   - If touch accuracy is poor, you can calibrate later via Settings → System Info
4. **WiFi Configuration**: 
   - Tap anywhere on the boot screen
   - Enter your WiFi SSID and password using the on-screen keyboard
   - Tap "Connect" to join the network

### Finding Your Thermostat

Once connected to WiFi, the thermostat will display its IP address on screen. You can:
- Access the web interface at `http://[IP-ADDRESS]`
- Find it in your router's DHCP client list
- Use the hostname (default: `ESP32-Thermostat`) if your network supports mDNS

### Basic Configuration

1. Open the web interface in your browser
2. Navigate to the **Settings** tab
3. Configure essential settings:
   - **Temperature Unit**: Fahrenheit or Celsius
   - **Heat/Cool Setpoints**: Default comfort temperatures
   - **Temperature Swing**: Hysteresis to prevent short-cycling (default 1.0°)
   - **Time Zone**: Your local timezone for accurate scheduling

---

## Touch Screen Interface

### Main Display

The touch screen shows real-time information:

**Top Section**:
- Current time and date
- WiFi signal strength icon
- MQTT connection status (when enabled)

**Center Section**:
- **Large Temperature**: Current room temperature
- **Humidity**: Current relative humidity percentage
- **Target Temperature**: Current heating/cooling setpoint
- **Weather** (when configured): Outdoor temperature and conditions
- **Barometric Pressure** (with BME280): Atmospheric pressure in inHg

**Bottom Section**:
- **Mode Indicator**: Heat/Cool/Auto/Off with color coding
  - Red: Heating active
  - Blue: Cooling active
  - Orange: Auto mode
  - Gray: System off
- **Fan Status**: Shows when fan is running
- **Shower Mode Timer** (when active): Countdown display "ON for X min Y sec"

### Touch Controls

**Tap Mode Button (Bottom Left)**:
- Cycles through: Off → Heat → Cool → Auto → Off
- Current mode is highlighted

**Tap Fan Button (Bottom Center)**:
- Cycles through: Auto → On → Cycle → Auto
- **Auto**: Fan runs only with heating/cooling
- **On**: Fan runs continuously
- **Cycle**: Fan runs on schedule (configurable minutes per hour)

**Tap Setpoint (Center)**:
- Displays temperature adjustment controls
- **Up/Down arrows**: Adjust temperature in 0.5° increments
- **Range**: 50°F - 90°F (10°C - 32°C)
- **Auto mode**: Tap to switch between heat and cool setpoints

**Tap Setpoint When Shower Mode Enabled**:
- Toggles shower mode on/off
- Countdown timer replaces setpoint display when active
- Heating is paused until timer expires or manually turned off

### Visual Indicators

**WiFi Icon**:
- Connected: Solid icon
- Disconnected: Flashing icon
- No configuration: No icon

**MQTT Icon**:
- Connected: Cloud icon
- Disconnected: Cloud with X
- Disabled: No icon

**Active Relay Indicators**:
- Heat Stage 1: H1
- Heat Stage 2: H2
- Cool Stage 1: C1
- Cool Stage 2: C2
- Fan: FAN
- Reversing Valve: RV (for heat pumps)
- EU Dehumidification: `DEHUM ON` / `DEHUM OFF` when EU humidity control is enabled

**OFF Mode Display Behavior**:
- In OFF mode, the upper-right display continues showing current temperature (`Cur`) and setpoint (`Set`).

---

## Web Interface

Access the web interface by navigating to your thermostat's IP address in any browser.

### Status Tab

**Real-Time Monitoring**:
- Current temperature and humidity with large display
- Thermostat mode and fan mode indicators
- System status showing all relay states
- Weather information (when configured)
- Hydronic water temperature (when enabled)

**Relay Status Indicators**:
- Each relay shows ON/OFF state
- Active relays are highlighted
- Stage 2 relays only shown when enabled in settings

### Settings Tab

**Basic Settings**:
- **Thermostat Mode**: Off/Heat/Cool/Auto
- **Fan Mode**: Auto/On/Cycle
- **Temperature Setpoints**: Separate values for Heat, Cool, and Auto modes
- **Temperature Swing**: Hysteresis setting (0.5° - 3.0°)
- **Auto Mode Swing**: Additional swing for Auto mode (1.0° - 5.0°)

**Shower Mode Settings**:
- **Enable Shower Mode**: Master enable/disable checkbox
- **Duration**: Set pause time from 5 to 120 minutes (default 30)
- When enabled, touch screen setpoint becomes shower mode toggle
- Countdown timer appears on display when active
- Heating automatically paused until timer expires

**Multi-Stage HVAC**:
- **Stage 2 Heating**: Enable/disable secondary heat
- **Stage 2 Cooling**: Enable/disable secondary cooling
- **Reversing Valve**: For heat pump systems (mutually exclusive with Stage 2 Heat)
- **Stage 1 Runtime**: Minimum time before activating Stage 2 (default 3 minutes)
- **Stage 2 Delta**: Temperature difference required for Stage 2 (default 2.0°)

**Regional HVAC (US/EU)**:
- **Thermostat Region Mode**: Select US or EU control behavior.
- **US Mode**: Temperature-driven cooling behavior.
- **EU Mode**: Optional humidity-driven dehumidification support.
- **EU Humidity Dehumidification**:
   - Enable/disable humidity cooling assist
   - Relay selection: Cool Stage 1, Cool Stage 2, or Pump relay
   - Setpoint and deadband configuration

**Fan Settings**:
- **Fan Relay Needed**: Enable if fan requires separate relay control
- **Fan Minutes Per Hour**: For Cycle mode, set how many minutes per hour fan runs (5-60)

**Hydronic Heating**:
- **Enable Hydronic Heating**: For radiant floor or baseboard systems
- **Low Temperature Threshold**: Minimum water temperature to enable heating (default 110°F)
- **High Temperature Threshold**: Maximum water temperature cutoff (default 140°F)
- Requires DS18B20 sensor connected to GPIO 4

**Sensor Calibration**:
- **Temperature Offset**: Correct sensor bias (-10° to +10°)
- **Humidity Offset**: Correct humidity sensor bias (-20% to +20%)

**Display Settings**:
- **Brightness**: Adjust TFT backlight (0-255, default 64)
- **Display Sleep**: Enable automatic dimming
- **Sleep Timeout**: Minutes of inactivity before sleep (1-60, default 5)
- **Use 24-Hour Clock**: Toggle 12/24 hour time format
- **Use Fahrenheit**: Toggle between °F and °C

**WiFi Settings**:
- **SSID**: Network name
- **Password**: Network password
- Changing WiFi requires reboot to take effect

**MQTT/Home Assistant**:
- **Enable MQTT**: Turn on Home Assistant integration
- **MQTT Server**: Broker IP address or hostname
- **MQTT Port**: Broker port (default 1883)
- **Username**: MQTT authentication username
- **Password**: MQTT authentication password
- **Time Zone**: Required for proper scheduling with Home Assistant

**Save Settings**:
- Click "Save All Settings" button at bottom
- Settings are immediately applied and saved to flash memory
- Some settings (WiFi, timezone) may require reboot

### Schedule Tab

**7-Day Scheduling System**:

Configure independent schedules for each day of the week.

**Day Schedule Table**:
- **Day Column**: Day of week (Sunday - Saturday)
- **Enable Column**: Toggle to enable/disable schedule for that day
- **Day Period Column**:
  - Time: Hour and minute for day period start (default 6:00 AM)
  - Active checkbox: Enable/disable this period
- **Day Temps Column**:
  - Heat: Target heating temperature
  - Cool: Target cooling temperature
- **Night Period Column**:
  - Time: Hour and minute for night period start (default 10:00 PM)
  - Active checkbox: Enable/disable this period
- **Night Temps Column**:
  - Heat: Target heating temperature
  - Cool: Target cooling temperature

**Schedule Control Section**:
- **Enable 7-Day Schedule**: Master on/off switch
- **Schedule Override**:
  - **Follow Schedule**: Normal operation, follow configured schedule
  - **Override for 2 Hours**: Temporarily use current setpoint, auto-resume after 2 hours
  - **Override Until Resumed**: Permanently use current setpoint until manually resumed

**Current Status Display**:
- Shows whether schedule is active
- Displays current active period (Day or Night)
- Indicates if override is active

**Using the Schedule**:
1. Click "Enable 7-Day Schedule" to activate
2. Configure times and temperatures for each day
3. Enable/disable individual days as needed
4. Enable/disable individual periods (day or night) for flexibility
5. Click "Save Schedule" to apply changes
6. Use override controls when you need temporary manual control

### Weather Tab

**Weather Source Selection**:
Choose between OpenWeatherMap or Home Assistant.

**OpenWeatherMap Configuration**:
1. Select "OpenWeatherMap" from Weather Source dropdown
2. Enter your API key (get free key at openweathermap.org)
3. Enter City, State/Province, and Country
4. Set update interval (5-60 minutes, default 15)
5. Click "Save Settings"

**Home Assistant Configuration**:
1. Select "Home Assistant" from Weather Source dropdown
2. Enter Home Assistant URL (e.g., http://192.168.1.100:8123)
3. Enter Long-Lived Access Token (create in HA profile settings)
4. Enter weather entity ID (e.g., weather.home)
5. Set update interval (5-60 minutes, default 15)
6. Click "Save Settings"

**Weather Display**:
- Weather appears on Status tab as a card
- Shows current temperature, conditions, and high/low
- Weather icon displays on touch screen
- Color-coded icons based on conditions

**Disabling Weather**:
- Select "Disabled" from Weather Source dropdown
- Weather information will be removed from display and Status tab

### System Tab

**System Information**:
- Firmware version and build date
- Device hostname
- WiFi network and IP address
- MAC address
- Free heap memory
- System uptime
- Flash size and chip model
- CPU frequency

**Firmware Update**:
1. Click "Select Firmware File (.bin)" button
2. Choose firmware .bin file from your computer
3. Click "Upload & Install" button
4. **Do not power off** during update
5. Progress bar shows upload and flash write progress
6. Device automatically reboots when complete
7. Page shows success message with new version number

**Touch Screen Calibration** (On-Device):
Access through Settings menu on the touch screen:
1. Tap Settings button on main screen
2. Navigate to "System Info" page
3. Tap **Calibrate** button (top right)
4. Follow on-screen instructions to touch corners as indicated
5. Calibration is automatically saved to permanent storage
6. Tap **Clear Cal** button (middle right) to reset calibration and reboot
7. After clearing, device uses hardware-tested default values until recalibrated

**Calibration Notes**:
- Default calibration values are pre-loaded for immediate use
- Startup is never blocked - system always boots with working touch
- Recommended to calibrate if touch accuracy is poor
- Clear Cal useful for testing or recovering from bad calibration

**System Actions**:
- **Reboot Device**: Restart the thermostat (requires confirmation)
- **Factory Reset**: Restore all settings to defaults (requires confirmation)

---

## Home Assistant Integration

### Automatic Discovery

When MQTT is enabled, the thermostat automatically registers with Home Assistant:

1. Go to Settings tab in web interface
2. Enable MQTT
3. Configure MQTT broker details
4. Click "Save All Settings"
5. Thermostat will appear in Home Assistant Integrations

### Climate Entity

**Available in Home Assistant**:
- Current temperature and humidity
- Thermostat mode (off/heat/cool/auto)
- Fan mode (auto/on/cycle)
- Target temperature setpoints
- Current HVAC action (idle/heating/cooling/fan)

**Control from Home Assistant**:
- Change thermostat mode
- Adjust target temperature
- Switch fan modes
- View real-time status

### Additional Entities

**Motion Sensor** (if LD2410 connected):
- Binary sensor for motion detection
- Auto-discovery enabled
- Shows in Home Assistant as motion detector

**Barometric Pressure** (if BME280 used):
- Sensor entity showing atmospheric pressure
- Unit: inches of mercury (inHg)
- State class: measurement

**Shower Mode Switch** (if enabled in settings):
- Switch entity to toggle shower mode on/off
- Shows countdown status
- Auto-discovery when feature enabled

### Schedule Synchronization 🔄

The thermostat supports **bidirectional schedule synchronization** with Home Assistant - changes sync automatically in both directions.

#### How It Works

**Device → Home Assistant (Inbound)**:
1. Thermostat publishes complete 7-day schedule to MQTT on startup and config changes
2. HA automation receives schedule updates automatically
3. Creates/updates 77 helper entities per thermostat (times, temperatures, enabled status)
4. Changes made on device instantly appear in HA helpers

**Home Assistant → Device (Outbound)**:
1. Change any schedule helper in HA (day/night time or temperature)
2. Automation detects change and publishes to MQTT
3. Thermostat receives update immediately
4. Schedule applies to device without manual sync

#### Setup Instructions

**Step 1: Prepare Home Assistant Files**

1. Locate HA packages directory (usually `/config/packages/`)
2. Copy `multi_thermostat_schedule_sync.yaml` from repository to packages directory
3. Generate per-device schedule package:
   ```bash
   ./generate_schedule_package.sh shop_thermostat
   ./generate_schedule_package.sh studio_thermostat
   # Repeat for each thermostat
   ```

**Step 2: Add to HA Configuration**

In `configuration.yaml`:
```yaml
homeassistant:
  packages:
    shop_thermostat: !include packages/shop_thermostat_schedule.yaml
    studio_thermostat: !include packages/studio_thermostat_schedule.yaml
```

Or use UI: Settings > Devices & Services > Packages

**Step 3: Reload in Home Assistant**

1. Go to Developer Tools > YAML
2. Click "Reload Automations"
3. Wait for reload to complete
4. Helpers should appear in Settings > Devices & Services > Helpers

#### What Gets Created

**Per Thermostat** (77 helpers each):
- 14 input_datetime helpers (times for day/night periods)
- 42 input_number helpers (heat/cool/auto temps for each period)
- 21 input_boolean helpers (enabled status for each period and day)

**Automations**:
- 1 centralized inbound automation (handles all devices)
- 77 outbound automations per thermostat (one per parameter)

**Total for 3 thermostats**:
- 231 helpers
- 1 + (77 × 3) = 232 automations
- Zero manual configuration per device

#### Multi-Thermostat Support

Add as many thermostats as you need:

```bash
# Generate packages for each device
./generate_schedule_package.sh shop_thermostat
./generate_schedule_package.sh studio_thermostat
./generate_schedule_package.sh house_thermostat
```

The centralized automation automatically handles all of them based on MQTT topic.

#### Editing Schedules in Home Assistant

1. Go to Settings > Devices & Services > Helpers
2. Search for your thermostat name (e.g., "shop_thermostat")
3. Adjust times:
   - Tap the time helper to modify
   - Change to new time
   - Change automatically syncs to device within seconds

4. Adjust temperatures:
   - Tap the number helper
   - Set new heat/cool/auto temperature
   - Publishes to device immediately

5. Enable/disable periods:
   - Toggle boolean helper on/off
   - Takes effect immediately on device
- Automatically removed when feature disabled

### MQTT Topics

**State Topics** (published by thermostat):
- `hostname/current_temperature`: Current temp reading
- `hostname/current_humidity`: Current humidity reading
- `hostname/target_temperature`: Current setpoint
- `hostname/mode`: Thermostat mode
- `hostname/fan_mode`: Fan mode
- `hostname/action`: Current HVAC action
- `hostname/availability`: Online/offline status
- `hostname/motion_detected`: Motion sensor state (true/false)
- `hostname/barometric_pressure`: Pressure in inHg
- `hostname/shower_mode`: Shower mode state (ON/OFF)
- `hostname/shower_time_remaining`: Minutes remaining in shower mode

**Command Topics** (subscribed by thermostat):
- `hostname/mode/set`: Set thermostat mode
- `hostname/fan_mode/set`: Set fan mode
- `hostname/target_temperature/set`: Set target temperature
- `hostname/shower_mode/set`: Toggle shower mode (ON/OFF)

---

## Shower Mode

### What is Shower Mode?

Shower Mode temporarily pauses heating to prevent the HVAC system from running while hot water is being used for showers. This is particularly useful in homes where running the furnace and water heater simultaneously can cause issues.

### Enabling Shower Mode

1. Go to **Settings** tab in web interface
2. Scroll to **Shower Mode Settings** section
3. Check **Enable Shower Mode** checkbox
4. Set **Duration** (5-120 minutes, default 30)
5. Click **Save All Settings**

Once enabled:
- Touch screen setpoint area becomes shower mode toggle
- Shower mode switch appears in Home Assistant (if MQTT enabled)
- Countdown timer replaces setpoint display when active

### Using Shower Mode

**Via Touch Screen**:
1. Tap the setpoint area in center of display
2. Shower mode activates immediately
3. Display shows "SHOWER MODE" and countdown timer
4. Tap again to cancel early
5. Heating automatically resumes when timer expires

**Via Home Assistant**:
1. Find "Shower Mode" switch entity
2. Toggle switch ON to activate
3. Switch shows remaining time
4. Toggle OFF to cancel early
5. Automatically turns OFF when timer expires

**Via Web Interface**:
- Shower mode status visible on Status tab
- Cannot be toggled directly from web interface
- Use touch screen or Home Assistant to control

### During Shower Mode

**What Happens**:
- Heating is completely blocked
- Countdown timer displays on screen: "ON for X min Y sec"
- Timer updates every second
- Cooling and fan operation are NOT affected
- Timer persists until completion (does not reset on reboot)

**5-Second Warning**:
- When 5 seconds remain, buzzer sounds once per second
- 5 total beeps: one for each remaining second
- Each beep is 100ms duration
- Helps remind you shower mode is about to end

**When Timer Expires**:
- Shower mode automatically deactivates
- Display returns to normal setpoint view
- Heating operation resumes normally
- Home Assistant switch turns OFF
- MQTT status updated

### Disabling Shower Mode Feature

To completely remove shower mode:
1. Go to **Settings** tab
2. Uncheck **Enable Shower Mode**
3. Click **Save All Settings**
4. Setpoint area returns to normal function
5. Shower mode switch removed from Home Assistant
6. Any active shower mode immediately cancelled

---

## Weather Integration

### Weather Sources

Choose between two weather data providers:

**OpenWeatherMap**:
- Free API available at openweathermap.org
- Requires API key registration
- Provides current conditions and forecast
- Updates via internet connection
- Best for most users

**Home Assistant**:
- Uses weather entity from your HA installation
- No separate API key needed
- Integrates with your existing HA weather provider
- Requires HA long-lived access token
- Best if you already use HA weather

### Setting Up OpenWeatherMap

1. **Get API Key**:
   - Visit openweathermap.org
   - Create free account
   - Go to API keys section
   - Copy your API key

2. **Configure Thermostat**:
   - Open web interface → Weather tab
   - Select "OpenWeatherMap" from dropdown
   - Paste API key
   - Enter city name (e.g., "Prairie Farm")
   - Enter state/province code (e.g., "WI")
   - Enter country code (e.g., "US")
   - Set update interval (default 15 minutes)
   - Click "Save Settings"

3. **Verify**:
   - Check Status tab for weather card
   - Touch screen should show weather icon and temperature
   - Wait for first update (may take up to interval time)

### Setting Up Home Assistant Weather

1. **Find Weather Entity**:
   - In Home Assistant, go to Developer Tools → States
   - Find your weather entity (starts with "weather.")
   - Copy the entity ID (e.g., "weather.home")

2. **Create Long-Lived Token**:
   - In Home Assistant, click your profile (bottom left)
   - Scroll to "Long-Lived Access Tokens"
   - Click "Create Token"
   - Give it a name (e.g., "Thermostat")
   - Copy the generated token

3. **Configure Thermostat**:
   - Open web interface → Weather tab
   - Select "Home Assistant" from dropdown
   - Enter HA URL (e.g., "http://192.168.1.100:8123")
   - Paste access token
   - Enter weather entity ID
   - Set update interval (default 15 minutes)
   - Click "Save Settings"

4. **Verify**:
   - Check Status tab for weather card
   - Touch screen should show weather icon and temperature
   - Updates should sync with HA weather

### Weather Display

**Status Tab Card**:
- Current temperature
- Weather description (e.g., "clear sky", "light rain")
- High and low temperatures (when available)
- Appears as a card in status grid

**Touch Screen Display**:
- Weather icon in corner
- Outdoor temperature
- Color-coded based on conditions:
  - Clear: Yellow
  - Cloudy: Gray
  - Rain: Blue
  - Snow: Light blue
  - Thunderstorm: Purple

### Update Intervals

**Configurable Range**: 5-60 minutes

**Recommended Settings**:
- 15 minutes: Good balance of freshness and API calls
- 5 minutes: For rapidly changing weather (uses more API calls)
- 30-60 minutes: For stable weather or limited API quota

**What Happens During Update**:
- Thermostat fetches new data from provider
- Display updates automatically
- Old data remains visible until new data received
- No interruption to HVAC operation

### Troubleshooting Weather

**Weather Not Showing**:
- Verify weather source is not set to "Disabled"
- Check that API key or access token is correct
- Ensure city/state/country are spelled correctly
- Verify internet connection is working
- Check serial debug output for error messages

**Weather Shows Old Data**:
- Confirm update interval is reasonable
- Check that provider service is online
- Verify API key has not expired
- For HA: ensure access token is still valid

**Wrong Location Weather**:
- Double-check city and state spelling
- Try using city name only without state
- For international locations, verify country code is correct (2-letter ISO code)

---

## Advanced Features

### Multi-Stage HVAC Operation

**How Staging Works**:

The thermostat intelligently controls 2-stage heating and cooling systems:

1. **Stage 1 Activation**:
   - When temperature crosses setpoint + swing threshold
   - Stage 1 relay activates immediately
   - Timer starts tracking Stage 1 runtime

2. **Stage 2 Activation**:
   - Requires Stage 1 to run for minimum time (Stage 1 Runtime setting)
   - Temperature must be Stage 2 Delta away from setpoint
   - Example: If setpoint is 68°F, Stage 2 Delta is 2°F, and it's heating:
     - Stage 2 activates when temp drops to 66°F or below
     - Only after Stage 1 has run for minimum runtime

3. **Staging Down**:
   - As temperature approaches setpoint, Stage 2 deactivates first
   - Stage 1 continues until temperature is within swing
   - Both stages deactivate when temperature reaches setpoint

**Configuration**:
- Enable Stage 2 Heating/Cooling in Settings tab
- Set Stage 1 Runtime: Minimum time before Stage 2 can activate (default 3 minutes)
- Set Stage 2 Delta: Temperature difference required for Stage 2 (default 2.0°)

**Benefits**:
- Prevents system short-cycling
- Optimizes energy efficiency
- Provides comfort with intelligent staging
- Protects HVAC equipment from excessive cycling

### Reversing Valve (Heat Pump)

For heat pump systems with reversing valve:

**Configuration**:
- Enable "Reversing Valve" in Settings tab
- **Note**: Mutually exclusive with Stage 2 Heating
- Reversing valve relay controls heating/cooling mode

**Operation**:
- Valve energized: Heat mode
- Valve de-energized: Cool mode
- Heat Relay 2 pin controls valve
- Automatically switches based on thermostat mode

### Hydronic Heating

For radiant floor or baseboard hydronic systems:

**Hardware Requirements**:
- DS18B20 temperature sensor on GPIO 4
- Connected to water supply or return line
- Properly sealed and waterproofed

**Configuration**:
1. Enable "Hydronic Heating" in Settings tab
2. Set Low Temperature Threshold (default 110°F)
3. Set High Temperature Threshold (default 140°F)
4. Click "Save Settings"

**Safety Operation**:
- Heating disabled if water temp < Low Threshold
- Heating disabled if water temp > High Threshold
- "BOILER LOCKOUT" warning displays on screen when locked out
- Prevents system from running with insufficient hot water
- Protects against overheating conditions

**Display**:
- Hydronic temperature shows on Status tab
- Displayed in °F regardless of main unit setting
- Updates in real-time
- Shows on touch screen when enabled

### Fan Cycle Mode

**Purpose**: Circulate air periodically even when HVAC is not running

**Configuration**:
1. Set Fan Mode to "Cycle" (touch screen or Settings tab)
2. Set "Fan Minutes Per Hour" in Settings (5-60 minutes)
3. Example: Setting of 15 means fan runs 15 minutes per hour

**Operation**:
- Fan runs at beginning of each hour
- Runs for configured number of minutes
- Automatically turns off after time elapses
- Resumes next hour on schedule
- **Boot Behavior**: First cycle is skipped after power-on/reboot to prevent immediate fan run

**Benefits**:
- Improves air circulation
- Helps even out temperature
- Reduces hot/cold spots
- Filters air even when HVAC off

### Display Sleep Mode

**Purpose**: Reduce power consumption and screen burn-in

**Configuration**:
1. Enable "Display Sleep" in Settings tab
2. Set timeout in minutes (1-60, default 5)
3. Display dims after inactivity period

**Behavior**:
- Touch activity resets timeout timer
- Motion detection (if LD2410 connected) wakes display
- Display dims to configured brightness level when sleeping
- Full brightness restored on wake

**When to Use**:
- Extended periods without interaction
- Reduce power consumption
- Minimize screen wear
- Less light pollution at night

### Motion Detection Wake

**Hardware**: LD2410 24GHz mmWave radar sensor

**Connections**:
- RX: GPIO 15
- TX: GPIO 16
- Motion Output: GPIO 18
- Power: 5V and GND

**Operation**:
- Detects motion via mmWave radar
- Automatically wakes display from sleep
- Publishes motion state to Home Assistant (if MQTT enabled)
- Works even if sensor doesn't respond to UART commands

**Configuration**:
- No setup required - auto-detected on boot
- Motion sensor appears in Home Assistant automatically
- Display wake happens instantaneously
- No false triggers from temperature changes

---

## Troubleshooting

### WiFi Connection Issues

**Can't Connect to Network**:
- Verify SSID and password are correct (case-sensitive)
- Check that network is 2.4GHz (ESP32 doesn't support 5GHz)
- Move thermostat closer to router temporarily
- Check router for MAC address filtering
- Verify router has available DHCP addresses
- Try resetting WiFi credentials via boot button

**Intermittent Disconnections**:
- Check WiFi signal strength icon on display
- Move router closer or add WiFi extender
- Check for interference from other 2.4GHz devices
- Verify router is not disconnecting idle devices
- Check router logs for connection drops

### Display Issues

**Touch Not Responding**:
- Calibrate touch screen through on-device Settings → System Info → Calibrate button
- If touch is completely unresponsive, access web interface and reboot to restore defaults
- Clean display surface - dirt affects resistive touch
- Check for physical damage to touch layer
- Verify display cable connections
- Try Clear Cal button to reset calibration, or factory reset if calibration fails

**Display Flickering**:
- Normal during updates (weather, time changes)
- Excessive flickering may indicate power issue
- Check 5V power supply is stable and adequate (2A minimum)
- Verify all display cable connections are secure

**Display Shows Garbage**:
- Power cycle the thermostat
- Check display cable for damage
- Verify SPI connections are correct
- May indicate failing display - consider replacement

**Display Stays Dim**:
- Check Display Sleep setting - may be set too low
- Adjust Brightness setting in Settings tab
- Motion sensor may not be detecting movement
- Try tapping screen to wake

### Sensor Issues

**Temperature Reading Incorrect**:
- Use Temperature Offset in Settings to calibrate
- Verify sensor is not in direct sunlight or airflow
- Check sensor is properly connected to I2C pins
- Allow 15-30 minutes for sensor to stabilize after power-on
- Consider sensor placement - away from heat sources

**Humidity Reading Incorrect**:
- Use Humidity Offset in Settings to calibrate
- Humidity sensors drift over time - recalibrate annually
- AHT20 typically accurate ±2-3%
- Verify sensor is not obstructed or covered

**No Sensor Detected**:
- Check I2C connections (SDA: GPIO 8, SCL: GPIO 9)
- Verify sensor power (3.3V)
- Check pull-up resistors on I2C lines
- Try different sensor if available
- Check serial debug for I2C scan results

**Hydronic Temp Not Showing**:
- Verify DS18B20 is connected to GPIO 4
- Check OneWire connections and 4.7K pull-up resistor
- Ensure sensor is properly sealed and waterproofed
- Enable Hydronic Heating in Settings
- Check serial debug for DS18B20 detection

### MQTT/Home Assistant Issues

**Thermostat Not Appearing in HA**:
- Verify MQTT is enabled in thermostat settings
- Check MQTT broker IP and port are correct
- Verify MQTT username and password
- Check broker is running and accessible
- Look in HA MQTT integration for discovery messages
- Check HA Configuration → Integrations for pending setup

**Thermostat Shows "Unavailable" in HA**:
- Check MQTT connection status icon on display
- Verify broker is running
- Check network connectivity
- Restart MQTT broker
- Restart Home Assistant
- Check thermostat is powered on and connected to WiFi

**Commands from HA Don't Work**:
- Verify thermostat is subscribed to command topics
- Check MQTT Explorer or similar tool for message flow
- Ensure topics match HA climate entity configuration
- Try sending commands directly via MQTT tool
- Check serial debug for received MQTT messages

**Motion Sensor Not Showing in HA**:
- Verify LD2410 is connected and detected
- Check MQTT is enabled
- Motion discovery sent only on boot - restart thermostat
- Check HA MQTT integration for sensor entity
- Verify motion detection is working on display

### Heating/Cooling Issues

**System Not Heating/Cooling**:
- Check thermostat mode is correct (Heat/Cool/Auto)
- Verify setpoint is appropriate (below temp for cool, above for heat)
- Check all relay connections to HVAC system
- Test relays manually to verify they activate
- Check HVAC system breakers and power
- Verify HVAC system works with old thermostat
- Check serial debug for relay activation messages

**Short Cycling**:
- Increase Temperature Swing setting (try 1.5° or 2.0°)
- Verify Stage 1 Runtime is adequate (minimum 3 minutes)
- Check for proper system sizing
- Ensure air filters are clean
- Verify HVAC system is functioning correctly

**Stage 2 Never Activates**:
- Verify Stage 2 is enabled in settings
- Check Stage 1 Runtime setting (must run before Stage 2)
- Increase Stage 2 Delta if Stage 2 activating too late
- Check that Stage 2 relay is connected
- Verify system has Stage 2 capability

**Hydronic Lockout**:
- Check water temperature via Status tab
- Verify DS18B20 sensor is working correctly
- Check boiler is running and heating water
- Adjust Low Temperature Threshold if too high
- Ensure circulation pump is running
- Check for air in hydronic system

### Schedule Issues

**Schedule Not Running**:
- Verify "Enable 7-Day Schedule" is turned on
- Check that current day is enabled in schedule table
- Verify at least one period (day or night) is active
- Ensure times are set correctly (24-hour format)
- Check Time Zone is configured correctly in settings
- Verify current time display is accurate

**Wrong Temperature at Scheduled Time**:
- Check which period (day or night) should be active
- Verify period transition time is correct
- Ensure period Active checkbox is checked
- Check Heat/Cool temperature values for that period
- Verify thermostat mode matches schedule intent

**Override Not Working**:
- Select "Override for 2 Hours" or "Override Until Resumed"
- Adjust setpoint via touch screen to set override temperature
- Check schedule override status on Schedule tab
- Verify "Follow Schedule" is not selected

### Weather Issues

See [Weather Integration](#weather-integration) section for detailed troubleshooting.

### General Troubleshooting

**System Unresponsive**:
- Power cycle the thermostat (unplug and replug)
- Check for adequate power supply (5V, 2A minimum)
- Try factory reset via boot button
- Check serial debug output for errors
- Verify firmware is not corrupted

**Factory Reset**:
1. Press and hold boot button (10+ seconds)
2. Release when display shows reset confirmation
3. All settings restored to defaults
4. WiFi credentials cleared
5. Reconfigure from scratch via touch screen

**Firmware Update Failed**:
- Ensure .bin file is valid firmware for ESP32-S3
- Try uploading again - check progress bar reaches 100%
- **Do not power off during update**
- Check web browser console for JavaScript errors
- Use wired connection if WiFi is unstable
- Try different browser if problems persist

---

## Maintenance

### Regular Maintenance

**Monthly**:
- Check temperature accuracy with known good thermometer
- Verify humidity reading is reasonable
- Test all thermostat modes (Heat/Cool/Auto/Off)
- Test all fan modes (Auto/On/Cycle)
- Clean display with soft, slightly damp cloth

**Every 3 Months**:
- Recalibrate temperature if drifting (use offset setting)
- Check for firmware updates
- Review and adjust schedule as seasons change
- Test HVAC system operation in all modes
- Check MQTT/Home Assistant integration still working

**Annually**:
- Recalibrate humidity sensor (can drift over time)
- Review all settings and adjust for seasonal changes
- Test factory reset procedure (in non-critical period)
- Back up schedule configuration (take screenshots)
- Clean around thermostat and sensors
- Check all wiring connections are secure

### Backup and Restore

**Manual Backup**:
The thermostat does not have automatic config export, but you can manually document:
1. Take screenshots of all Settings tab pages
2. Screenshot complete Schedule tab
3. Note MQTT settings and credentials
4. Document WiFi configuration
5. Record any calibration offsets

**Restore After Reset**:
1. Factory reset via boot button or web interface
2. Connect to WiFi via touch screen
3. Access web interface
4. Restore settings from screenshots
5. Reconfigure MQTT if needed
6. Restore schedule configuration
7. Test all functionality

### Firmware Updates

**Check for Updates**:
- Visit GitHub repository releases page
- Check current version: System tab or touch screen
- Review changelog for new features and fixes
- Download appropriate .bin file for your ESP32 variant

**Update Procedure**:
1. Navigate to System tab in web interface
2. Click "Select Firmware File (.bin)"
3. Choose downloaded .bin file
4. Click "Upload & Install"
5. Wait for upload progress (do not refresh page)
6. Wait for flash write progress
7. Device reboots automatically
8. Verify new version on System tab

**Update Best Practices**:
- Perform updates during non-critical times
- Ensure stable power supply
- Use wired connection if possible
- Don't interrupt update process
- Keep old firmware .bin file in case rollback needed
- Test all functions after update

### When to Contact Support

Contact via GitHub Issues if you experience:
- Persistent crashes or reboots
- Hardware failures not resolved by troubleshooting
- Firmware bugs or unexpected behavior
- Feature requests or enhancement ideas
- Questions not answered in this manual

**Information to Provide**:
- Firmware version
- Hardware variant (N4/N8/N16/N32)
- Detailed description of problem
- Steps to reproduce issue
- Serial debug output if possible
- Screenshots if relevant

---

## Safety Information

### Electrical Safety

- **High Voltage Warning**: HVAC systems operate at 24VAC or higher
- **Turn off power** at breaker before wiring thermostat
- **Verify power is off** with multimeter before touching wires
- Follow local electrical codes and regulations
- Hire licensed electrician if unsure about wiring
- Keep thermostat and wiring away from water sources

### Installation Safety

- Mount thermostat on interior wall away from:
  - Direct sunlight
  - Heat sources (radiators, lamps, appliances)
  - Drafts (doors, windows, vents)
  - Moisture sources (bathrooms, kitchens)
- Ensure adequate ventilation around thermostat
- Use appropriate mounting hardware for wall type
- Keep cables organized and secured

### Operation Safety

- Do not cover thermostat or block airflow around sensors
- Keep thermostat clean and dry
- Do not operate with damaged display or housing
- Replace thermostat if showing signs of damage
- Unplug during electrical storms if possible

### Child Safety

- Install at appropriate height (48-52 inches recommended)
- Consider using Schedule and Home Assistant control to prevent manual changes
- Touch screen is not dangerous but should be supervised
- Factory reset requires 10-second button hold (prevents accidental reset)

---

## Appendix

### Default Settings

- Temperature Unit: Fahrenheit
- Heat Setpoint: 68°F
- Cool Setpoint: 75°F
- Auto Setpoint: 70°F
- Temperature Swing: 1.0°
- Auto Mode Swing: 1.5°
- Fan Mode: Auto
- Stage 1 Runtime: 3 minutes
- Stage 2 Delta: 2.0°
- Fan Minutes Per Hour: 15
- Shower Mode: Disabled
- Shower Duration: 30 minutes
- Display Brightness: 64
- Display Sleep: Enabled
- Sleep Timeout: 5 minutes
- Temperature Offset: 0.0°
- Humidity Offset: 0%
- Use 24-Hour Clock: Yes

### GPIO Pin Assignments

**Display (SPI)**:
- MOSI: GPIO 11
- MISO: GPIO 13
- SCK: GPIO 12
- CS: GPIO 10
- DC: GPIO 7
- RST: GPIO 6
- Backlight: GPIO 5

**Touch (SPI)**:
- CS: GPIO 21
- IRQ: GPIO 3

**I2C (Sensors)**:
- SDA: GPIO 8
- SCL: GPIO 9

**OneWire (DS18B20)**:
- Data: GPIO 4

**LD2410 Motion Sensor**:
- RX: GPIO 15
- TX: GPIO 16
- Motion: GPIO 18

**Relays**:
- Heat Relay 1: GPIO 1
- Heat Relay 2: GPIO 2
- Cool Relay 1: GPIO 47
- Cool Relay 2: GPIO 48
- Fan Relay: GPIO 45

**User Interface**:
- Buzzer: GPIO 46
- Boot Button: GPIO 0 (built-in)

**Light Sensor**:
- LDR (analog): GPIO 14

### Specifications

**Processor**: ESP32-S3-WROOM-1
- Dual-core Xtensa LX7 @ 240MHz
- 512KB SRAM
- 384KB ROM
- Flash: 4MB/8MB/16MB/32MB variants

**Display**: ILI9341 TFT LCD
- Resolution: 320x240 pixels
- Colors: 65K (16-bit)
- Touch: XPT2046 resistive
- Interface: SPI

**Sensors**:
- AHT20: ±0.3°C, ±2% RH
- BME280: ±1.0°C, ±3% RH, ±1 hPa (optional)
- DS18B20: ±0.5°C (optional)
- LD2410: 24GHz mmWave (optional)

**Connectivity**:
- WiFi: 802.11 b/g/n (2.4GHz)
- MQTT: Version 3.1.1
- Web: HTTP/HTTPS

**Power**:
- Input: 5V DC
- Current: 500mA typical, 1A max
- Idle: ~200mA
- Active: ~400mA

**Operating Range**:
- Temperature: 32°F - 122°F (0°C - 50°C)
- Humidity: 20% - 80% RH
- Control Range: 50°F - 90°F (10°C - 32°C)

**Dimensions** (with case):
- 149mm × 105.5mm × 47mm (W × H × D)
- Weight: ~150g

---

## Quick Reference

### Common Touch Screen Actions

| Action | Result |
|---|---|
| Tap Mode Button | Cycle: Off → Heat → Cool → Auto |
| Tap Fan Button | Cycle: Auto → On → Cycle |
| Tap Setpoint | Adjust temperature |
| Tap Setpoint (Shower Mode enabled) | Toggle shower mode on/off |
| Long-press Boot Button (10s) | Factory reset |

### Web Interface Quick Links

| URL | Purpose |
|-----|---|
| `http://[IP]` | Main status page |
| `http://[IP]/settings` | Settings page (redirects to main) |
| `http://[IP]/schedule` | Schedule page (redirects to main) |
| `http://[IP]/weather` | Weather page (redirects to main) |
| `http://[IP]/system` | System page (redirects to main) |

### MQTT Topic Quick Reference

| Topic | Direction | Purpose |
|---|---|---|
| `hostname/current_temperature` | → HA | Current temp |
| `hostname/target_temperature` | → HA | Setpoint |
| `hostname/mode` | → HA | Thermostat mode |
| `hostname/mode/set` | HA → | Set mode |
| `hostname/fan_mode` | → HA | Fan mode |
| `hostname/fan_mode/set` | HA → | Set fan mode |
| `hostname/target_temperature/set` | HA → | Set setpoint |
| `hostname/shower_mode` | → HA | Shower status |
| `hostname/shower_mode/set` | HA → | Toggle shower |
| `hostname/shower_time_remaining` | → HA | Minutes left |

---

**End of User Manual**

For additional support, visit the GitHub repository or contact support through GitHub Issues.

Project Repository: https://github.com/jrtaylor71/ESP32-DevKitC3-Simple-Thermostat-PCB

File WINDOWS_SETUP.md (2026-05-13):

# Windows Setup

This guide covers the required installs for Windows users to build and flash the ESP32-S3 thermostat firmware.

Last validated with firmware/documentation baseline v1.5.001 (May 2026).

## Required Installs

1. **Python 3.10+ (64-bit)**
   - Needed for `esptool.py` and PlatformIO.
   - During install, check **“Add Python to PATH.”**

2. **PlatformIO (Recommended)**
   - Install **Visual Studio Code**
   - Install the **PlatformIO IDE** extension
   - PlatformIO will install `esptool.py` automatically.

3. **USB-to-UART Driver (if needed)**
   - Most ESP32-S3 DevKit boards use **CP210x** or **CH340**.
   - Install the matching driver if the COM port does not appear.

## Optional Tools

- **Git for Windows** (to clone the repository)
- **Windows Terminal** (nicer CLI, optional)

## Git Bash (Optional)

If you install **Git for Windows**, you also get **Git Bash**. You can use it to run the Linux-style `.sh` flash scripts on Windows if you prefer.

Example:
- `./latest_flash_N16.sh COM4`

Notes:
- The `.bat` files are the simplest option for Windows.
- Git Bash still accepts Windows-style `COMx` ports when running the scripts.

## Verifying Installation

- Confirm Python:
  - `python --version`
- Confirm COM port shows in Device Manager:
  - **Ports (COM & LPT)** → note the COM number (e.g., COM4)

## Flashing on Windows

Use the provided batch files from the `firmware` folder:

- `latest_flash_N8.bat [COMx]`
- `latest_flash_N16.bat [COMx]`
- `latest_flash_N32.bat [COMx]`

Example:
- `latest_flash_N16.bat COM4`

If the board doesn’t respond, hold **BOOT** while connecting USB, then retry.

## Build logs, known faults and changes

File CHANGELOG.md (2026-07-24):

# Changelog

All notable firmware changes are documented in this file.

## Versioning Policy
- Version format is `major.minor.patch3` using `x.x.xxx`.
- All version changes require explicit user approval before updating any version number.
- For bug fixes, cleanup, UI tweaks, small behavior changes, and routine maintenance, increment only the last three digits.
- Example: `1.5.002` -> `1.5.003` -> `1.5.004`.
- Increase the middle digit and reset the last three digits to `000` for larger feature releases, grouped functional additions, or meaningful user-facing capability changes.
- Increase the first digit only for rare major platform, architecture, or compatibility shifts that justify a major release boundary.
- When in doubt, use the smallest possible version bump and default to incrementing the last three digits.
- Do not change `sw_version`, changelog version headers, or release labels unless the user has approved that specific version change.

## [1.5.008] - 2026-07-23
- Split fan relay requirement into separate settings for heating and cooling.
- Updated web settings and TFT settings UI to expose independent fan relay toggles for heat and cool.
- Added backward compatibility for legacy single `fanRelayNeeded` clients by mapping to both new flags.
- Fixed hydronic fan safety guard regression by keying hydronic lockout fan blocking to the heating fan requirement only.

## [1.5.007] - 2026-06-29
- Fixed MQTT `target_temperature` publishing to always republish on HVAC mode change, preventing stale heat setpoints from being shown in cool mode.
- Hardened MQTT command handling by validating incoming HVAC mode values and constraining MQTT target temperature commands to valid bounds.
- Corrected MQTT HVAC `action` reporting to detect cooling when any configured cooling relay path is active (including EU relay selections).
- Updated MQTT schedule override state publishing to send explicit `active`/`inactive` values to avoid stale override status.

## [1.5.006] - 2026-06-22
- Fixed COOL mode relay control to re-assert `activateCooling()` every control cycle while cooling demand is active.
- Prevented a stale-state condition where `coolingOn=true` could remain set while the physical cooling relay had been forced LOW.
- Improved relay-state recovery behavior so toggling modes is no longer required to re-energize cooling after an external relay-off event.

## [1.5.005] - 2026-06-22
- Fixed auto-mode HVAC control logic to use dead-zone hold behavior with a single setpoint and swing.
- Prevented on/off transitions while temperature remains inside the dead zone.
- Updated auto-mode transitions so heating/cooling turn off at the setpoint boundary rather than immediately on dead-zone re-entry.

## [1.5.004] - 2026-05-14
- Hardened OTA and manual reboot reconnect logic in web UI to prevent blank page and false failure after update or reboot.
- Fixed DS18B20 sensor regression by making OneWire GPIO41 patch persistent in build process.
- Improved process/tooling: enforced version/changelog sync, explicit approval for version changes, and robust release workflow.
- No functional changes to user-facing features beyond bugfixes and reliability improvements.

## [1.5.003] - 2026-05-14
- Web UI status refresh stabilization:
  - Replaced reload-based status updates with in-place `/status` polling updates.
  - Added no-cache headers for `/` and `/status` responses.
  - Removed conflicting duplicate tab script logic.
- OTA UX and reliability updates:
  - Fixed stale OTA filename/file-input behavior requiring fresh `.bin` selection each run.
  - Added clearer file selection state and disabled upload button until valid selection.
  - Redirect to `/?tab=status` after OTA completion and confirmed `/version` response.
  - Removed legacy standalone OTA page generator in favor of embedded OTA path only.
- Route cleanup:
  - Redirected `/settings` route to embedded settings tab at `/?tab=settings`.
- Tooling:
  - Updated VS Code build tasks to use `./build.sh all` and `./build.sh clean all`.

## [1.5.002] - 2026-05-13
- Fixed display behavior in OFF mode.
- Added non-blocking delay when switching modes.

## [1.5.001] - 2026-05-13
- Added US/EU thermostat region mode.
- Added EU humidity logic and EU relay selection behavior.
- Added display fixes and documentation updates.

## [1.5.000] - 2026-05-05
- Release 1.5.000.

## [1.4.016] - 2026-04-30
- Added SHT45 sensor support.
- Updated display behavior.
- Added backup heat code.

## [1.4.015] - 2026-04-15
- Release 1.4.015.

## [1.4.014] - 2026-03-08
- Display/layout cleanup.
- Hydronic lockout fan stability improvements.

## [1.4.013] - 2026-03-08
- Added DS18B20 sensors to Home Assistant MQTT integration.

## [1.4.012] - 2026-03-08
- Fixed DS18B20 sensors on GPIO41 (ESP32-S3).

## [1.4.009] - 2026-02-22
- Added touch calibration system.
- Enhanced fan control.
- Added dual hydronic sensor support.

## [1.4.003] - 2026-02-22
- Fixed brightness persistence in NVM (follow-up fix).
- Enabled display sleep.

## [1.4.002] - 2026-02-22
- Initial fix attempt for brightness not saving to NVM.

## [1.4.001] - 2026-01-24
- Added bidirectional MQTT schedule synchronization.

## [1.4.0] - 2026-01-04
- Major build system improvements.
- Firmware organization improvements.

## [1.3.9] - 2026-01-01
- Added comprehensive debug logging to web console.
- Added fan cycle debugging.

## [1.3.8] - 2025-12-22
- Release 1.3.8.

## [1.3.7] - 2025-12-19
- Fixed fan relay oscillation bug when manual ON mode conflicted with HVAC fan control.
- Updated schematic and PCB for missing trace.

## [1.3.6] - 2025-12 (documented module update)
- Weather module updates documented in `WEATHER_UPDATES_v1.3.5.md`:
  - Fixed negative high/low weather temperature display logic.
  - Added weather force-update capability.
  - Added weather HTTP timeout handling.
  - Updated weather default update interval.
  - Added Wi-Fi IP logging improvements.

## [1.3.5] - 2025-12-06
- Initial commit.

## Notes
- Historical versions above are derived from version-bump commits in `src/Main-Thermostat.cpp`.
- Some intermediate versions may not be present if they were not tagged by a version-string change commit.

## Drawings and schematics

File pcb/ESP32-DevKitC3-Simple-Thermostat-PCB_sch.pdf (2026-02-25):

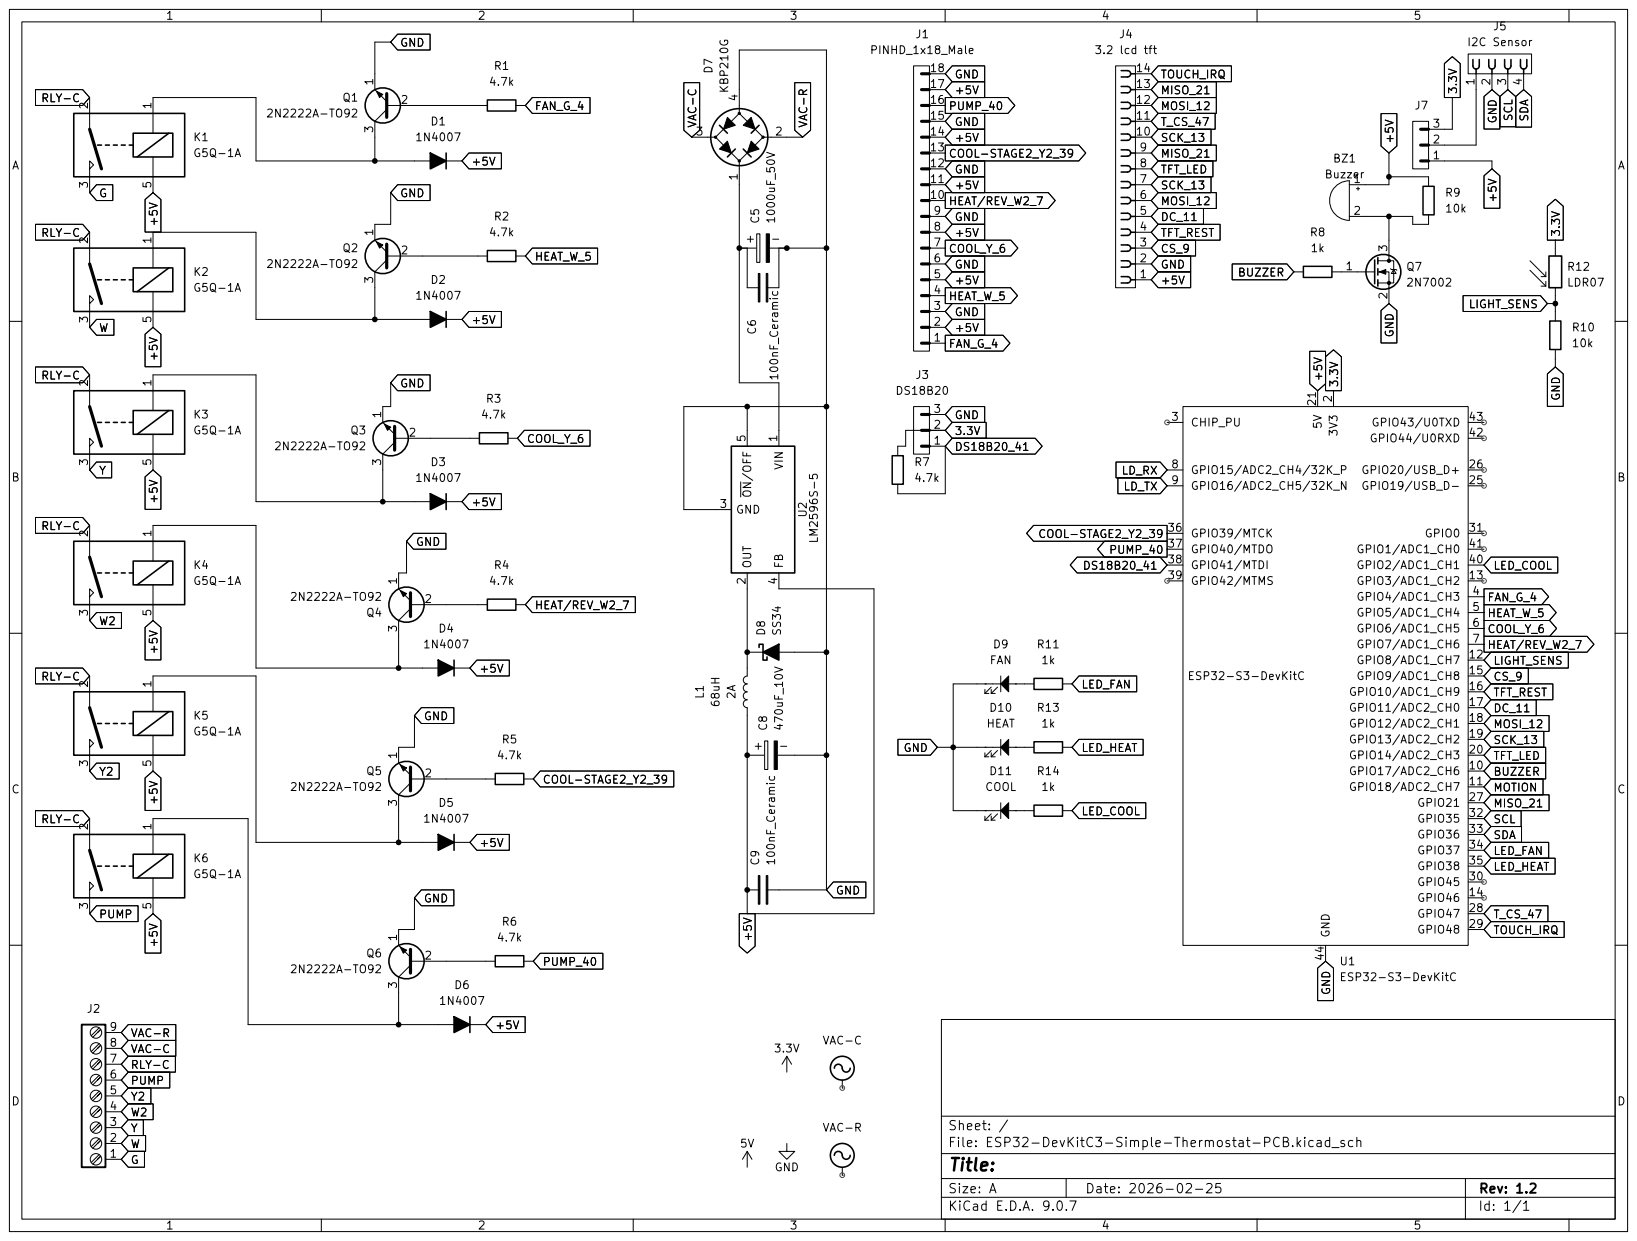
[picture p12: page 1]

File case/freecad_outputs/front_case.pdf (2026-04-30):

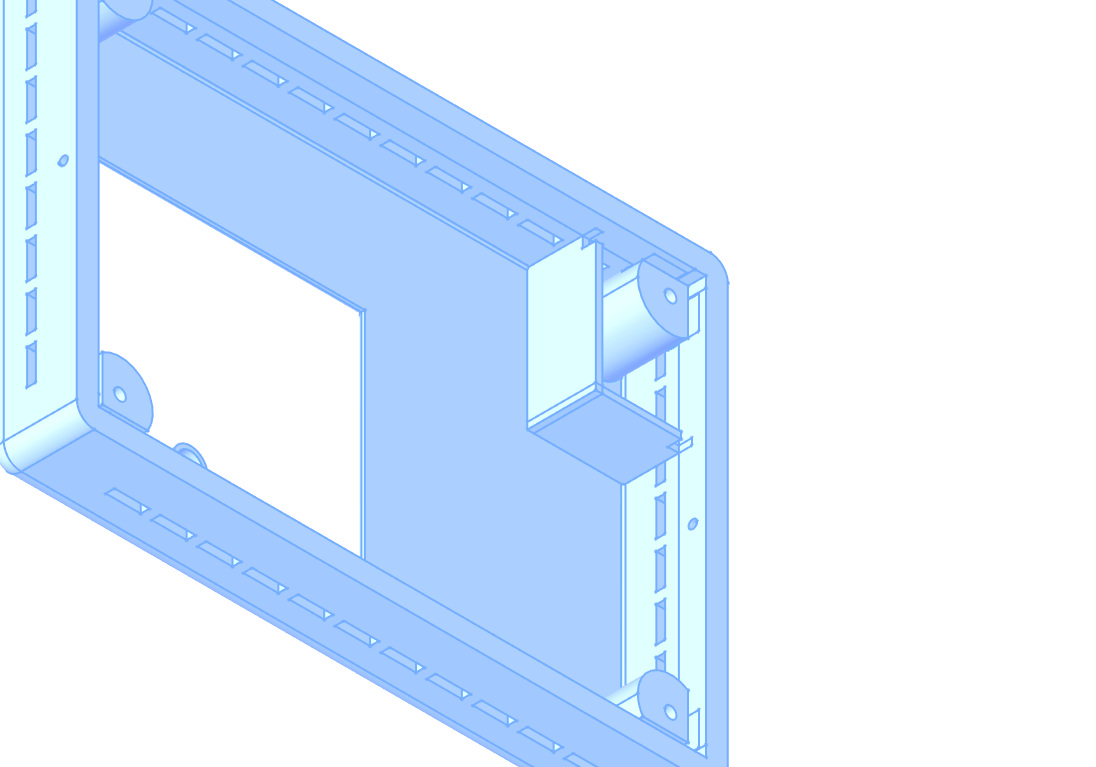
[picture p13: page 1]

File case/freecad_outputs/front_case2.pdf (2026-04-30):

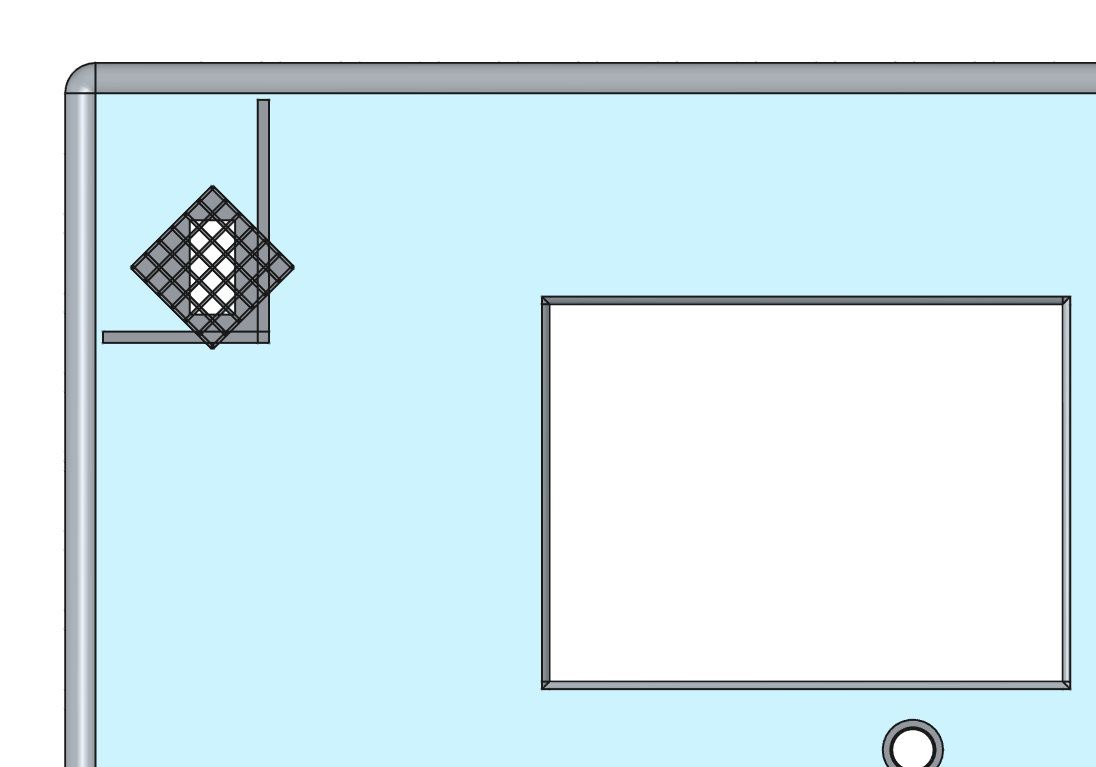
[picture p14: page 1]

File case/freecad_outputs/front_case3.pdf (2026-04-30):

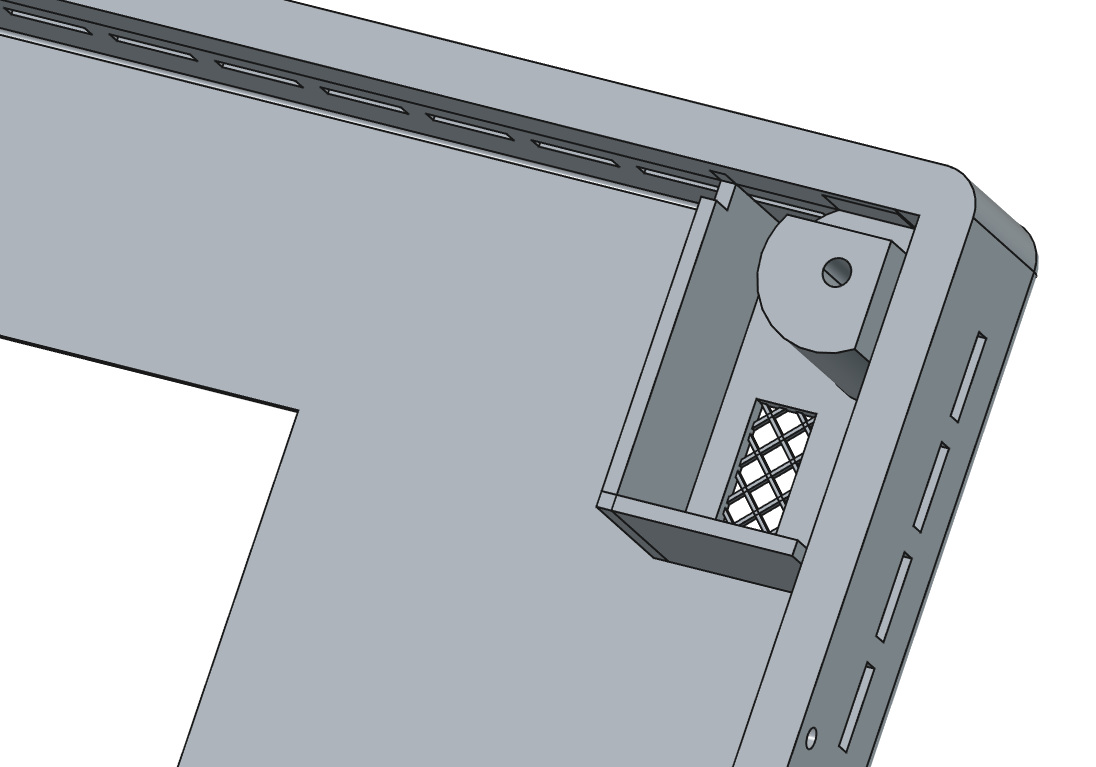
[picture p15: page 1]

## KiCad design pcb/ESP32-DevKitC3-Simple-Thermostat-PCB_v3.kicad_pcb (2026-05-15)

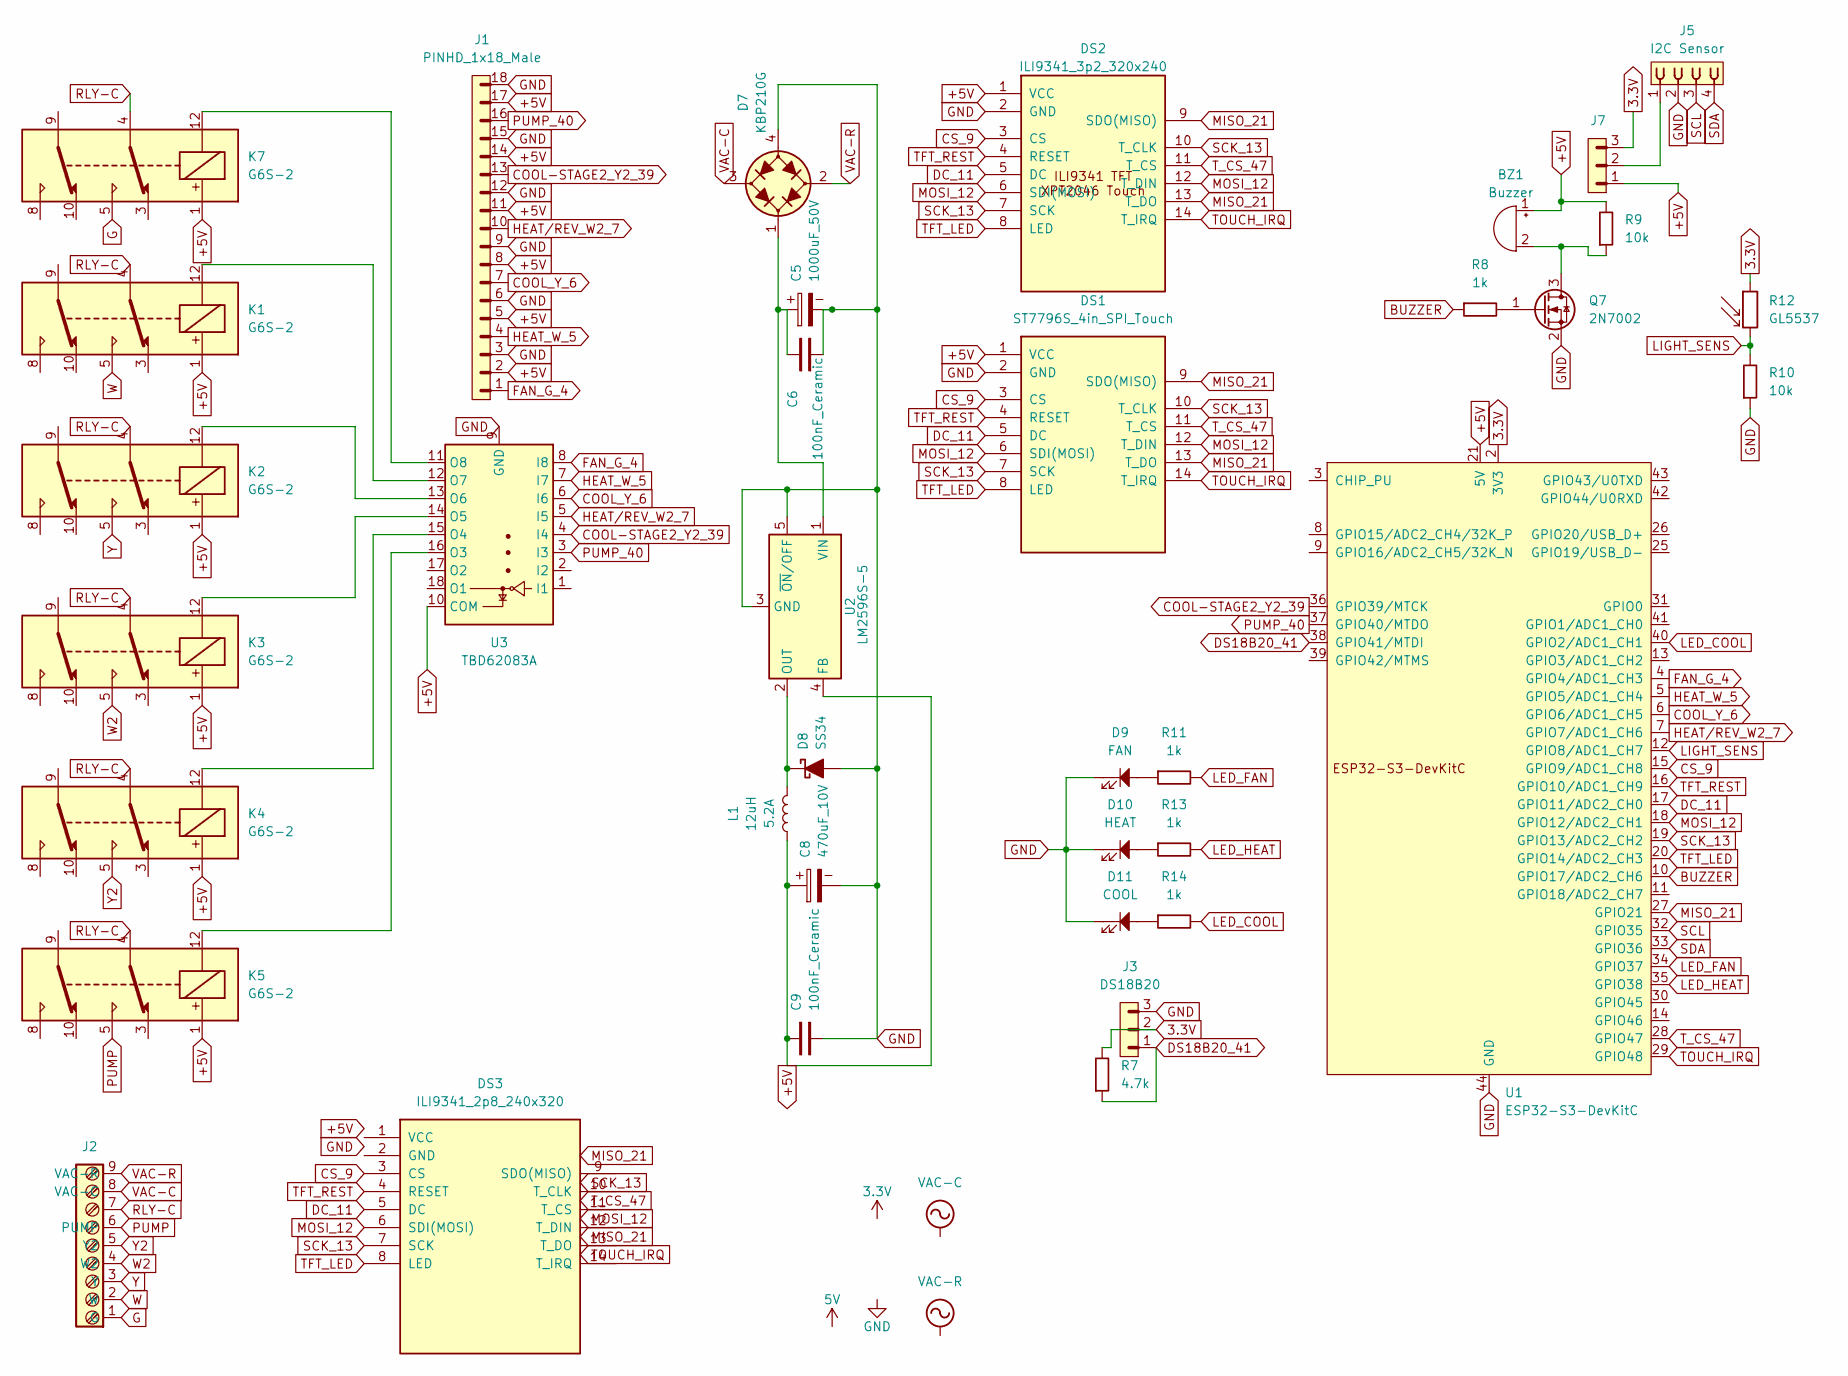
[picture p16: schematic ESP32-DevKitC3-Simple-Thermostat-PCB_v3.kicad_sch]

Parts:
BZ1: Buzzer; Buzzer_TDK_PS1240P02BT_D12.2mm_H6.5mm; LCSC C76871
C5: 1000uF_50V; CP_Radial_D16.0mm_P7.50mm; LCSC C445418
C6, C9: 100nF_Ceramic; C_Disc_D5.0mm_W2.5mm_P2.50mm; LCSC C1517817
C8: 470uF_10V; CP_Radial_D8.0mm_P3.50mm; LCSC C3274796
D7: KBP210G; Diode_Bridge_KBP; LCSC C244333
D8: SS34; D_SMC; LCSC C908239
D9: FAN; LED_D3.0mm; LCSC C17340814
D10: HEAT; LED_D3.0mm; LCSC C5990731
D11: COOL; LED_D3.0mm; LCSC C17304835
DS1: ST7796S_4in_SPI_Touch; ST7796S_4in_SPI_Touch_Module_14P
DS2: ILI9341_3p2_320x240
DS3: ILI9341_2p8_240x320
J1: PINHD_1x18_Male; PinHeader_1x18_P2.54mm_Vertical; LCSC C27985197
J2: Screw_Terminal_9_P3.50mm; TerminalBlock_Phoenix_PT-1,5-9-3.5-H_1x09_P3.50mm_Horizontal; LCSC C6373199
J3: DS18B20; PinHeader_1x03_P2.54mm_Vertical; LCSC C2932698
J5: I2C Sensor; PinSocket_1x04_P2.54mm_Vertical
J7: PINHD_1x3_Male; PinHeader_1x03_P2.54mm_Vertical; LCSC C2932698
K1, K2, K3, K4, K5, K7: G6S-2; Relay_DPDT_Omron_G6S-2
L1: 12uH_5.2A_1260; L_Bourns_SRR1260; Part Number SRR1260-120M; LCSC C2041353
Q7: 2N7002; SOT-23; LCSC C8545
R7: 4.7k; R_Axial_DIN0207_L6.3mm_D2.5mm_P10.16mm_Horizontal; LCSC C119339
R8, R11, R13, R14: 1k; R_Axial_DIN0207_L6.3mm_D2.5mm_P10.16mm_Horizontal; LCSC C119324
R9, R10: 10k; R_Axial_DIN0207_L6.3mm_D2.5mm_P10.16mm_Horizontal; LCSC C119347
R12: GL5537; R_LDR_5.1x4.3mm_P3.4mm_Vertical; LCSC C125628
U1: ESP32-S3-DevKitC
U2: LM2596S-5; TO-263-5_TabPin3; LCSC C347445
U3: TBD62083A; DW18

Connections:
3.3V: J3.2, J7.3, R7.2, R12.1, U1.1 (3V3), U1.2 (3V3)
+5V: BZ1.1 (+), C8.1, C9.1, DS1.1 (VCC), DS2.1 (VCC), J1.2, J1.5, J1.8, J1.11, J1.14, J1.17, J7.1, K1.1, K2.1, K3.1, K4.1, K5.1, K7.1, L1.1, R9.2, U1.21 (5V), U2.4 (FB), U3.10 (COM)
BUZZER: R8.1, U1.10 (GPIO17/ADC2_CH6)
COOL-STAGE2_Y2_39: J1.13, U1.36 (GPIO39/MTCK), U3.4 (I4)
COOL_Y_6: J1.7, U1.6 (GPIO6/ADC1_CH5), U3.6 (I6)
CS_9: DS1.3 (CS), DS2.3 (CS), DS3.3 (CS), U1.15 (GPIO9/ADC1_CH8)
DC_11: DS1.5 (DC), DS2.5 (DC), DS3.5 (DC), U1.17 (GPIO11/ADC2_CH0)
DS18B20_41: J3.1, R7.1, U1.38 (GPIO41/MTDI)
FAN_G_4: J1.1, U1.4 (GPIO4/ADC1_CH3), U3.8 (I8)
G: J2.1 (G), K7.5
GND: C5.2, C6.1, C8.2, C9.2, D7.4 (-), D8.2 (A), D9.1, D10.1, D11.1, DS1.2 (GND), DS2.2 (GND), J1.3, J1.6, J1.9, J1.12, J1.15, J1.18, J3.3, J5.2, Q7.2 (S), R10.1, U1.22 (GND), U1.23 (GND), U1.24 (GND), U1.44 (GND), U2.3 (GND), U2.5 (~ON/OFF), U3.9 (GND); also elsewhere on the board
HEAT_W_5: J1.4, U1.5 (GPIO5/ADC1_CH4), U3.7 (I7)
HEAT/REV_W2_7: J1.10, U1.7 (GPIO7/ADC1_CH6), U3.5 (I5)
LED_COOL: R14.2, U1.40 (GPIO2/ADC1_CH1)
LED_FAN: R11.2, U1.34 (GPIO37)
LED_HEAT: R13.2, U1.35 (GPIO38)
LIGHT_SENS: R10.2, R12.2, U1.12 (GPIO8/ADC1_CH7)
MISO_21: DS1.9 (SDO(MISO)), DS1.13 (T_DO), DS2.9 (SDO(MISO)), DS2.13 (T_DO), U1.27 (GPIO21)
MOSI_12: DS1.6 (SDI(MOSI)), DS1.12 (T_DIN), DS2.6 (SDI(MOSI)), DS2.12 (T_DIN), DS3.6 (SDI(MOSI)), U1.18 (GPIO12/ADC2_CH1)
unnamed: BZ1.2 (-), Q7.3 (D), R9.1
unnamed: C5.1, C6.2, D7.1 (+), U2.1 (VIN)
unnamed: D8.1 (K), L1.2, U2.2 (OUT)
unnamed: D9.2, R11.1
unnamed: D10.2, R13.1
unnamed: D11.2, R14.1
unnamed: J5.1, J7.2
unnamed: Q7.1 (G), R8.2
unnamed: K5.12, U3.16 (O3)
unnamed: K4.12, U3.15 (O4)
unnamed: K3.12, U3.14 (O5)
unnamed: K2.12, U3.13 (O6)
unnamed: K1.12, U3.12 (O7)
unnamed: K7.12, U3.11 (O8)
PUMP: J2.6 (PUMP), K5.5
PUMP_40: J1.16, U1.37 (GPIO40/MTDO), U3.3 (I3)
RLY-C: J2.7, K1.4, K2.4, K3.4, K4.4, K5.4, K7.4
SCK_13: DS1.7 (SCK), DS1.10 (T_CLK), DS2.7 (SCK), DS2.10 (T_CLK), DS3.7 (SCK), U1.19 (GPIO13/ADC2_CH2)
SCL: J5.3, U1.32 (GPIO35)
SDA: J5.4, U1.33 (GPIO36)
TFT_LED: DS1.8 (LED), DS2.8 (LED), DS3.8 (LED), U1.20 (GPIO14/ADC2_CH3)
TFT_REST: DS1.4 (RESET), DS2.4 (RESET), DS3.4 (RESET), U1.16 (GPIO10/ADC1_CH9)
TOUCH_IRQ: DS1.14 (T_IRQ), DS2.14 (T_IRQ), U1.29 (GPIO48)
T_CS_47: DS1.11 (T_CS), DS2.11 (T_CS), U1.28 (GPIO47)
VAC-C: D7.3 (2), J2.8 (VAC-C)
VAC-R: D7.2 (1), J2.9 (VAC-R)
W: J2.2 (W), K1.5
W2: J2.4 (W2), K3.5
Y: J2.3 (Y), K2.5
Y2: J2.5 (Y2), K4.5

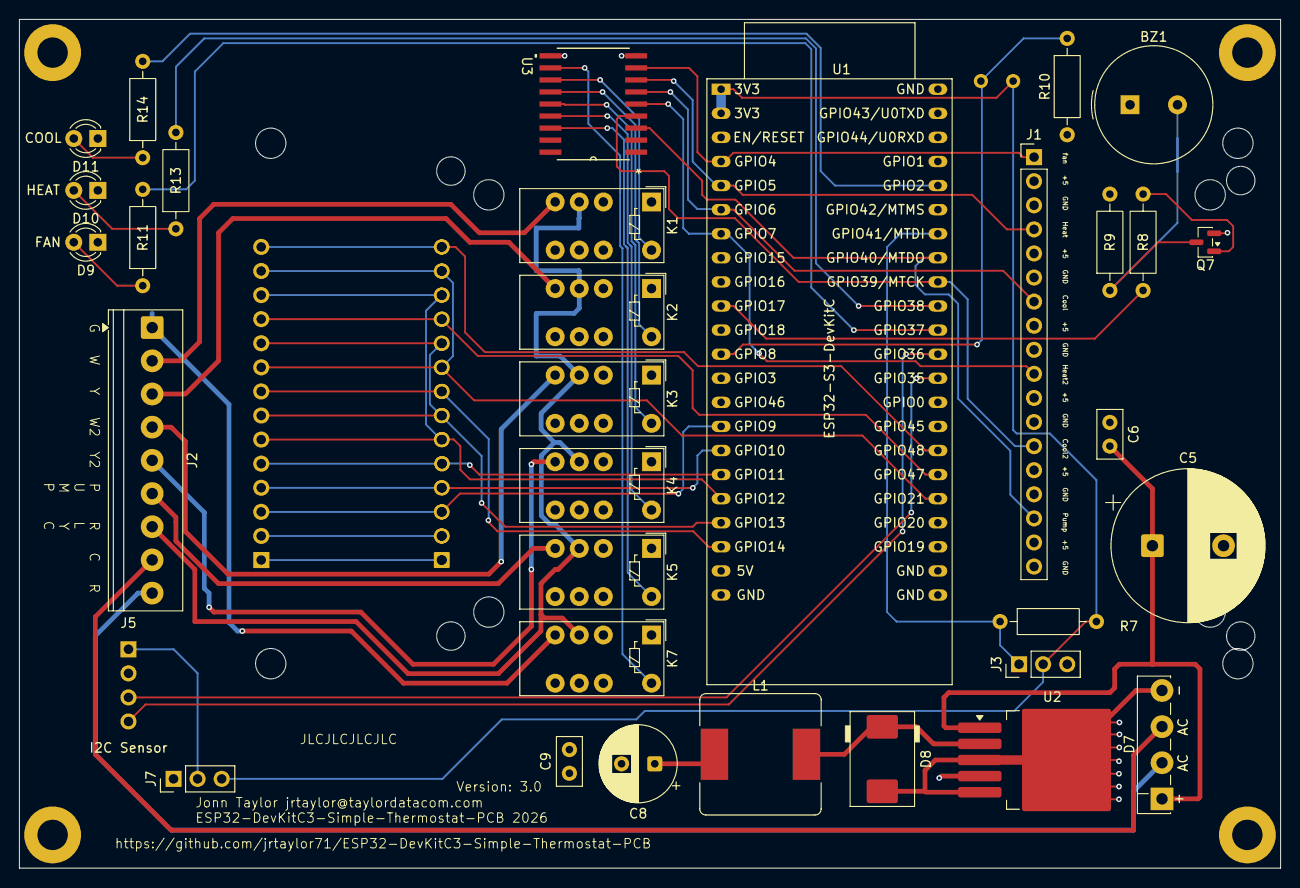
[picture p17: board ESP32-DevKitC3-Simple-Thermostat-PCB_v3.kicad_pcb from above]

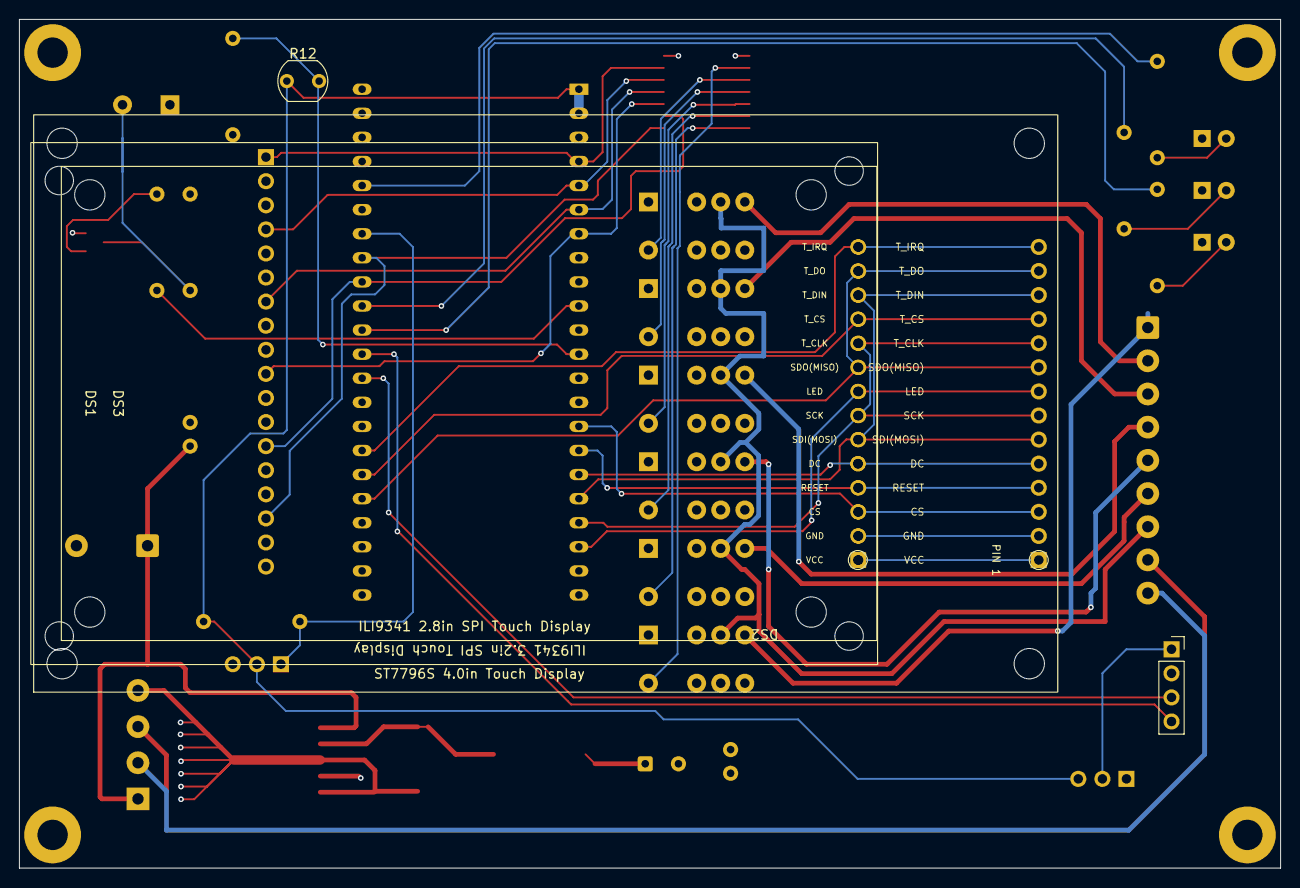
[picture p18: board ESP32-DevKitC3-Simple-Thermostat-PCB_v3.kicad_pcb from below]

Board: 4 copper layers, 133.0 x 89.5 mm, 41 parts (5 on the bottom side), 49 nets.

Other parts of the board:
H1, H2, H3, H4: MountingHole_M3_3.2mm_Pad; MountingHole_3.2mm_Pad

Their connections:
GND: H1.1, H2.1, H3.1, H4.1; also elsewhere on the board

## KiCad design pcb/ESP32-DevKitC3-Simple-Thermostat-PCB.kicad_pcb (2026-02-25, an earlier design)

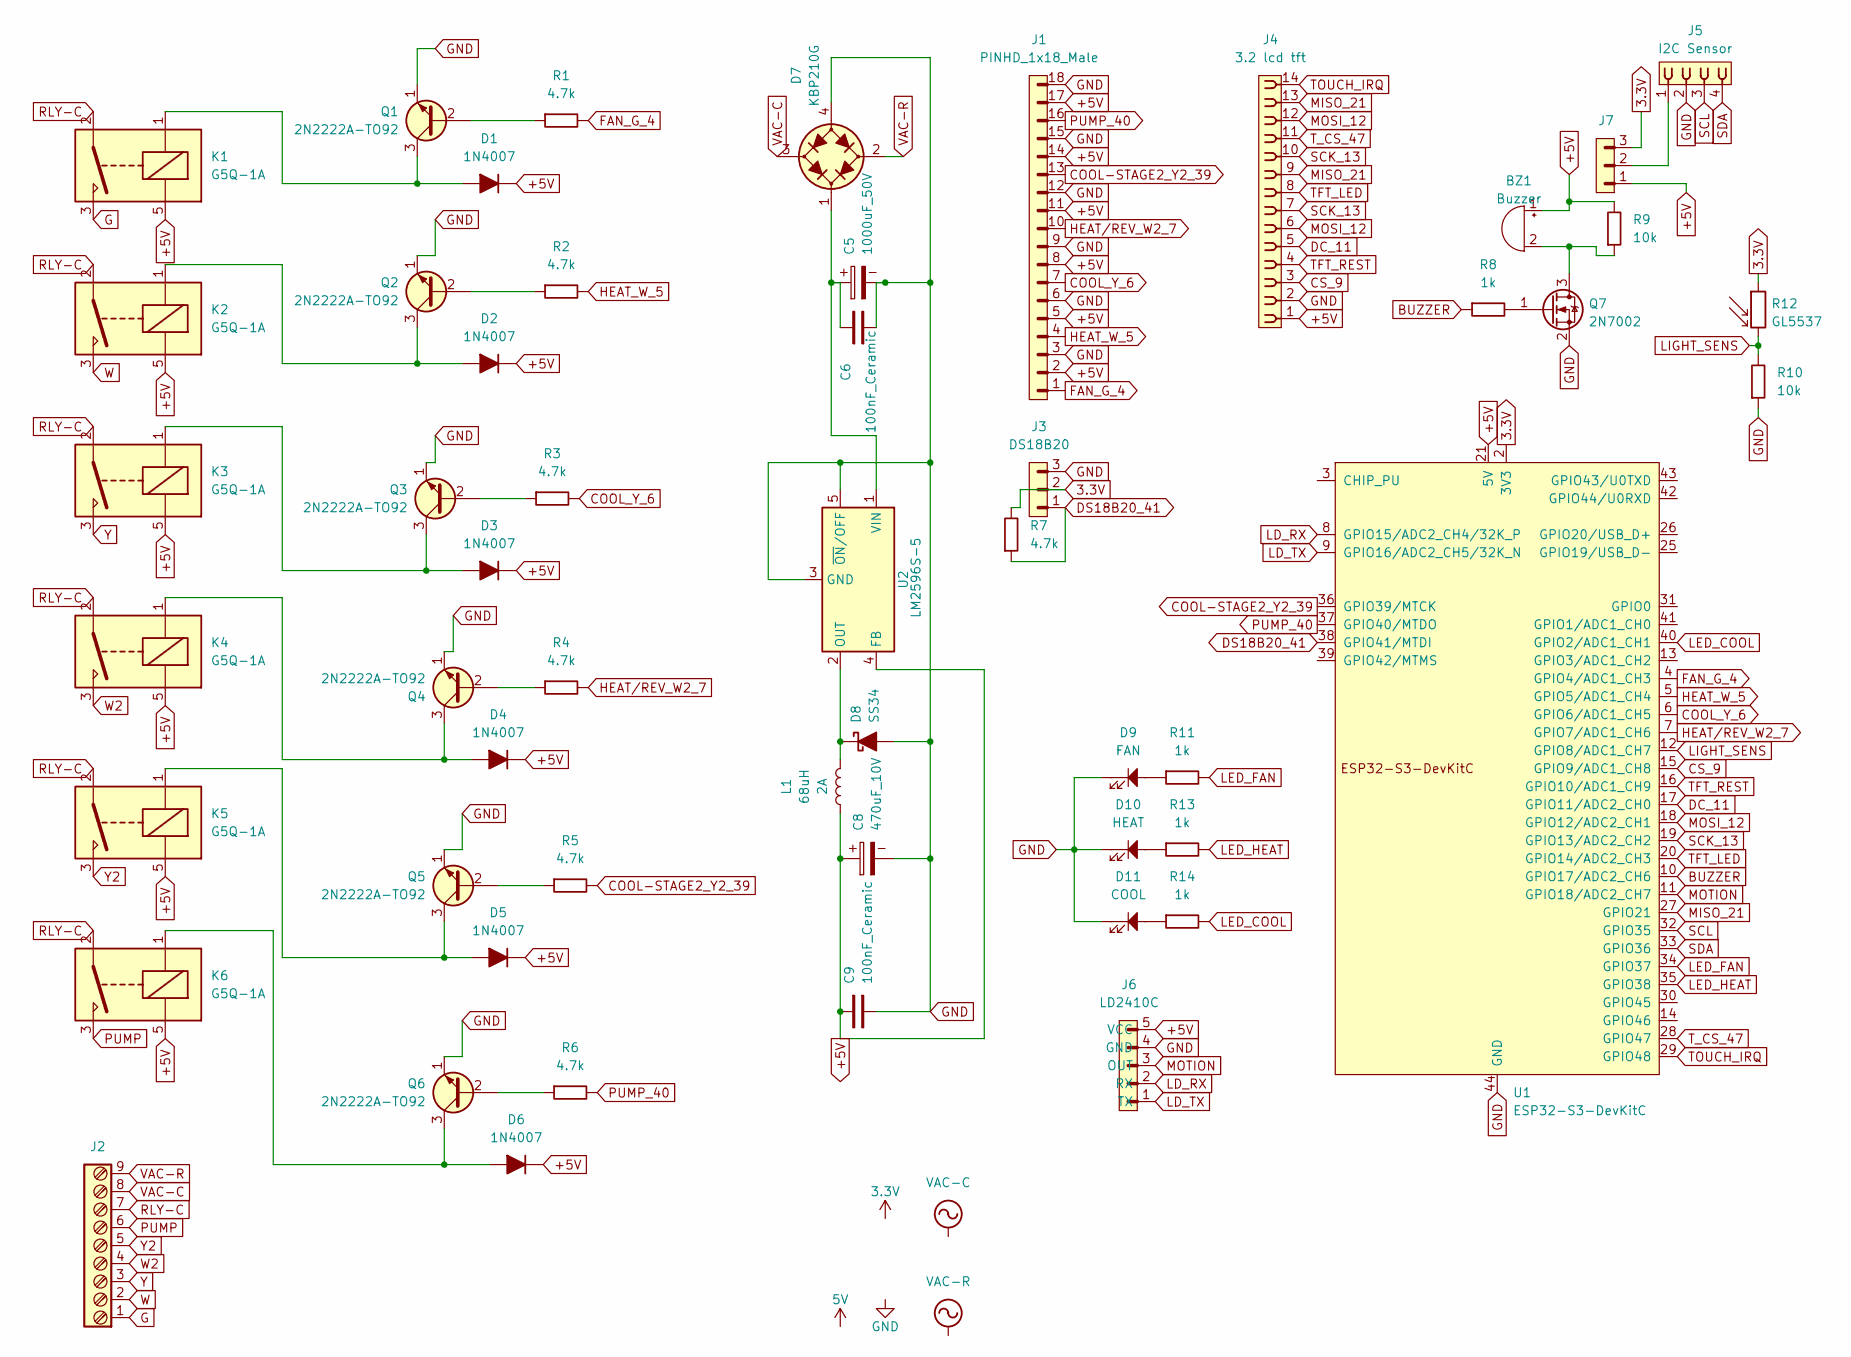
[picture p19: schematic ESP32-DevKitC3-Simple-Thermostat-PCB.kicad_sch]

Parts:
BZ1: Buzzer; Buzzer_TDK_PS1240P02BT_D12.2mm_H6.5mm
C5: 1000uF_50V; CP_Radial_D16.0mm_P7.50mm
C6, C9: 100nF_Ceramic; C_Disc_D5.0mm_W2.5mm_P2.50mm
C8: 470uF_10V; CP_Radial_D8.0mm_P3.50mm
D1, D2, D3, D4, D5, D6: 1N4007; D_DO-41_SOD81_P7.62mm_Horizontal
D7: KBP210G; Diode_Bridge_KBP
D8: SS34; D_SMC
D9: FAN; LED_D3.0mm
D10: HEAT; LED_D3.0mm
D11: COOL; LED_D3.0mm
J1: PINHD_1x18_Male; PinHeader_1x18_P2.54mm_Vertical
J2: Screw_Terminal_9_P3.50mm; TerminalBlock_Phoenix_PT-1,5-9-3.5-H_1x09_P3.50mm_Horizontal
J3: DS18B20; PinHeader_1x03_P2.54mm_Vertical
J4: 3.2 lcd tft; PinSocket_1x14_P2.54mm_Vertical
J5: I2C Sensor; PinSocket_1x04_P2.54mm_Vertical
J6: LD2410C; PinHeader_1x05_P2.54mm_Vertical
J7: PINHD_1x3_Male; PinHeader_1x03_P2.54mm_Vertical
K1, K2, K3, K4, K5, K6: G5Q-1A; Relay_SPST_Omron-G5Q-1A
L1: 12uH_5.2A_1260; L_Bourns_SRR1260; Part Number SRR1260-120M
Q1, Q2, Q3, Q4, Q5, Q6: 2N2222A-TO92; TO-92_Inline_Wide_EBC
Q7: 2N7002; SOT-23; LCSC C8545
R1, R2, R3, R4, R5, R6, R7: 4.7k; R_Axial_DIN0207_L6.3mm_D2.5mm_P10.16mm_Horizontal
R8, R11, R13, R14: 1k; R_Axial_DIN0207_L6.3mm_D2.5mm_P10.16mm_Horizontal
R9, R10: 10k; R_Axial_DIN0207_L6.3mm_D2.5mm_P10.16mm_Horizontal
R12: GL5537; R_LDR_5.1x4.3mm_P3.4mm_Vertical
U1: ESP32-S3-DevKitC
U2: LM2596S-5; TO-263-5_TabPin3

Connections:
3.3V: J3.2, J7.3, R7.2, R12.1, U1.1 (3V3), U1.2 (3V3)
+5V: BZ1.1 (-), C8.1, C9.1, D1.1 (K), D2.1 (K), D3.1 (K), D4.1 (K), D5.1 (K), D6.1 (K), J1.2, J1.5, J1.8, J1.11, J1.14, J1.17, J4.1, J6.5 (VCC), J7.1, K1.5, K2.5, K3.5, K4.5, K5.5, K6.5, L1.1, R9.2, U1.21 (5V), U2.4 (FB)
BUZZER: R8.1, U1.10 (GPIO17/ADC2_CH6)
COOL-STAGE2_Y2_39: J1.13, R5.2, U1.36 (GPIO39/MTCK)
COOL_Y_6: J1.7, R3.2, U1.6 (GPIO6/ADC1_CH5)
CS_9: J4.3, U1.15 (GPIO9/ADC1_CH8)
DC_11: J4.5, U1.17 (GPIO11/ADC2_CH0)
DS18B20_41: J3.1, R7.1, U1.38 (GPIO41/MTDI)
FAN_G_4: J1.1, R1.2, U1.4 (GPIO4/ADC1_CH3)
G: J2.1, K1.3
GND: C5.2, C6.1, C8.2, C9.2, D7.4 (-), D8.2 (A), D9.1, D10.1, D11.1, J1.3, J1.6, J1.9, J1.12, J1.15, J1.18, J3.3, J4.2, J5.2, J6.4 (GND), Q1.1 (E), Q2.1 (E), Q3.1 (E), Q4.1 (E), Q5.1 (E), Q6.1 (E), Q7.2 (S), R10.1, U1.22 (GND), U1.23 (GND), U1.24 (GND), U1.44 (GND), U2.3 (GND), U2.5 (~ON/OFF); also elsewhere on the board
HEAT_W_5: J1.4, R2.2, U1.5 (GPIO5/ADC1_CH4)
HEAT/REV_W2_7: J1.10, R4.2, U1.7 (GPIO7/ADC1_CH6)
LD_RX: J6.2 (RX), U1.8 (GPIO15/ADC2_CH4/32K_P)
LD_TX: J6.1 (TX), U1.9 (GPIO16/ADC2_CH5/32K_N)
LED_COOL: R14.2, U1.40 (GPIO2/ADC1_CH1)
LED_FAN: R11.2, U1.34 (GPIO37)
LED_HEAT: R13.2, U1.35 (GPIO38)
LIGHT_SENS: R10.2, R12.2, U1.12 (GPIO8/ADC1_CH7)
MISO_21: J4.9, J4.13, U1.27 (GPIO21)
MOSI_12: J4.6, J4.12, U1.18 (GPIO12/ADC2_CH1)
MOTION: J6.3 (OUT), U1.11 (GPIO18/ADC2_CH7)
unnamed: BZ1.2 (+), Q7.3 (D), R9.1
unnamed: D1.2 (A), K1.1, Q1.3 (C)
unnamed: D2.2 (A), K2.1, Q2.3 (C)
unnamed: D3.2 (A), K3.1, Q3.3 (C)
unnamed: D4.2 (A), K4.1, Q4.3 (C)
unnamed: D5.2 (A), K5.1, Q5.3 (C)
unnamed: D6.2 (A), K6.1, Q6.3 (C)
unnamed: C5.1, C6.2, D7.1 (+), U2.1 (VIN)
unnamed: D8.1 (K), L1.2, U2.2 (OUT)
unnamed: D9.2, R11.1
unnamed: D10.2, R13.1
unnamed: D11.2, R14.1
unnamed: J5.1, J7.2
unnamed: Q1.2 (B), R1.1
unnamed: Q2.2 (B), R2.1
unnamed: Q3.2 (B), R3.1
unnamed: Q4.2 (B), R4.1
unnamed: Q5.2 (B), R5.1
unnamed: Q6.2 (B), R6.1
unnamed: Q7.1 (G), R8.2
PUMP: J2.6, K6.3
PUMP_40: J1.16, R6.2, U1.37 (GPIO40/MTDO)
RLY-C: J2.7, K1.2, K2.2, K3.2, K4.2, K5.2, K6.2
SCK_13: J4.7, J4.10, U1.19 (GPIO13/ADC2_CH2)
SCL: J5.3, U1.32 (GPIO35)
SDA: J5.4, U1.33 (GPIO36)
TFT_LED: J4.8, U1.20 (GPIO14/ADC2_CH3)
TFT_REST: J4.4, U1.16 (GPIO10/ADC1_CH9)
TOUCH_IRQ: J4.14, U1.29 (GPIO48)
T_CS_47: J4.11, U1.28 (GPIO47)
VAC-C: D7.3 (2), J2.8
VAC-R: D7.2 (1), J2.9
W: J2.2, K2.3
W2: J2.4, K4.3
Y: J2.3, K3.3
Y2: J2.5, K5.3

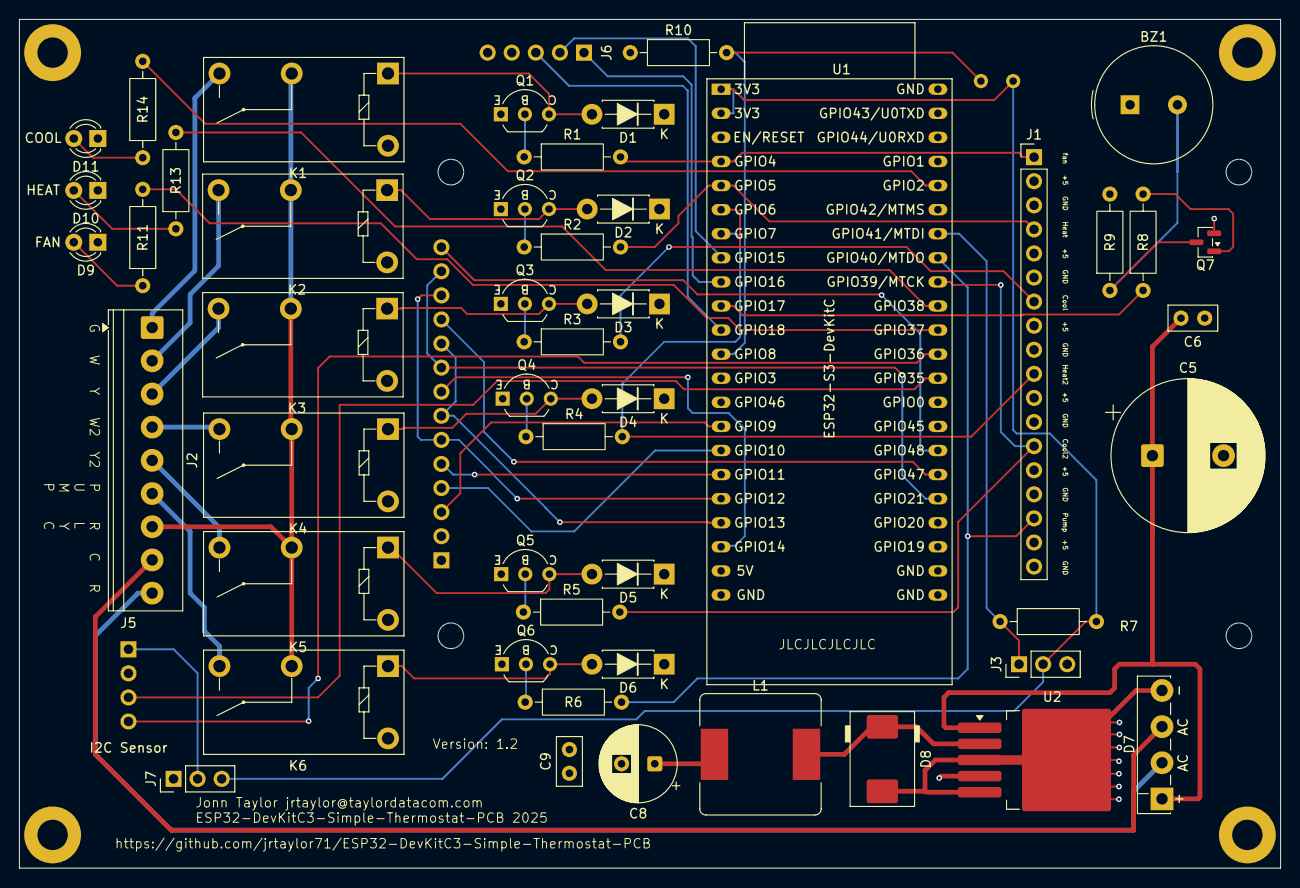
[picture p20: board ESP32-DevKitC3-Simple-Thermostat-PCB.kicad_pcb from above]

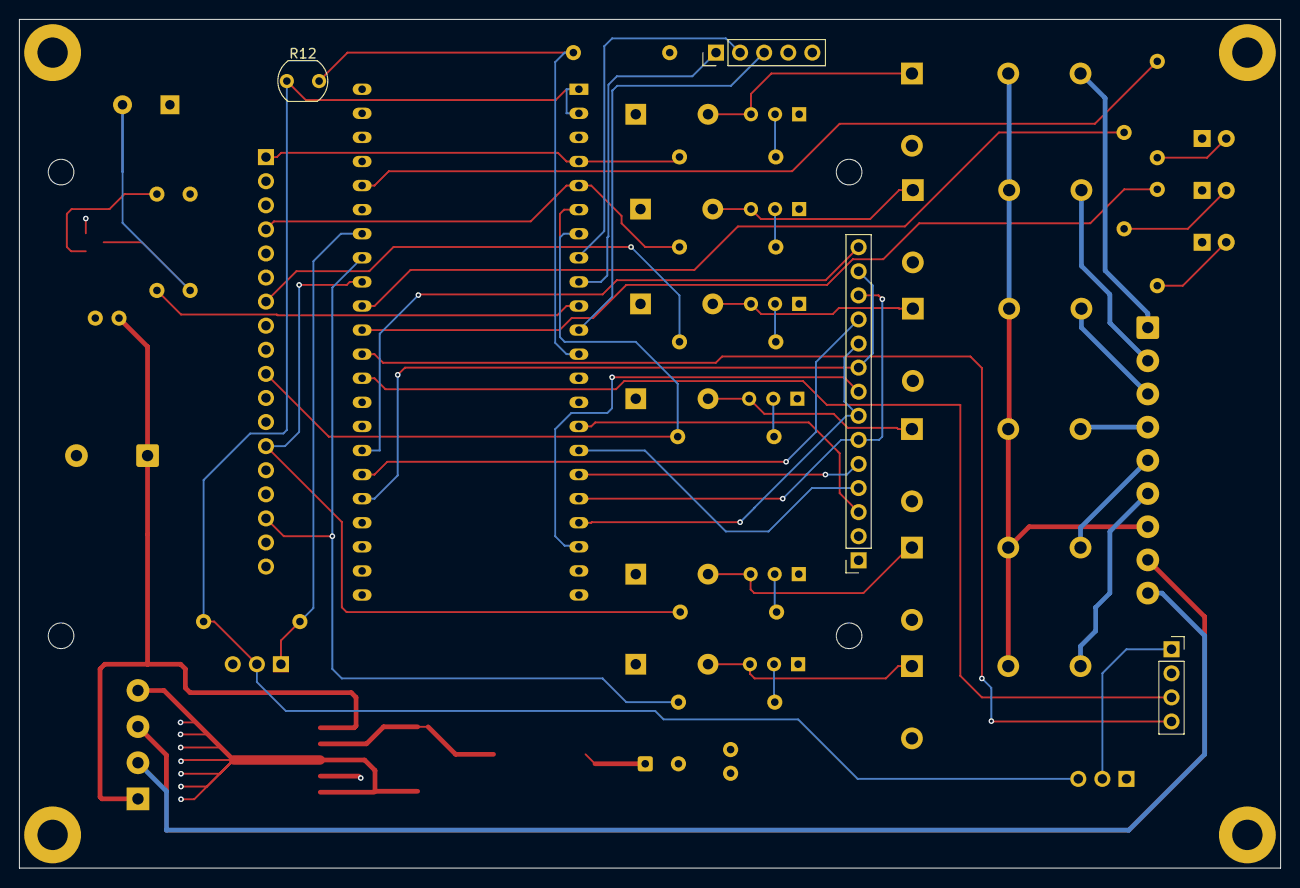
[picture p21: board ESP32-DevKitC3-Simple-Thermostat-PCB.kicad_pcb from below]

Board: 4 copper layers, 133.0 x 89.5 mm, 61 parts (4 on the bottom side), 58 nets.

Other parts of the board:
H1, H2, H3, H4: MountingHole_M3_3.2mm_Pad; MountingHole_3.2mm_Pad
H5, H6, H7, H8: MountingHole; MountingHole_2.7mm_M2.5

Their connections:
GND: H1.1, H2.1, H3.1, H4.1; also elsewhere on the board

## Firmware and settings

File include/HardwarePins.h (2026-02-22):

/**
 * HardwarePins.h
 * 
 * Hardware pin definitions for ESP32-S3 Simple Thermostat
 * Board: ESP32-S3-DevKitC-1 V1.1 (16MB Flash, No PSRAM)
 * 
 * Centralized hardware abstraction layer for all GPIO assignments.
 * Modify this file when changing PCB layout or hardware configuration.
 */

#ifndef HARDWARE_PINS_H
#define HARDWARE_PINS_H

// =============================================================================
// SERIAL PORT DEFINITIONS
// =============================================================================

// USB Serial Ports (ESP32-S3-DevKitC-1 V1.1)
// - /dev/ttyACM0: Native USB CDC (built-in USB peripheral, no GPIO pins)
// - /dev/ttyACM1: USB-to-UART bridge chip on UART0 (GPIO43 TX, GPIO44 RX)

// UART0 - USB-to-UART Bridge (appears as /dev/ttyACM1)
#define UART0_TX_PIN 43  // Connected to USB-UART bridge chip
#define UART0_RX_PIN 44  // Connected to USB-UART bridge chip

// UART1 - LD2410 Motion Sensor (configurable)
#define LD2410_TX_PIN 16  // ESP32 TX -> LD2410 RX (data to sensor) - LD_TX=GPIO16
#define LD2410_RX_PIN 15  // ESP32 RX -> LD2410 TX (data from sensor) - LD_RX=GPIO15

// UART2 - Available but pins conflict with other peripherals
// NOTE: UART2 default pins (GPIO17 TX, GPIO18 RX) are used for buzzer and motion detect
// If UART2 is needed, reassign buzzer and motion detect pins

// =============================================================================
// TFT DISPLAY - ILI9341 (SPI Interface)
// =============================================================================

#define TFT_CS_PIN        9  // Chip select (CS_9)
#define TFT_DC_PIN       11  // Data/Command (DC_11)
#define TFT_RST_PIN      10  // Reset (TFT_REST -> GPIO10)
#define TFT_MOSI_PIN     12  // SPI MOSI (MOSI_12)
#define TFT_SCLK_PIN     13  // SPI Clock (SCK_13)
#define TFT_MISO_PIN     21  // SPI MISO (MISO_21)
#define TFT_BACKLIGHT_PIN 14 // PWM backlight control (TFT_LED -> GPIO14)

// =============================================================================
// TOUCH CONTROLLER - XPT2046 (SPI Interface, shared with TFT)
// =============================================================================

#define TOUCH_CS_PIN     47  // Touch chip select (T_CS_47)
#define TOUCH_IRQ_PIN    48  // Touch interrupt (GPIO48)

// =============================================================================
// I2C BUS - Temperature/Humidity Sensors (AHT20, DHT11, BME280)
// =============================================================================

#define I2C_SDA_PIN      36  // I2C Data (SDA)
#define I2C_SCL_PIN      35  // I2C Clock (SCL)

// Temperature/Humidity Sensor Configuration
// - AHT20: I2C address 0x38 (uses both SDA and SCL)
// - BME280: I2C address 0x76 or 0x77 (uses both SDA and SCL)
// - DHT11: Uses GPIO35 (SCL pin) as 1-wire data line, GPIO36 unused
//
// Note: Only ONE sensor should be populated on the PCB at a time
// Sensor type is auto-detected at startup:
//   1. Try I2C sensors first (AHT20, then BME280)
//   2. If no I2C response, disable I2C and try DHT11 on GPIO35

// =============================================================================
// ONEWIRE BUS - DS18B20 Hydronic Temperature Sensor
// =============================================================================

#define ONEWIRE_PIN      41  // DS18B20 data line (GPIO41)

// =============================================================================
// RELAY OUTPUTS - HVAC Control (Active HIGH)
// =============================================================================

#define HEAT_RELAY_1_PIN  5   // Heat Stage 1 (HEAT_W_5)
#define HEAT_RELAY_2_PIN  7   // Heat Stage 2 (HEAT_W_7)
#define COOL_RELAY_1_PIN  6   // Cool Stage 1 (COOL_Y_6)
#define COOL_RELAY_2_PIN  39  // Cool Stage 2 (COOL-STAGE2_Y2_39)
#define FAN_RELAY_PIN     4   // Fan Control (FAN_G_4)
#define PUMP_RELAY_PIN    40  // Pump Control (PUMP_40)

// =============================================================================
// STATUS LED OUTPUTS - PWM Capable for Dimming
// =============================================================================

#define LED_FAN_PIN      37  // Fan status LED (green) - GPIO37
#define LED_HEAT_PIN     38  // Heat status LED (red) - GPIO38
#define LED_COOL_PIN     2   // Cool status LED (blue)

// =============================================================================
// BUZZER OUTPUT - 5V Buzzer through 2N7002 MOSFET
// =============================================================================

#define BUZZER_PIN       17  // Buzzer control (PWM for tones)

// =============================================================================
// MOTION SENSOR - LD2410 24GHz mmWave Radar
// =============================================================================

#define LD2410_MOTION_PIN 18  // Motion detection output (digital)
// LD2410 serial interface uses UART1 (GPIO15 RX, GPIO16 TX) - see UART section above
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

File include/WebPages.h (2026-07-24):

#ifndef WEBPAGES_H
#define WEBPAGES_H

#include "WebInterface.h"
#include "HardwarePins.h"
#include "Weather.h"

// Schedule system structures
struct SchedulePeriod {
    int hour;        // 0-23
    int minute;      // 0-59
    float heatTemp;  // Target heating temperature
    float coolTemp;  // Target cooling temperature
    float autoTemp;  // Target auto mode temperature
    bool active;     // Whether this period is enabled
};

struct DaySchedule {
    SchedulePeriod day;    // Day period (default 6:00 AM)
    SchedulePeriod night;  // Night period (default 10:00 PM)
    bool enabled;          // Whether scheduling is enabled for this day
};

// Format uptime in human-readable format
String formatUptime(unsigned long milliseconds) {
    unsigned long seconds = milliseconds / 1000;
    unsigned long minutes = seconds / 60;
    unsigned long hours = minutes / 60;
    unsigned long days = hours / 24;
    
    seconds %= 60;
    minutes %= 60;
    hours %= 24;
    
    String uptime = "";
    if (days > 0) {
        uptime += String(days) + "d ";
    }
    if (hours > 0 || days > 0) {
        uptime += String(hours) + "h ";
    }
    if (minutes > 0 || hours > 0 || days > 0) {
        uptime += String(minutes) + "m ";
    }
    uptime += String(seconds) + "s";
    
    return uptime;
}

// Generate modern status page HTML
String generateStatusPage(float currentTemp, float currentHumidity, float hydronicTemp, float hydronicReturnTemp,
                         String thermostatMode, String fanMode, String version_info, 
                         String hostname, bool useFahrenheit, bool hydronicHeatingEnabled,
                         int heatRelay1Pin, int heatRelay2Pin, int coolRelay1Pin, 
                         int coolRelay2Pin, int fanRelayPin,
                         // Settings variables for embedded settings tab
                         float setTempHeat, float setTempCool, float setTempAuto,
                         float tempSwing, float autoTempSwing,
                         bool fanRelayNeededHeat, bool fanRelayNeededCool, unsigned long stage1MinRuntime, 
                         float stage2TempDelta, int fanMinutesPerHour,
                         bool showerModeEnabled, int showerModeDuration,
                         bool stage2HeatingEnabled, bool stage2CoolingEnabled,
                         bool reversingValveEnabled,
                         bool backupHeatEnabled, int backupHeatRelaySelection, int backupHeatDelayMinutes,
                         float backupHeatMinTempRise, float backupHeatMaxTempDrop,
                         String thermostatRegion,
                         bool euHumidityControlEnabled, int euHumidityRelaySelection,
                         float euHumiditySetpoint, float euHumidityDeadband,
                         bool euHumidityDemandActive,
                         float hydronicTempLow, float hydronicTempHigh,
                         String wifiSSID, String wifiPassword, String timeZone,
                         bool use24HourClock, bool mqttEnabled, String mqttServer,
                         int mqttPort, String mqttUsername, String mqttPassword,
                         float tempOffset, float humidityOffset, int currentBrightness, bool ldrDimmingEnabled,
                         bool displaySleepEnabled, unsigned long displaySleepTimeout,
                         // Schedule variables for embedded schedule tab
                         DaySchedule weekSchedule[7], bool scheduleEnabled, String activePeriod,
                         bool scheduleOverride,
                         // Weather variables
                         int weatherSource, String owmApiKey, String owmCity, String owmState, String owmCountry,
                         String haUrl, String haToken, String haEntityId, int weatherUpdateInterval,
                         WeatherData weatherData) {
    
    String html = "<!DOCTYPE html><html lang='en'><head>";
    html += "<meta charset='UTF-8'>";
    html += "<meta name='viewport' content='width=device-width, initial-scale=1.0'>";
    html += "<title>"; html += String(PROJECT_NAME_SHORT); html += " - Status</title>";
    html += CSS_STYLES;
    html += "</head><body>";
    
    html += "<div class='container'>";
    
    // Header
    html += "<div class='header'>";
    html += "<h1>"; html += String(UI_PRODUCT_LINE); html += "</h1>";
    html += "<div class='version'>Version " + version_info + " • " + hostname + "</div>";
    html += "</div>";
    
    // Navigation tabs
    html += "<div class='nav-tabs'>";
    html += "<button type='button' class='nav-tab active' data-tab='status' onclick='showTab(\"status\")'>Status</button>";
    html += "<button type='button' class='nav-tab' data-tab='settings' onclick='showTab(\"settings\")'>Settings</button>";
    html += "<button type='button' class='nav-tab' data-tab='schedule' onclick='showTab(\"schedule\")'>Schedule</button>";
    html += "<button type='button' class='nav-tab' data-tab='weather' onclick='showTab(\"weather\")'>Weather</button>";
    html += "<button type='button' class='nav-tab' data-tab='system' onclick='showTab(\"system\")'>System</button>";
    html += "</div>";
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

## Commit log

2025-12-09 add relay common and split c input
    [ESP32-DevKitC3-Simple-Thermostat-PCB-CuBottom.gbr, ESP32-DevKitC3-Simple-Thermostat-PCB-CuIn1.gbr, ESP32-DevKitC3-Simple-Thermostat-PCB-CuIn2.gbr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]
2025-12-13 Add 3D printable case design with screw fastening
    - Two-part case: back (wall mount) + front (display side)
    - Case dimensions: 149x105.5mm, accommodates 133x89.5mm PCB
    - Back case: 30.1mm height, 20mm ESP32 clearance, keyhole wall mounts, screw bosses
    - Front case: 17.1mm height, 13mm PCB standoffs, countersunk screw holes
    - 4x M2.5 countersunk screws secure halves (7mm corner inset, 3-7mm taper)
    - Display cutout 50x68mm (rotated 90°), LDR + AHT20 sensor holes
    - Seating lip prevents full nesting, ventilation on all edges
    - Includes OpenSCAD sources, STL files, generation script, assembly docs
    [back_case_wall.scad, front_case_display.scad, test_coords.scad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]
2025-12-13 Add work-in-progress notice to case documentation
2025-12-13 Update root README with 3D printable case section
2025-12-13 Update PCB design and regenerate gerber files
    [ESP32-DevKitC3-Simple-Thermostat-PCB-CuBottom.gbr, ESP32-DevKitC3-Simple-Thermostat-PCB-CuIn1.gbr, ESP32-DevKitC3-Simple-Thermostat-PCB-CuIn2.gbr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]
2025-12-13 Update PCB design with latest revisions
    [CPL-ESP32-DevKitC3-Simple-Thermostat-PCB.csv, ESP32-DevKitC3-Simple-Thermostat-PCB-CuBottom.gbr, ESP32-DevKitC3-Simple-Thermostat-PCB-CuIn1.gbr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]
2025-12-15 feat: create centralized hardware pin abstraction layer
    - Add include/HardwarePins.h with all GPIO pin definitions
    - Document serial port architecture (USB CDC vs UART bridge)
    - Define relay outputs, LEDs, sensors, and peripheral pins
    - Replace 80+ pin variable references with macros in Main-Thermostat.cpp
    - Remove duplicate pin definitions from Main-Thermostat.cpp
    - Validate pin assignments against ESP32-S3-DevKitC-1 V1.1 specs
    - Add comprehensive hardware notes and pin conflict documentation
    Benefits:
    - Single source of truth for all hardware configuration
    - Easier PCB modifications and hardware changes
    - Clear documentation of UART0/1/2 and USB CDC architecture
    - No compilation errors, a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
    [HardwarePins.h]
2025-12-15 feat: add multi-sensor support with auto-detection (AHT20, DHT11, BME280)
    - Implement sensor abstraction layer for three temperature/humidity sensors
    - Add auto-detection logic: tries I2C sensors first, falls back to DHT11
    - Support BME280 barometric pressure measurement and display
    - Update setup() to detect and initialize correct sensor at boot
    - Refactor sensorTaskFunction() to use unified read API
    - Add pressure display on TFT when BME280 detected
    - Add MQTT publishing for barometric pressure
    - Add Home Assistant auto-discovery for pressure sensor
    - Update HardwarePins.h with multi-sensor pin usage documentation
    - Add DHT sensor library and Adafruit BME280 library dependencies
    Hardware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
    [HardwarePins.h]
2025-12-19 Bump version to 1.3.7 - Fix fan relay oscillation bug when manual 'on' mode conflicts with HVAC fan control. Update schermatic and PCB for missing trace.
    [CPL-ESP32-DevKitC3-Simple-Thermostat-PCB.csv, ESP32-DevKitC3-Simple-Thermostat-PCB-CuBottom.gbr, ESP32-DevKitC3-Simple-Thermostat-PCB-CuIn1.gbr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]
2025-12-22 Fix thermostat naming as this project shares code with my other projects.
    [WebPages.h]
2025-12-22 Add case files
    [front_case_display.3mf, front_case_display.stl]
2025-12-24 Add System Info submenu and fix settings menu layout
    - Add System Info page showing network status, hardware info, and uptime
    - Fix settings menu layout overflow by switching to 2-column button grid
    - Add brightness and timing constants to HardwarePins.h for code unification
    - Update case design files with FreeCAD scripts and outputs
    - All buttons now fit within 240px display height constraint
    [back_case_wall.scad, back_case_wall_freecad.FCStd, back_case_wall_freecad.step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]
2025-12-24 Improved back case hook geometry and STL quality
    - Adjusted snap hook height from 4.0mm to 6.5mm for proper engagement (5mm wall-to-barb spacing)
    - Increased barb height from 1.2mm to 1.5mm for better catch
    - Increased hook overhang from 0.8mm to 1.3mm for stronger grip
    - Added removable 0.6mm vertical support columns under hook overhangs for printability
    - Support columns positioned at tab edges, spanning full overhang depth
    - Improved STL mesh quality: LinearDeflection 0.01, AngularDeflection 30° (FreeCAD standard)
    - Applied same mesh quality improvements to front case
    - Removed obsolete OpenSCAD files and legacy STL files
    - Cleaned up old assembly documentation files
    [back_case_wall.scad, back_case_wall_freecad.FCStd, back_case_wall_freecad.step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]
2025-12-24 Improved sensor protection and case refinements
    - Added thin lattice mesh (1/3 face thickness) across temp sensor opening for protection
    - Adjusted mesh depth to be easily cutable while providing default debris protection
    - Fixed display opening fillet to apply per-edge (4/111 edges) for touch sensitivity
    - Silenced display fillet failures on complex geometry edges
    - Added PCB STL file for reference alignment
    - All case features now generate cleanly without errors
    [back_case_wall_freecad.FCStd, back_case_wall_freecad.step, back_case_wall_freecad.stl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]
2025-12-24 Improved STL export quality to highest settings
    - Reduced LinearDeflection from 0.01 to 0.005 (5 microns) for very fine detail capture
    - Reduced AngularDeflection from 30° to 10° for much smoother curves and rounded edges
    - Applied to both front and back case generation scripts
    - Regenerated all case files with premium quality mesh settings
    - Optimal for high-resolution 3D printing
    [back_case_wall_freecad.FCStd, back_case_wall_freecad.step, back_case_wall_freecad.stl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]
2025-12-26 Add alignment tabs and fine-tune component positioning
    - Added L-shaped corner alignment tabs to back case (2mm arms, full wall height)
    - Tabs extend 3mm above wall top and from bottom for easy 3D printing
    - Moved LDR sensor 1.5mm to the right for better alignment
    - Moved display hole 5.6mm to the right on front case
    - All case files regenerated with premium quality STL settings
    [back_case_wall_freecad.FCStd, back_case_wall_freecad.step, back_case_wall_freecad.stl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]
2025-12-27 Back case: thinner snap-hook tabs\n\n- Reduced "snap_hook_thickness" from 3.0mm to 2.0mm\n- Regenerated back case artifacts (STEP/STL/FCStd)
    [back_case_wall_freecad.FCStd, back_case_wall_freecad.step, back_case_wall_freecad.stl]
2025-12-27 Update front case and add parts lists
    [back_case_wall_freecad.FCStd, back_case_wall_freecad.step, back_case_wall_freecad.stl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]
2026-01-01 Fix MQTT temperature decimal precision and add firmware organization tools
    - Fix current temperature MQTT publish to use snprintf for consistent 1 decimal place formatting
    - Add build.sh wrapper script for automated firmware organization after builds
    - Add organize_firmware.sh to copy firmware files to timestamped directories
    - Add VS Code tasks for build + organize workflow
    - Create flash.sh script in each build directory for easy ELF flashing with esptool
2026-01-01 Fix device reboot functionality and Home Assistant temperature precision
    - Add systemRebootInProgress flag to prevent multiple reboot requests
    - Update /reboot endpoint to use Connection: close header (like OTA firmware update)
    - Implement proper reboot page with 30-second wait before polling /version
    - Browser automatically redirects to home page once device comes back online
    - Add precision setting to Home Assistant discovery config for temperature display
    - This prevents the continuous reboot loop that occurred when the reboot page kept making requests
2026-01-01 v1.3.9: Comprehensive debug logging to web console + fan cycle debugging
    - Convert all 400+ Serial debug calls to debugLog() for web console visibility
    - Increase debug buffer from 8KB to 32KB for more history
    - Add debugLog declaration to Weather.h for cross-module access
    - Enhanced fan cycle logging: mode changes, cycle state, timing
    - Boot messages now appear at end of setup after preferences load
    - All sensor, schedule, weather, HVAC, and motion data now in web debug console
2026-01-01 v1.3.9: Add heat pump reversing valve support and multi-variant builds
    Features:
    - Heat pump reversing valve support (mutually exclusive with stage 2 heating)
    - Web interface checkbox with JavaScript mutual exclusion
    - Conditional relay control in heating/cooling activation
    - Dynamic status page display based on enabled features
    - Support for ESP32-S3 variants: 4MB, 8MB, 16MB, 32MB flash
    - Multi-variant build system with automatic firmware organization
    Improvements:
    - Removed 1-hour fan cycle boot delay
    - Updated build scripts to support variant-specific builds
    - Added partition tables for all flash sizes
    - Enhanced organize_firmware.sh to handle multiple variants
    - Status page shows only e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
    [default_32mb.csv, default_4mb.csv, default_8mb.csv]
2026-01-03 Fix MQTT Home Assistant integration and WiFi initialization
    - Fixed MQTT climate entity showing 'unknown' state in Home Assistant
    * Removed global value_template that was breaking fan_mode parsing
    * Set climate entity name to empty string to avoid duplicate hostname display
    * Moved MQTT state tracking from static to module-level variables
    * Added resetMQTTDataCache() to force state republish on reconnect
    - Fixed critical WiFi TCP/IP stack initialization bug
    * Added WiFi.mode(WIFI_STA) before any WiFi operations
    * Prevents crash when device has no WiFi credentials (factory reset scenario)
    * Ensures WiFi.status() calls in loop() don't access uninitialized stack
    - Commented out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
2026-01-14 Fix schedule.
    [default_4mb.csv]
2026-01-16 Fix schedule override persistence and timezone handling
    - Clear stale override on boot to prevent indefinite override state
    - Add tzset() call to checkSchedule() to ensure timezone is always applied
    - Trigger and persist schedule override on manual (+/-), MQTT, and web temperature changes
    - Add debug logging for schedule period and current time
    - Fix issue where display showed manual setpoint instead of scheduled setpoint
2026-01-16 Add BME680 sensor support (HiLetgo 3-01-1780 5V I2C board) NEEDS TESTING./build.sh all!
    - Add BME680 library dependency (Adafruit BME680 Library @^2.0.4)
    - Add SENSOR_BME680 enum and sensor instance with gas/air quality tracking
    - Implement BME680 initialization with optimal sampling configuration
    - Add temperature/humidity/pressure/gas resistance reading with I2C mutex protection
    - Calculate approximate air quality index (0-500) from gas resistance
    - Update sensor auto-detection to check BME680 first (before BME280)
    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
2026-01-21 feat: Enhanced project maintenance and fixed duplicate code
    - Updated .gitignore with comprehensive build artifact exclusions
    * Added .pio directory and build artifacts
    * Added firmware build directories pattern
    * Added KiCad lock files and Python cache
    * Added OS-specific temp files
    - Removed duplicate handleScheduleSubmit() function in WebInterface.h
    * Fixed copy-paste error that created identical duplicate function
    * Cleaned up JavaScript code structure
    - Added comprehensive documentation files
    * SAVE_FIXES_IMPLEMENTED.md - Details atomic save fixes with verification
    * SAVE_MECHANISM_ANALYSIS.md - Analysis of intermittent save issues
    * STAGE2_HEATING_FIXES_IMPLEMENTED.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
    [WebPages.h]
2026-01-23 Add MQTT schedule modification with JSON payload support
    - Implemented hybrid MQTT schedule control (option C)
    - Added schedule/set topic for JSON-based parameter updates
    - Added 7 separate schedule sensors (one per day) for Home Assistant
    - Published topics: {hostname}/schedule/monday through /sunday
    - JSON format supports partial updates (change only specified fields)
    - Validates day (0-6), period (day/night), hour (0-23), minute (0-59)
    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
2026-01-24 Release v1.4.001: Bidirectional MQTT schedule synchronization
    - Complete bidirectional MQTT schedule sync (device ↔ Home Assistant)
    - Multi-thermostat support with unlimited device scaling
    - Fixed day index off-by-one bug (MQTT Monday=0, firmware Sunday=0)
    - 77 helpers per thermostat (14 times, 42 temps, 21 booleans)
    - 1 centralized inbound automation for all devices
    - 77 outbound automations per device (auto-generated)
    - Automatic hostname normalization (CamelCase-With-Hyphens ↔ lowercase_underscores)
    - Proper JSON boolean handling and time parsing
    - Complete documentation (3,406+ lines across 6 files)
    - Quick-start guide (5-minute setup)
    - Comprehensive troubleshooting guide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
    [WebPages.h]
2026-01-25 Update case design: back case with continuous perimeter lip and single gang mounting, front case with simplified latch holes
    [back_case_wall_freecad.FCStd, back_case_wall_freecad.step, back_case_wall_freecad.stl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]
2026-01-27 Cleanup old files.
    [BOM-ESP32-DevKitC3-Simple-Thermostat-PCB.csv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]
2026-01-30 Update sensor box for better air flow and cleanup files.
    [front_case_display_freecad.FCStd, front_case_display_freecad.step, front_case_display_freecad.stl]
2026-02-02 Move case display opening 2.5mm to the right for better alignment.
    [back_case_wall_freecad.FCStd, back_case_wall_freecad.step, front_case_display_freecad.FCStd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]
2026-02-06 Reduce back case wall height to slim down case and reduce the amount of material used in production.
    [back_case_wall_freecad.FCStd, back_case_wall_freecad.step, back_case_wall_freecad.stl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]
2026-02-09 Minor case adjustment for clearance. File cleanup.
    [front_case_display_freecad.FCStd, front_case_display_freecad.step, front_case_display_freecad.stl]
2026-02-22 v1.4.009: Touch calibration system, enhanced fan control, dual hydronic sensors
    Major Features:
    - Touch Screen Calibration System: On-device calibration via System Info page
    - Calibrate button: Interactive touch calibration with corner-tap routine
    - Clear Cal button: Reset calibration and reboot to defaults
    - Non-blocking startup with hardware-tested default values (426, 3526, 248, 3417, 7)
    - Debug logging for calibration values in boot log
    - Enhanced Fan Control: Fan forced OFF during hydronic lockout
    - Prevents cold air circulation when hydronic heating unavailable
    - Checks added to both handleFanControl() and controlFanSchedule()
    - Dual Hydronic Sensor Support: Display suppl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
    [HardwarePins.h, SettingsUI.h, WebPages.h]
2026-02-25 Update PCB and remove extra 3.3v netlist.
    [BOM-ESP32-DevKitC3-Simple-Thermostat-PCB.csv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]
2026-03-08 Fix DS18B20 sensors on GPIO41 (ESP32-S3) - v1.4.012
    ROOT CAUSE:
    OneWire library v2.3.7 has hardcoded 'pin <= 33' check for output mode.
    This prevents GPIO41 (and other pins >33) from working on ESP32-S3.
    SOLUTION:
    - Patched OneWire library to support ESP32-S3 GPIO34-48 as outputs
    - Disabled USB Serial JTAG peripheral to reclaim GPIO41
    - Re-force GPIO configuration after OneWire initialization
    CHANGES:
    - src/Main-Thermostat.cpp: USB JTAG disable + GPIO41 init sequence
    - .pio/libdeps/*/OneWire/util/OneWire_direct_gpio.h: ESP32-S3 patch
    - patch_onewire_esp32s3.sh: Automated patch script for fresh builds
    - ONEWIRE_ESP32S3_PATCH.md: Complete documentation of the fix
    VERIFIED:
    - Both DS18B20 se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
2026-03-09 Add DS18B20 sensors to Home Assistant MQTT - v1.4.013
    - Added MQTT auto-discovery for DS18B20 supply temperature sensor
    - Added MQTT auto-discovery for DS18B20 return temperature sensor
    - Both sensors appear as separate temperature entities in Home Assistant
    - Sensors linked to main thermostat device
    - Discovery republished after DS18B20 initialization to ensure presence detection
    - Temperature values published in Fahrenheit with 0.1°F threshold
    - State topics: <hostname>/ds18b20_supply_temperature and ds18b20_return_temperature
    FIX:
    - Discovery now happens AFTER DS18B20 sensors are initialized
    - Added debug logging to show sensor presence during discovery
    - Both sensor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
2026-03-09 Display/layout cleanup and hydronic lockout fan stability - v1.4.014
    - Move setpoint 20px left and adjust matching clear regions
    - Re-space right-side telemetry with even vertical spacing
    - Move BOILER LOCKOUT banner above setpoint (out of weather/status areas)
    - Show lockout banner only in HEAT mode; clear in OFF/COOL/AUTO
    - Fix fan relay chatter during hydronic lockout by blocking fan-ON writes while lockout safety is active
    - Keep lockout behavior consistent across controlRelays/turnOffAllRelays/activateHeating/activateCooling
2026-04-30 Add SHT45 sensor, update display, add code for backup heat.
2026-05-02 Fix state 2 heating issue
    [ESP32-DevKitC3-Simple-Thermostat-PCB_v3.kicad_sch]
2026-05-05 PCB v3: replace relays/driver, add 2.8"/4.0" display support headers; firmware fixes
    - PCB v3 KiCad design: replaced relay components and relay driver, added
    connector footprints for 2.8" and 4.0" TFT displays alongside existing 3.2"
    - New gerbers and JLCPCB production files (BOM, CPL, GERBER zip) for v3
    - Remove old v2 gerbers (superseded by v3)
    - Firmware builds updated to 20260503 (N8/N16/N32)
    - Firmware fixes: debug page JSON overflow, stage 2 heating not escalating,
    right-side sensor text size increased
    [BOM-ESP32-DevKitC3-Simple-Thermostat-PCB_v3.csv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]
2026-05-13 Release v1.5.001: US/EU mode, EU humidity logic, display fixes, docs update
    [BOM-ESP32-DevKitC3-Simple-Thermostat-PCB_v3.csv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]
2026-05-15 Update images for v3 PCB.
    [BOM-ESP32-DevKitC3-Simple-Thermostat-PCB_v3.csv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]
